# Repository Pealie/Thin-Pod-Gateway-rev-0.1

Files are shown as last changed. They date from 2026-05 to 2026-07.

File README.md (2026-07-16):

# Thin-Pod Gateway rev 0.1

<p align="left">
  <a href="https://certification.oshwa.org/uk000092.html">
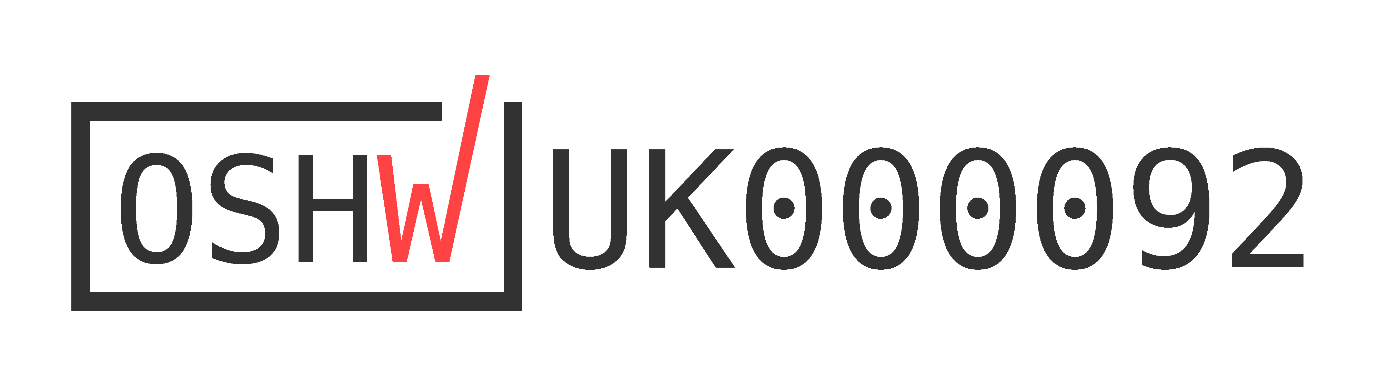
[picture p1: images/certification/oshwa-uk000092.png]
Open Source Hardware Association certification mark: UK000092
    
  </a>
</p>
<p align="left">
  <strong>OSHWA Certified Open Source Hardware · UK000092</strong><br>
  Certified 16 July 2026 · <a href="https://certification.oshwa.org/uk000092.html">View certification record</a>
</p>

**Open-hardware carrier PCB for Thin-Pod UWB telemetry, host supervision and onward-networking experiments**

## Status at 16 July 2026

Thin-Pod Gateway rev 0.1 is certified by the Open Source Hardware Association under UID [`UK000092`](https://certification.oshwa.org/uk000092.html). The certified public baseline is the `v0.1` release, with post-certification status and directory references maintained on `main`.

The manufactured `rev 0.1f` carrier board has completed stable powered bring-up with the STM32 NUCLEO-N657X0-Q and Gateway-side DWM3001-CDK. The repository records:

- verified 5 V and 3.3 V distribution and common-ground continuity;
- corrected marginal DWM header solder joints affecting ground and RESET;
- valid RESET and READY rail levels;
- repeatable bidirectional NUCLEO-to-DWM `TPHIP GET_CAPABILITIES` exchange;
- physical DW3110 identity and initialisation on Gateway and Node DWM3001-CDKs;
- a matched 20-frame Gateway-to-Node UWB exchange;
- published KiCad project, schematic and PCB source for revision `0.1`;
- published Gerber, drill and fabrication ZIP outputs;
- clean schematic ERC and PCB DRC reports;
- recorded Gerber and drill inspection;
- recorded symbol and footprint provenance;
- a reconciled design-basis BOM with builder-selected compatible assembly hardware.

## Relationship to the certified Thin-Pod node

The companion [`Pealie/Thin-Pod-rev0.1`](https://github.com/Pealie/Thin-Pod-rev0.1) sensor-node carrier PCB is separately certified as OSHWA Open Source Hardware, UID [`UK000091`](https://certification.oshwa.org/uk000091.html), certified 28 May 2026.

The two certifications describe distinct hardware artefacts:

| Hardware artefact | OSHWA UID | Certification date |
|---|---|---|
| Thin-Pod rev 0.1 sensor-node carrier PCB | [`UK000091`](https://certification.oshwa.org/uk000091.html) | 28 May 2026 |
| Thin-Pod Gateway rev 0.1 carrier PCB | [`UK000092`](https://certification.oshwa.org/uk000092.html) | 16 July 2026 |

The node UID applies only to the sensor-node carrier PCB. The Gateway UID applies only to the Gateway carrier PCB and its declared certification package.

## Hardware scope

Thin-Pod Gateway rev 0.1 is a two-layer carrier PCB connecting:

| Reference | Module | Role |
|---|---|---|
| `U1` | STMicroelectronics `NUCLEO-N657X0-Q` | Main host and prospective analysis supervisor |
| `U2` | Qorvo `DWM3001-CDK` | Gateway-side UWB subsystem |
| `U3` | Seeed Studio `XIAO ESP32-C6` | Optional onward-networking subsystem |

The creator-controlled open-hardware contribution is the carrier PCB: power distribution, local decoupling, pull-ups, module interfaces, SPI/control routing, test access, mounting geometry, editable source and derived fabrication outputs.

The commercial modules remain third-party products whose internal designs are outside the Gateway open-hardware claim.

## Verified evidence

| Milestone | Result | Evidence |
|---|---|---|
| Stable carrier-board bring-up | PASS | [`docs/bringup/Gateway_rev0_1_Hardware_Bringup_Note.md`](docs/bringup/Gateway_rev0_1_Hardware_Bringup_Note.md) |
| NUCLEO-to-DWM physical host interface | PASS | [`docs/firmware/TPHIP_GET_CAPABILITIES_Physical_Validation.md`](docs/firmware/TPHIP_GET_CAPABILITIES_Physical_Validation.md) |
| DW3110 identity and initialisation | PASS | [`docs/validation/DW3110_Physical_Identity_Initialisation_Validation.md`](docs/validation/DW3110_Physical_Identity_Initialisation_Validation.md) |
| Matched 20-frame one-way RF exchange | PASS | [`docs/validation/DW3110_One_Way_RF_Exchange_Validation.md`](docs/validation/DW3110_One_Way_RF_Exchange_Validation.md) |
| Native KiCad source | PUBLISHED | [`hardware/source/README.md`](hardware/source/README.md) |
| Fabrication package and hashes | PUBLISHED | [`hardware/fabrication/RELEASE-MANIFEST.md`](hardware/fabrication/RELEASE-MANIFEST.md) |
| Schematic ERC | PASS | [`docs/validation/cad/rev0.1/Thin-Pod_Gateway_rev0.1_ERC.rpt`](docs/validation/cad/rev0.1/Thin-Pod_Gateway_rev0.1_ERC.rpt) |
| PCB DRC | PASS | [`docs/validation/cad/rev0.1/Thin-Pod_Gateway_rev0.1_DRC.rpt`](docs/validation/cad/rev0.1/Thin-Pod_Gateway_rev0.1_DRC.rpt) |
| Gerber and drill inspection | PASS | [`docs/validation/cad/rev0.1/Gerber_Drill_Inspection_Record.md`](docs/validation/cad/rev0.1/Gerber_Drill_Inspection_Record.md) |
| Symbol and footprint provenance | RECORDED | [`docs/footprint-provenance.md`](docs/footprint-provenance.md) |
| Assembly BOM | RECONCILED | [`hardware/bom/Thin-Pod_Gateway_rev0.1_BOM.md`](hardware/bom/Thin-Pod_Gateway_rev0.1_BOM.md) |

## Design and fabrication identity

The manufactured board may carry `rev 0.1f`. This is retained as the physical fabrication-build identity within the certified Thin-Pod Gateway rev 0.1 release record.

Published native source:

```text
hardware/source/kicad/rev0.1/
```

Published manufacturing outputs:

```text
hardware/fabrication/rev0.1/
```

The release Gerber job records project revision `0.1`. The regenerated outputs preserve the intended electrical connectivity, board outline, mounting geometry, module-interface positions, test-point arrangement and layer content of the manufactured rev 0.1f carrier.

## Assembly interface treatment

Builder-selected pin headers and/or socket strips compatible with the NUCLEO-N657X0-Q ST Morpho interfaces, DWM3001-CDK J10 interface, and optional XIAO ESP32-C6 carrier footprint are suitable for assembly. Header brand, plating, socket style and standoff selection are assembly choices outside the carrier-PCB certification scope.

## Licences

| Material | Licence |
|---|---|
| Creator-designed hardware source and derived fabrication outputs | `CERN-OHL-W-2.0` |
| Project-authored firmware, scripts and software examples | `MIT` |
| Creator-authored documentation and owned images | `CC-BY-4.0` |
| Third-party modules, software and CAD | Original applicable terms |

These are the licence selections recorded for OSHWA certification UID `UK000092`.

See [`LICENSE.md`](LICENSE.md), [`LICENSE-HARDWARE.md`](LICENSE-HARDWARE.md), [`LICENSE-SOFTWARE.md`](LICENSE-SOFTWARE.md), [`LICENSE-DOCUMENTATION.md`](LICENSE-DOCUMENTATION.md), [`THIRD_PARTY_NOTICES.md`](THIRD_PARTY_NOTICES.md) and [`docs/footprint-provenance.md`](docs/footprint-provenance.md).

## OSHWA certification record

| Item | Record |
|---|---|
| Project | Thin-Pod Gateway |
| Hardware release | rev 0.1 |
| OSHWA UID | [`UK000092`](https://certification.oshwa.org/uk000092.html) |
| Certification date | 16 July 2026 |
| Canonical release tag | `v0.1` |
| Public application record | [`oshwa/application-record.md`](oshwa/application-record.md) |
| Certification scope | [`docs/certification-scope.md`](docs/certification-scope.md) |
| Certification completion checklist | [`docs/oshwa/Gateway_OSHWA_Preparation_Checklist.md`](docs/oshwa/Gateway_OSHWA_Preparation_Checklist.md) |

The OSHWA certification confirms the declared open-source hardware, software and documentation licensing position. It does not constitute EMC, radio, electrical-safety, CE, UKCA, industrial-performance or product-safety approval.

## Current limitations

The release does not claim Node-to-Gateway vibration-window transport, ranging, field-qualified RF performance, calibrated transmit power, antenna/coexistence performance, authenticated radio records, secure boot enforcement, production OTA, Gateway DSP/TinyML performance, EMC, radio, electrical-safety, CE or UKCA compliance.

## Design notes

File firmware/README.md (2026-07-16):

# Thin-Pod Firmware Workspace

**Project context:** Thin-Pod rev 0.1 sensor node and Thin-Pod Gateway rev 0.1<br>
**Firmware workspace status:** Prepared for initial acquisition and host-interface experiments; no completed firmware implementation claimed<br>
**Document date:** 27 May 2026<br>
**Certification status update (16 July 2026):** Thin-Pod rev 0.1 is OSHWA-certified as `UK000091`; Thin-Pod Gateway rev 0.1 is independently OSHWA-certified as `UK000092`

## Purpose

This directory is the firmware-development workspace for proving the first Thin-Pod measurement-data path:

```text
external ADXL1005 analogue vibration signal
        ↓
node-side DWM3001-CDK / nRF52833 firmware
bounded raw-window acquisition and later UWB transmission
        ↓
Gateway-side DWM3001-CDK / nRF52833 firmware
communications termination, validation and host presentation
        ↓
STM32 NUCLEO-N657X0-Q firmware
record ingestion, preservation, DSP and later TinyML evaluation
```

The immediate purpose of the firmware work is not to claim a complete condition-monitoring product. It is to remove the two largest implementation uncertainties:

1. whether the existing Thin-Pod node can create a useful digital raw window from the external ADXL1005 signal; and
2. whether the Gateway-side Qorvo subsystem can expose a complete validated record to the NUCLEO through the firmware-defined host interface intended by Gateway rev 0.1.

## Relationship to hardware releases and OSHWA scope

The firmware workspace must not blur the hardware certification boundaries.

|Hardware artefact|Current position|Firmware relationship|
|-|-|-|
|**Thin-Pod rev 0.1** sensor-node carrier PCB|OSHWA-certified as `UK000091`|This workspace may test firmware using that hardware; the node certification boundary remains unchanged|
|**Thin-Pod Gateway rev 0.1** carrier PCB|OSHWA-certified as `UK000092`|Project-authored firmware and software in this repository are declared under MIT within the Gateway certification record; external SDKs and vendor firmware retain their own terms|
|**Gateway rev 0.3** SMT/chip-down direction|Deferred|Not implemented in this workspace at present|

The Gateway hardware, software and documentation categories remain separately licensed. Project-authored firmware and software are covered by `LICENSE-SOFTWARE.md` under MIT, matching the software licence declared for UID `UK000092`. External SDKs, Zephyr components and vendor firmware remain under their original terms.

## Architectural responsibility split

|Firmware area|Hardware target|Immediate responsibility|Deliberately deferred responsibility|
|-|-|-|-|
|[`node-dwm/`](node-dwm/)|Node-side Qorvo DWM3001-CDK / nRF52833 connected to Thin-Pod|SAADC characterisation of external ADXL1005 path and bounded raw-record creation|Full event-trigger logic, multi-node policy and production-grade radio behaviour|
|[`gateway-dwm/`](gateway-dwm/)|Gateway-side Qorvo DWM3001-CDK / nRF52833|Present status and a golden synthetic record to the NUCLEO through the proposed host protocol|Full UWB reception until wired host hand-off succeeds|
|[`nucleo-host/`](nucleo-host/)|STM32 NUCLEO-N657X0-Q|Read, validate and preserve complete raw records; later perform minimal DSP|TinyML, cloud/backhaul reporting and complex user interface|
|[`test-vectors/`](test-vectors/)|Shared development assets|Provide deterministic record bytes and CRC reference behaviour|Dataset/training material|

The project’s governing data-path principle is:

```text
qualified raw measurement windows from the Pod;
validated UWB/host transfer through the DWM3001 subsystem;
features and later models on the Gateway.
```

## Directory structure

```text
firmware/
├── README.md
│
├── node-dwm/
│   ├── README.md
│   └── acquisition-characterisation/
│       └── README.md
│
├── gateway-dwm/
│   ├── README.md
│   └── tphip-golden-record/
│       └── README.md
│
├── nucleo-host/
│   ├── README.md
│   └── tphip-reader/
│       └── README.md
│
└── test-vectors/
    ├── README.md
    ├── golden-window-v1.bin              # to be generated from the reference script
    ├── golden-window-v1-metadata.md      # to be added with generated vector
    └── crc-reference.py                  # to be added as executable vector generator/checker
```

The README files define the intended implementation and evidence structure. The binary vector and reference script are next implementation assets; they are not implied to exist merely because their target paths are documented here.

## Controlling architecture documents

These firmware folders implement the architecture described in the repository documentation:

|Document|Controls|
|-|-|
|[`../docs/node-acquisition-and-sampling-contract.md`](../docs/node-acquisition-and-sampling-contract.md)|ADC qualification, sample-rate/bandwidth position and the later dedicated-ADC decision gate|
|[`../docs/dwm-to-nucleo-host-interface-protocol.md`](../docs/dwm-to-nucleo-host-interface-protocol.md)|`TPHIP-1` request/response, record layout, golden vector and ownership behaviour|
|[`../docs/data-path-flow-control-and-buffering.md`](../docs/data-path-flow-control-and-buffering.md)|Credit-based admission, DWM and NUCLEO queue policy and overrun prevention|
|[`../docs/window-throughput-and-airtime-budget.md`](../docs/window-throughput-and-airtime-budget.md)|Calculated record/transfer budget and later measurement tables|
|[`../docs/data-path-fault-injection-and-recovery-tests.md`](../docs/data-path-fault-injection-and-recovery-tests.md)|Failure tests needed to demonstrate visible error handling|
|[`../docs/measurement-record-and-provenance-model.md`](../docs/measurement-record-and-provenance-model.md)|Traceability from raw record through DSP and later TinyML|
|[`../docs/system-interface-control-document.md`](../docs/system-interface-control-document.md)|Node/Gateway responsibility boundary|

## First implementation sequence

The firmware should be developed in an evidence-first order.

|Phase|Target|Work|Completion evidence|
|-:|-|-|-|
|F0|Shared test assets|Generate the golden 4160-byte `SYNTHETIC\_WINDOW` record and CRC checker|Binary vector, metadata and deterministic script|
|F1|Gateway DWM|Implement minimal `TPHIP-1` capabilities/status presentation|Repeatable host-readable status record|
|F2|NUCLEO host|Implement SPI/IRQ reader for capabilities/status|Stable protocol discovery and status logging|
|F3|Gateway DWM + NUCLEO|Transfer the golden record over the wired host route|Exact reconstructed binary and CRC match|
|F4|Gateway DWM + NUCLEO|Withhold acknowledgement and exercise credit policy|Record-retention and no-overwrite evidence|
|F5|Node DWM|Configure SAADC and capture external ADXL1005 characterisation windows|Raw rest and mechanical-response records, marked uncalibrated|
|F6|Qorvo node/Gateway subsystems|Transfer a known record over UWB and deliver it into NUCLEO memory|RF-to-host record with integrity evidence|
|F7|Full node-to-Gateway chain|Deliver an actual ADXL1005-derived raw window|Accepted measurement record plus provenance|
|F8|NUCLEO|Compute RMS and peak, followed later by further DSP|Results linked to retained raw input|
|F9|Later|Consider TinyML only after repeatable datasets exist|Versioned model work linked to provenance|

Node acquisition and wired host-interface work can proceed in parallel where hardware availability permits. Neither requires the Gateway PCB to have arrived before useful preparatory progress begins.

## Initial record and buffer policy

The commissioning record defined by `TPHIP-1` is:

|Quantity|Initial value|
|-|-:|
|Message type|`SYNTHETIC\_WINDOW`, later `VIBRATION\_WINDOW`|
|Sample representation|Signed 16-bit little-endian|
|Samples per record|2048|
|Raw payload bytes|4096|
|Fixed header bytes|64|
|Complete record bytes|4160|
|Golden vector CRC-32|`0x0B1D48B2`|
|Gateway DWM complete-record slots|2 initially|
|NUCLEO raw-record slots|32 initially|
|Commissioning admission|One complete window at a time|

The 25.6 ksample/s value in the golden synthetic record is protocol metadata for deterministic testing; it is not a claim that a 25.6 ksample/s acquisition mode preserves the full ADXL1005 analogue bandwidth. Actual node acquisition requires the separate qualification process described in `node-acquisition-and-sampling-contract.md`.

## Evidence and record discipline

Each firmware experiment should produce identifiable evidence rather than transient console output.

Suggested working evidence pattern:

```text
verification/
├── firmware/
│   ├── node-acquisition/
│   ├── tphip-host-interface/
│   ├── uwb-transport/
│   └── dsp/
└── datasets/
    └── <session-id>/
        ├── session-manifest.json
        ├── raw/
        ├── ingestion/
        ├── dsp/
        └── evidence/
```

Every completed experiment should record the hardware revision/build, fitted modules, firmware build identities, protocol version, test configuration, raw record or exact test vector, integrity result and explicit pass/fail conclusion.

## Firmware toolchain position

The precise firmware toolchains and SDK/project templates should be recorded when the first projects are created. The likely development boundaries are:

|Target|Expected environment to confirm and record|
|-|-|
|DWM3001-CDK / DWM3001C nRF52833|Qorvo-supported DWM3001CDK/DWM3001C firmware environment and Nordic-compatible development/debug route|
|STM32 NUCLEO-N657X0-Q|STM32Cube ecosystem and NUCLEO-supported debugging/programming route|
|Shared test vector generation|Python reference tooling used only for deterministic test/evidence generation|

No dependency version should be treated as fixed until the corresponding firmware project is created, built, flashed and recorded.

## Non-claims

This directory does not yet claim:

* working node-side digital capture of the external ADXL1005 signal;
* working DWM-to-NUCLEO SPI protocol implementation;
* successful UWB transmission of vibration records;
* proven DSP performance;
* TinyML inference or predictive-maintenance capability;
* production-qualified firmware behaviour; or
* expansion of either certified hardware boundary beyond the public records for UIDs `UK000091` and `UK000092`.

## Immediate next action

The best first firmware actions are:

```text
1. Generate and commit the TPHIP-1 golden record test assets.
2. Establish the node-side DWM3001-CDK programming/build route.
3. Capture the first external-ADXL1005-derived bounded ADC record.
4. Establish the Gateway-side DWM ↔ NUCLEO minimum status exchange off-board where practical.
5. Use the arriving Gateway PCB to replace temporary wiring only after the firmware boundary is already understood.
```

A credible outcome before the Gateway PCB arrives would be one digitised ADXL1005 characterisation window, a committed golden test vector and at least the beginnings of a deterministic DWM-to-NUCLEO host-interface proof.

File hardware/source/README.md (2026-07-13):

# Editable hardware source

This directory contains the preferred modifiable source for Thin-Pod Gateway rev 0.1.

## Published KiCad project

The release source is stored at:

```text
hardware/source/kicad/rev0.1/
├── Thin-Pod Gateway.kicad_pro
├── Thin-Pod Gateway.kicad_sch
└── Thin-Pod Gateway.kicad_pcb
```

The schematic and PCB title blocks identify the design revision as `0.1`. The KiCad project and PCB fabrication-output paths use the repository-relative location:

```text
../../../fabrication/rev0.1/
```

This removes the private Windows/OneDrive path that was present in the working project before publication. No schematic connectivity, component placement, routing or board geometry was intentionally changed by that portability correction.

## Source status

The native KiCad source and corresponding Gerber/drill release package were committed on 13 July 2026. The earlier missing-source publication gate is therefore cleared.

The remaining release-verification work is:

1. open the project in a clean KiCad 10 environment;
2. confirm that no unavailable private symbol or footprint library is required;
3. run schematic ERC and PCB DRC;
4. inspect the generated Gerbers and drill data in a Gerber viewer;
5. record symbol and footprint provenance;
6. reconcile the fitted BOM and module-header/socket choices;
7. freeze the validated source and fabrication package under a public release tag.

The editable KiCad project is the normative design source. Gerbers, drill data and the fabrication ZIP are derived convenience outputs.

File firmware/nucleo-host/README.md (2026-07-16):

# NUCLEO Host Firmware: Gateway Analytic Supervisor

**Firmware area:** `firmware/nucleo-host/`<br>
**Hardware target:** STM32 NUCLEO-N657X0-Q mounted on Thin-Pod Gateway rev 0.1<br>
**Status:** Ingestion architecture specified; implementation and physical Gateway verification pending<br>
**Document date:** 27 May 2026<br>
**Primary role:** Authoritative admission control, raw-window ownership and later analysis

## Purpose

This directory is for firmware running on the **STM32 NUCLEO-N657X0-Q** in the Thin-Pod Gateway architecture.

The NUCLEO is intended to act as the analytic supervisor, not as a direct controller of the internal DW3110 radio. Its immediate job is to prove that a complete record exposed by Gateway-side DWM firmware can be pulled into NUCLEO-owned memory, checked for integrity, preserved and acknowledged correctly.

```text
Gateway-side DWM firmware
    complete record queued and ready
        ↓  TPHIP-1 SPI/IRQ host interface
NUCLEO host firmware
    admission control and complete raw-window buffer ownership
        ↓
minimal DSP sanity checks
        ↓
later feature extraction and TinyML evaluation
```

## Responsibility boundary

| NUCLEO owns | NUCLEO does not initially own |
|---|---|
| Host-interface command/read behaviour | DW3110 radio timing/control internals |
| Available raw-record buffer capacity | Node-side ADC qualification |
| Credit granting and backpressure decision | Uncontrolled incoming UWB streaming |
| Host-side CRC/metadata acceptance | Gateway DWM’s internal UWB reassembly implementation |
| Retention and processing scheduling | Optional XIAO reporting as a prerequisite for measurement receipt |
| Later DSP and TinyML execution | Any early predictive-maintenance performance claim |

The NUCLEO is the **authoritative admission controller** because it knows whether preserved raw-window capacity remains available for incoming measurements and downstream processing.

## Relationship to hardware and certification

Thin-Pod Gateway rev 0.1 is OSHWA-certified as `UK000092`, separately from the Thin-Pod rev 0.1 node certified as `UK000091`. Thin-Pod-authored NUCLEO firmware is licensed under MIT through `LICENSE-SOFTWARE.md` and is part of the declared Gateway software record. The commercial NUCLEO hardware and vendor software remain outside the Thin-Pod licence grants.

The commercial NUCLEO board is included as a dependency of the open Gateway carrier PCB; it is not claimed as creator-authored open hardware.

## Controlling documents

| Document | NUCLEO firmware requirement |
|---|---|
| `../../docs/dwm-to-nucleo-host-interface-protocol.md` | Implement `TPHIP-1` host/master transactions and golden record |
| `../../docs/data-path-flow-control-and-buffering.md` | Implement raw-record pool, credits and high-water policy |
| `../../docs/data-path-fault-injection-and-recovery-tests.md` | Implement observable handling of corruption/backpressure/reset faults |
| `../../docs/window-throughput-and-airtime-budget.md` | Measure host-transfer/queue/DSP timing |
| `../../docs/measurement-record-and-provenance-model.md` | Attach record/build/status identity to evidence |
| `../../docs/node-acquisition-and-sampling-contract.md` | Interpret actual sensor records cautiously and correctly |

## Directory structure

```text
nucleo-host/
├── README.md
└── tphip-reader/
    └── README.md
```

Potential implementation expansion:

```text
nucleo-host/
├── README.md
├── tphip-reader/
│   ├── README.md
│   └── evidence/
├── app/
│   ├── host-interface/
│   ├── raw-window-pool/
│   ├── dsp/
│   └── logging/
├── tests/
└── build-notes/
```

## Initial physical interface role

Gateway rev 0.1 connects the NUCLEO-side intended host route as follows:

| NUCLEO function | Gateway net | Purpose |
|---|---|---|
| SPI5 clock output | `SPI5_SCK` | Clock DWM host-interface transactions |
| SPI5 MOSI output | `SPI5_MOSI` | Send requests and dummy bytes during reads |
| SPI5 MISO input | `SPI5_MISO` | Receive status/header/payload bytes |
| GPIO chip select | `DWM_CS` | Select Gateway DWM host endpoint |
| GPIO interrupt input | `DWM_IRQ` | Observe record/status-ready notification |
| GPIO reset output | `DWM_RESET` | Controlled subsystem reset/recovery |

The intended first protocol uses NUCLEO as SPI host/master. Settings such as SPI mode, initial frequency and IRQ polarity remain commissioning values until measured on the firmware endpoints and assembled/temporary-wired hardware.

## First NUCLEO objective

The first NUCLEO objective is:

> **Read and validate the fixed 4160-byte `TPHIP-1` golden synthetic record from Gateway-side DWM firmware, then acknowledge ownership only after the bytes and CRC are accepted.**

This establishes the key modular boundary before actual UWB or ADXL1005 data is introduced.

## Host-interface task model

The NUCLEO firmware should separate ingress from all slower processing.

```text
DWM_IRQ GPIO event
        ↓
minimal interrupt handler sets service flag
        ↓
high-priority TPHIP receive task reads status/record
        ↓
record copied into allocated raw-window slot
        ↓
CRC/metadata/sequence checked
        ↓
ACK_WINDOW or REJECT_WINDOW sent
        ↓
accepted record placed in VALID_RAW queue
        ↓
DSP task consumes later
```

The interrupt handler must not perform bulk SPI reads, FFT calculation, TinyML inference, long logging operations or optional network reporting.

## Initial raw-window pool

The initial NUCLEO buffer policy is:

| Quantity | Initial value |
|---|---:|
| Complete record bytes | 4160 |
| Raw-window slots | 32 |
| Raw-record memory allocation | 133,120 bytes |
| Protected reserve | 4 free slots |
| First admitted-window policy | One outstanding credit at a time |

### Raw-window slot states

```text
FREE
    available for admitted record

FILLING
    SPI transfer in progress

VALID_RAW
    integrity/metadata accepted; available to downstream consumer

PROCESSING
    DSP task currently consuming record

PROCESSED_RETAIN
    retained because it supports evidence/result

RELEASED
    returned deliberately to free pool

INVALID_QUARANTINED
    rejected record retained for diagnosis as policy permits
```

### High-water admission policy

| Slots in use | State | Credit action |
|---:|---|---|
| 0–15 | Normal | Permit credit according to scheduler |
| 16–23 | Elevated occupancy | Continue cautiously and log latency |
| 24–27 | High-water warning | Withhold or severely restrict new credits |
| 28–31 | Protected reserve | No new measurement credit |
| 32 | Full | Reject unsolicited arrival as fault; never overwrite a valid raw record |

## TPHIP-1 host implementation stages

| Stage | Host-side feature | Pass criterion |
|---:|---|---|
| NH-0 | Establish build/debug route and firmware identity | NUCLEO build can run and identify itself |
| NH-1 | Configure GPIO and SPI host route | Safe idle state and observable intended signals |
| NH-2 | Read `GET_CAPABILITIES` / `GET_STATUS` | Stable valid responses from Gateway DWM |
| NH-3 | Service level `DWM_IRQ` outside lengthy ISR work | Pending status/record cannot be missed |
| NH-4 | Read golden descriptor/payload into one slot | Exact 4160-byte record reconstructed |
| NH-5 | Validate CRC and issue `ACK_WINDOW` | CRC equals `0x0B1D48B2`, DWM frees only after ACK |
| NH-6 | Deliberately withhold ACK | DWM retains unresolved record |
| NH-7 | Implement credit/high-water state | Admission stops before overwrite |
| NH-8 | Receive known UWB test record | RF-to-memory record accepted |
| NH-9 | Receive actual characterisation window | Sensor-derived raw record preserved |
| NH-10 | Calculate initial RMS/peak | Result links to retained raw record |

## Initial DSP boundary

DSP should begin only after a record has entered `VALID_RAW`.

| Processing stage | Purpose | Requirement |
|---|---|---|
| Mean/min/max/raw-range check | Detect offset/range/clipping anomalies | First actual characterisation record |
| RMS and peak / peak-to-peak | Basic time-domain sanity | Valid retained raw record |
| Crest factor and kurtosis | Initial impulsive-content measure | Repeatable acquisition/transport |
| FFT/band energy | Frequency-domain evidence | Sample rate/filter configuration qualified |
| Envelope work | Later fault-oriented analysis | Appropriate bandwidth and measurement data |
| TinyML | Much later model evaluation | Versioned dataset and provenance chain |

Early actual sensor records must remain labelled as characterisation/uncalibrated unless acquisition qualification supports stronger wording.

## Optional XIAO boundary

The XIAO ESP32-C6 is optional downstream reporting hardware. It is not required for the first NUCLEO host-interface or measurement-ingress proof.

For rev 0.1 testing:

```text
first ingress proof:     XIAO absent or inactive
later reporting test:    XIAO operations yield to DWM record servicing
```

Any XIAO task must not block reception or preservation of a validated measurement record.

## Evidence record requirements

| Evidence item | Record |
|---|---|
| Gateway hardware/build identity | Gateway PCB build or temporary-wired proof arrangement |
| NUCLEO hardware identity | NUCLEO board used |
| Firmware build identity | Source/build/tag |
| SPI/IRQ/reset configuration | Exact settings |
| TPHIP protocol version | `TPHIP-1` initially |
| Vector/record identity | Golden/synthetic/UWB/measurement and sequence |
| Queue state/counters | Before and after transfer/test |
| Integrity output | CRC and binary comparison where applicable |
| DSP output | Only where linked to valid raw record |
| Pass/fail | Explicit conclusion and noted limitations |

## Immediate next action

Before the Gateway PCB arrives, a strong NUCLEO task is to create the smallest host project that can:

1. configure the proposed SPI/GPIO route or a temporary-wired equivalent;
2. read a fixed capabilities/status response from Gateway-side DWM firmware; and
3. prepare the 4160-byte raw-buffer allocation and CRC validation needed for the golden-record transfer.

No DSP sophistication is required until the host-interface record hand-off is reliable.

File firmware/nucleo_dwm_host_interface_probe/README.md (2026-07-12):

# NUCLEO DWM Host Interface Probe

Runs on the STM32 NUCLEO-N657X0-Q and proves the first real host-interface exchange with the Gateway DWM3001-CDK.

The application:

- drives SPI5 at 1 MHz, mode 0, MSB first;
- uses PA3 as manual active-low CS;
- reads PB9 as DWM READY;
- resets the DWM through PD0 and releases the line as a high-impedance input;
- sends an exactly 16-byte `GET_CAPABILITIES` request;
- clocks an exactly 32-byte response;
- checks magic, version, flags, lengths, CRC, status, opcode and sequence;
- runs ten valid exchanges;
- checks unknown version, reserved flags, oversized payload, bad CRC and unknown opcode handling;
- runs a local valid-CRC sequence-mismatch parser self-test;
- uses fixed static buffers with guard words and no dynamic allocation.

## Supported complete-response diagnostic

The probe prints the complete 32-byte physical response immediately after it has been clocked:

```text
response_after_clock=54 50 47 57 ...
```

The hexadecimal dump permits direct comparison with the frozen TPHIP vectors and preserves the received bytes when a validation failure occurs.

This application is explicitly a host-interface validation probe, so the complete response dump is retained as supported output. It was present in the firmware used for the successful physical validation and keeps the committed source aligned with the tested build.

## Hardware acceptance result

One cold boot runs one complete suite. The acceptance target was three PoE power cycles, each producing ten valid exchanges and zero CRC, sequence, guard or READY failures.

That target was met on 12 July 2026. Each complete captured suite concluded:

```text
suite=GET_CAPABILITIES passes=16 failures=0 guard=OK result=PASS
```

The next Gateway milestone is a real DWM-to-DWM UWB RF exchange.

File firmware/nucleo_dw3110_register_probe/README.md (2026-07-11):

# NUCLEO DW3110 Register Probe

Purpose: perform the first Gateway-local DW3110 register-read probe over the verified SPI5 path.

Scope:

- no UWB RF
- no ranging
- no node-to-Gateway communication
- no production driver

Verified Gateway SPI5 path:

- TP7 / CS
- TP10 / SCK
- TP11 / COPI / MOSI
- TP12 / CIPO / MISO

The probe attempts a raw read of register 0 / DEV_ID and prints TX bytes, RX bytes and candidate 32-bit interpretations.

Expected DW3110-class value:

0xDECA0302

A zero or flat RX result is diagnostic evidence. It may indicate that additional DWM3001-CDK module routing, reset, wake or ownership steps are required before direct DW3110 access works from the NUCLEO.

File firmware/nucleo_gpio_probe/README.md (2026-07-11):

# Thin-Pod Gateway NUCLEO GPIO Probe

Minimal Zephyr GPIO-only probe for the Thin-Pod Gateway rev 0.1 NUCLEO-N657X0-Q supervisor.

## Scope

This app proves only:

- `PD0 -> DWM_RESET`
- `PA3 -> DWM_CS`
- `PB9 <- DWM_IRQ`

It deliberately avoids SPI, DW3110 register access and UWB RF behaviour.

## Expected serial output

```text
Thin-Pod Gateway rev0.1 NUCLEO GPIO probe
Board: nucleo_n657x0_q
Purpose: RESET / CS / IRQ pin-path confirmation only
No SPI. No DW3110 register access. No UWB RF.

DWM_RESET / PD0 ready: controller=... pin=0
DWM_CS / PA3 ready: controller=... pin=3
DWM_IRQ / PB9 ready: controller=... pin=9
GPIO configuration complete
probe=0 phase=LOW reset=0 cs=0 irq=...
probe=0 phase=HIGH reset=1 cs=1 irq=...
```

## Acceptance boundary

The firmware heartbeat alone is not Gateway PCB proof. The acceptance evidence is RESET and CS toggling at the DWM3001-CDK header, and IRQ being read consistently by firmware.

Measure:

| Signal | NUCLEO pin | DWM3001-CDK header | Expected |
|---|---:|---:|---|
| RESET | PD0 | J10.12 | toggles low/high |
| CS | PA3 | J10.24 | toggles low/high |
| IRQ | PB9 | J10.15 | readable input level |

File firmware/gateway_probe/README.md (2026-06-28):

\# Thin-Pod Gateway SPI5/GPIO Probe App

This minimal firmware app supports Gateway completion checklist item 3: minimal SPI/GPIO probe app.

The purpose is to verify that the Thin-Pod Gateway rev 0.1 PCB allows firmware-level control of the DWM3001-CDK interface pins.

This app is intentionally limited to:

\- boot banner output;

\- DWM reset GPIO toggle;

\- DWM chip-select GPIO toggle;

\- DWM IRQ GPIO read;

\- minimal SPI5 transmit activity.

This app is not a DW3110 driver and does not claim full UWB operation.

\## Expected probe evidence

A successful probe should produce evidence that:

\- firmware starts successfully;

\- DWM\_RESET can be driven low and high;

\- DWM\_CS can be driven low and high;

\- DWM\_IRQ can be sampled as an input;

\- SPI5 can transmit a short test frame while CS is asserted.

\## Completion checklist link

This app directly supports:

\- Item 3: minimal SPI/GPIO probe app

It also supports:

\- Item 2: final verified pin map

\- Item 7: validation log

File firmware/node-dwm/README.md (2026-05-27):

# Node DWM Firmware: ADXL1005 Acquisition and Node-Side Window Creation

**Firmware area:** `firmware/node-dwm/`  
**Hardware target:** Node-side Qorvo DWM3001-CDK / DWM3001C nRF52833 interfaced by Thin-Pod rev 0.1  
**Status:** Firmware work planned; digital acquisition not yet demonstrated  
**Document date:** 27 May 2026  
**Measurement role:** Create bounded raw vibration-window records from the external ADXL1005 analogue path

## Purpose

This directory is for firmware running on the **node-side Qorvo DWM3001 subsystem** used with Thin-Pod. Its first responsibility is to determine whether the existing node hardware can digitise the external ADXL1005 analogue output into a stable and useful raw sample window.

The node-side firmware is not initially responsible for sophisticated DSP or TinyML. Its proper early role is:

```text
external ADXL1005 analogue output
        ↓
nRF52833 SAADC acquisition under controlled conditions
        ↓
bounded raw sample window with explicit metadata and integrity field
        ↓
later UWB transmission under Gateway admission control
```

The acquisition work is central because a perfectly transported buffer is not valuable if the source samples are aliased, clipped, noisy or undocumented.

## Hardware and measurement boundary

The primary measurement source is the **external ADXL1005-based signal path on Thin-Pod**, not the lower-bandwidth motion sensor present within the DWM3001C module.

| Source | Firmware treatment |
|---|---|
| External ADXL1005 analogue channel connected through the Thin-Pod ADC node to the DWM/nRF52833 interface | Primary raw vibration-measurement channel to be qualified |
| DWM3001C integrated motion sensor | Auxiliary only; may later support wake-up/orientation/health functions but is not a substitute for the external vibration channel |

Existing analogue bring-up evidence for Thin-Pod rev 0.1 includes an approximately 3.35 V switched sensor supply, approximately 1.76 V resting filtered analogue node and a visible oscilloscope response to tapping. This firmware directory begins the next stage: capturing those signals digitally and assessing their quality.

## Relationship to certification scope

Thin-Pod rev 0.1 has been submitted as an open-hardware sensor-node carrier PCB. Firmware developed in this folder is continuing system-development material and does not retroactively expand that submitted hardware certification scope.

Before any node firmware is publicly released as a formally maintained software deliverable, it must be licensed separately under an appropriate software licence and identified by build/version metadata.

## Controlling specification

The controlling acquisition document is:

```text
docs/node-acquisition-and-sampling-contract.md
```

That document states the engineering gate:

> The nRF52833 SAADC may be used for initial bounded-window characterisation and may qualify for a restricted measurement band, but full use of the ADXL1005’s approximately 20–23 kHz low-noise capability must not be claimed without convincing filtering, timing, noise and alias evidence.

Relevant related documents are:

| Document | Use by node firmware |
|---|---|
| `../../docs/node-acquisition-and-sampling-contract.md` | ADC qualification and retain-or-replace acquisition decision |
| `../../docs/dwm-to-nucleo-host-interface-protocol.md` | Complete-record format eventually consumed by the Gateway |
| `../../docs/data-path-flow-control-and-buffering.md` | Later window-admission and backpressure behaviour |
| `../../docs/measurement-record-and-provenance-model.md` | Metadata and traceability requirements |

## Directory structure

```text
node-dwm/
├── README.md
└── acquisition-characterisation/
    └── README.md
```

As implementation develops, a sensible expanded layout is:

```text
node-dwm/
├── README.md
├── acquisition-characterisation/
│   ├── README.md
│   ├── configurations/
│   ├── captures/
│   └── evidence/
├── app/
│   ├── acquisition/
│   ├── record-format/
│   └── transport/
├── tests/
└── build-notes/
```

The project structure may be adapted to the selected Qorvo/Nordic-compatible build environment, but source responsibility and evidence must remain clear.

## First firmware objective

The first firmware objective is not UWB transmission. It is:

> **Capture a bounded digital record from the external ADXL1005 channel using the node-side nRF52833 SAADC, and preserve it as `CHARACTERISATION / UNCALIBRATED` evidence.**

Minimum first records:

| Record | Condition | Why required |
|---|---|---|
| Resting/DC sanity record | Stationary sensor, known rail voltage, radio inactive | Maps analogue rest output to ADC codes and detects clipping/configuration errors |
| Quiet/background record | Stable resting sensor, radio inactive | Begins combined sensor/ADC/supply noise characterisation |
| Mechanical-response record | Controlled tap or simple excitation | Confirms the digital path records the previously observed analogue response |
| Radio-comparison record | Capture under or near radio activity, once feasible | Assesses whether capture and UWB transmission must be time-separated |

## nRF52833 SAADC qualification concerns

| Qualification issue | Firmware evidence required |
|---|---|
| Correct ADC input routing | Source pin/net and configured SAADC input recorded |
| Reference/gain/input range | Firmware configuration plus conversion calculation |
| Resting code and voltage relation | Paired ADC code and multimeter/oscilloscope observation |
| Clipping margin | Excitation/input tests and flags where clipping detected |
| Sampling stability | Timer/EasyDMA/event configuration and missing-sample checks |
| Noise floor | Captured raw record plus derived RMS/spectrum |
| Aliasing/filter compatibility | Defined analogue filtering and frequency-response testing |
| Radio contamination | Paired captures with radio inactive and active/adjacent activity |

The node’s existing approximately 29.3 kHz single-pole analogue filter is suitable bring-up evidence but not yet a final anti-alias strategy for high-bandwidth measurement.

## Sampling strategy

### Synthetic versus measured records

Synthetic records may use sample-rate fields solely to test protocol behaviour. Real ADXL1005-derived records must state the actual acquisition configuration and qualification status.

| Record type | Permitted purpose | Measurement claim |
|---|---|---|
| `SYNTHETIC_WINDOW` | Byte/CRC/protocol verification | No physical measurement claim |
| `UWB_TEST_WINDOW` | Radio/transport proof | No sensor-quality claim unless sourced from qualified acquisition |
| `VIBRATION_WINDOW` with `CHARACTERISATION` state | First actual ADXL1005 captures | Uncalibrated engineering evidence only |
| `VIBRATION_WINDOW` with qualified-band configuration | Later stated-band experiments | Only after supporting evidence exists |

### Candidate acquisition modes

| Sample-rate class | Initial role |
|---:|---|
| Low/restricted-band configuration | First measured captures where filtering and interpretation remain unambiguous |
| 51.2 ksample/s-class mode | Candidate for moderate/high-band characterisation, not automatically qualified |
| Up to 200 ksample/s single-channel characterisation | Candidate for examining alias/spur/noise behaviour within nRF52833 SAADC capability |

The final selection depends on measured ADC behaviour and appropriate analogue filtering.

## Initial raw-window record target

Where the acquisition record is aligned with the Gateway protocol commissioning format:

| Field | Initial target |
|---|---:|
| Sample format | Signed 16-bit little-endian representation of ADC values |
| Samples per record | 2048 |
| Raw payload size | 4096 bytes |
| Header size | 64 bytes |
| Total record size | 4160 bytes |
| Message type for first sensor captures | `VIBRATION_WINDOW` |
| Calibration state | `CHARACTERISATION` / uncalibrated |
| Required flags | State clipping, test source, incomplete capture or unknown calibration where applicable |

A raw ADC record may initially preserve ADC codes rather than calibrated `g` units. That is the correct evidence position until scaling and calibration have been established.

## Later node-to-Gateway transport role

After digital acquisition is demonstrated, node firmware may implement bounded-window UWB transfer governed by Gateway admission.

Intended sequence:

```text
Gateway grants one window opportunity
        ↓
Node captures or selects one complete bounded record
        ↓
Node frames and transmits the record over UWB
        ↓
Gateway-side DWM validates and presents it to NUCLEO
```

For first proof, node firmware should not transmit uncontrolled continuous raw streams and should not implement event-triggered queuing before the simpler admitted-window path has been demonstrated.

## Evidence record requirements

Every actual sensor capture retained for evaluation should identify:

| Required item | Example or status |
|---|---|
| Node hardware revision | `TP-NODE-R0.1` |
| Physical node instance | Assign when first digital test is made |
| DWM/CDK instance | Record module identity where practical |
| Node firmware build | Commit/build/tag |
| ADC input/reference/gain configuration | Exact firmware setting |
| Sample rate and sample count | Exact values |
| Analogue filter version/values | Thin-Pod rev 0.1 path or later revision |
| Sensor/channel identity | External ADXL1005 channel |
| Radio state during capture | Inactive, active or adjacent transmit event |
| Qualification state | `CHARACTERISATION`, initially |
| Raw record CRC/hash | Integrity and archive identity |
| Notes | Mounting, excitation and anomalies |

## Acceptance gate for first success

The first node-side firmware milestone passes when:

1. the external ADXL1005 ADC path is mapped unambiguously into firmware;
2. one 2048-sample digital raw record is captured from the external sensor path;
3. rest and mechanical-response records are retained with acquisition settings;
4. no unexplained clipping or buffer/timing failure occurs; and
5. the evidence is labelled as characterisation data rather than calibrated diagnostic measurement.

This does not prove full-bandwidth measurement quality. It proves that Thin-Pod can create real candidate raw data for subsequent transport and qualification.

## Deferred work

Do not prioritise the following until first characterisation records exist:

- TinyML on the node;
- large DSP feature sets on the node;
- event-triggered local queueing;
- multi-node scheduling;
- continuous streaming;
- firm claims about 20–23 kHz measurement performance; or
- a decision to eliminate the possibility of a later dedicated ADC.

## Immediate development checklist

| Task | Status |
|---|---|
| Establish and record DWM3001-CDK/nRF52833 build and flash route | Pending |
| Confirm external ADC pin and SAADC channel | Pending |
| Record first reference/gain/sample-rate configuration | Pending |
| Capture rest/DC record | Pending |
| Capture mechanical-response record | Pending |
| Capture baseline-noise record | Pending |
| Compare capture during radio activity when available | Pending |
| Save raw records and acquisition metadata | Pending |
| Decide candidate restricted-band qualification plan | Pending |

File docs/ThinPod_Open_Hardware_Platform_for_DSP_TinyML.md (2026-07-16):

# Thin-Pod Gateway and Node Platform: Hardware Boundaries, Reference Firmware and the DSP / TinyML Interface

## Executive summary

The recent Thin-Pod Gateway and node work clarifies a central proposition: the project is not merely an open hardware vibration sensor, nor is it yet a complete predictive-maintenance analytics product. Its strongest and most defensible identity is as an **open hardware vibration-window platform**. It provides the sensing, carrier-board, Gateway, module-interconnect, firmware bring-up and data-exposure path required to let practitioners begin work at the DSP and TinyML boundary rather than at the PCB, RF, power-integrity or board-support layer.

That distinction matters. Many technically capable practitioners, especially those coming from IT, software, data science or machine-learning backgrounds, do not want first to become embedded-hardware developers. They do not want to design a sensor carrier, debug power rails, reflow headers, recover J-Link probes, decipher UWB development-module wiring, or establish from first principles whether an accelerometer signal path is credible. They want a documented stream of vibration windows, with enough integrity metadata and reproducibility evidence that they can begin modelling almost immediately.

Thin-Pod’s opportunity is therefore not to prescribe the final model. It is to provide the reliable, open path to model-ready vibration data.

The concise platform thesis is:

```text
Thin-Pod provides the open hardware and reference firmware needed to acquire,
transport and expose vibration-window data. Downstream DSP, TinyML models and
diagnostic interpretations are intentionally left as user-developed layers above
the documented interface.
```

This is not a narrowing of the project. It is a strengthening of it. It defines what the platform is for, where the OSHWA hardware boundary lies, why the firmware is included, and what remains properly outside the certification claim.

## From hardware object to data-access platform

The practical insight that emerged from discussion with an IT professional was simple but important: the user does not necessarily want ‘a hardware project’. They want the hardware to get out of the way.

For such a practitioner, the value of Thin-Pod lies in allowing the following workflow:

```text
Build or obtain the open node and Gateway hardware.
Flash the reference firmware.
Run the Gateway logger.
Receive timestamped vibration windows in a documented format.
Start DSP, feature extraction and TinyML experimentation.
```

That means the platform’s essential output is not a polished dashboard, not a finished industrial classifier, and not a proprietary predictive-maintenance service. Its essential output is a trustworthy, documented vibration-window stream.

A minimal useful output might be expressed as:

```text
timestamp\_ms,node\_id,sequence,sample\_rate\_hz,sample\_count,accel\_mg\[]
```

or as a structured Gateway packet log:

```text
TPGW\_PKT seq=<n> src=0x0001 dst=0x0000 uptime\_ms=<t>
samples=<n> rate=<hz> checksum=<value> rms\_mg=<value>
```

That is the hand-off point. Below it is hardware, firmware, transport and measurement integrity. Above it is signal processing, modelling, inference and interpretation.

The project’s value is therefore not only that it is open hardware. It is that the open hardware is organised to produce a clean computational boundary.

## The modular stack

The most useful way to understand the Thin-Pod Gateway and node platform is as a layered system:

```text
Open hardware node and Gateway platform
    ↓
reference firmware for bring-up and operation
    ↓
UWB or staged transport layer
    ↓
shared packet contract
    ↓
Gateway packet logging and parser/export tools
    ↓
documented vibration-window interface
    ↓
user-developed DSP and TinyML
    ↓
diagnostic interpretation, dashboard or service layer
```

The essential discipline is to avoid collapsing these layers into a single vague claim. Each layer should have a role, evidence standard and boundary.

The hardware layer provides the physical sensing, carrier-board, power, signal, module and test-point infrastructure. The firmware layer proves and operates the board sufficiently to produce or transport vibration windows. The packet layer defines what is being handed off. The logging and parser layer makes the hand-off usable by a practitioner. The DSP and TinyML layer sits above that hand-off, where different users can develop different methods. The diagnostic layer, if any, is still higher again and should not be confused with either OSHWA certification or basic platform capability.

## OSHWA boundary for Gateway rev 0.1

Thin-Pod Gateway rev 0.1 is OSHWA-certified under UID `UK000092`. The certified hardware object is the **creator-designed Gateway carrier PCB and its open hardware documentation**. The certification package includes the KiCad design source, schematics, PCB layout, fabrication outputs, BOM, footprint provenance, release manifest, interface documentation, test-point information and bring-up evidence.

The third-party development modules remain outside the hardware certification claim. The Gateway carrier board may host or interconnect a Qorvo DWM3001-CDK, an STM32 NUCLEO-N657X0-Q and a Seeed Studio XIAO ESP32-C6, but it does not claim those commercial modules as open hardware.

The firmware and software should be described as **open reference bring-up, verification and interface software**. It supports reproducibility and makes the intended architecture inspectable. It should not be described as the certified hardware object itself.

A suitable boundary statement is:

```text
The certified hardware scope is the Thin-Pod Gateway rev 0.1 carrier PCB,
including its editable design source, fabrication outputs, BOM, interface
documentation, footprint provenance and bring-up evidence.

Project-authored firmware and software in this repository are provided as open
reference, bring-up and verification material. This includes Zephyr RTT
alive-test firmware, staged UWB responder / initiator scaffolding, packet
logging, vibration-window ingestion and optional DSP / TinyML reference
examples.

The DSP / TinyML layer is included only to demonstrate possible downstream
processing of preserved vibration windows. It is not part of the certified
hardware object, does not constitute a production diagnostic claim and does not
certify industrial fault-detection performance.
```

This position is clear without becoming evasive. It says what is open, what is evidenced, and what is not being claimed.

## Firmware and software as reference infrastructure

The current Gateway repository now contains two important firmware layers.

The first is the Zephyr RTT alive-test baseline:

```
firmware/gateway/zephyr_rtt_alive/
firmware/node/zephyr_rtt_alive/
```

These applications prove the basic development loop: build, flash, execute and observe over SEGGER RTT.

The second is the staged UWB role harness:

```text
firmware/common/thinpod_protocol/
firmware/gateway/uwb_initiator/
firmware/node/uwb_responder/
tools/packet_logging/
```

This establishes firmware identities, a shared packet contract, synthetic vibration-window generation, Gateway packet logging and parser-ready ingestion. It does not yet claim real DW3110 RF exchange.

For rev 0.1, this is an ideal stage of maturity. It shows serious system architecture without overclaiming. The firmware is not decorative, but neither is it presented as a finished industrial analytics stack.

The proper phrase is:

```text
reference bring-up and verification firmware
```

or, more fully:

```text
project-authored reference firmware and software for bring-up, verification,
interface testing and reproducibility of the intended Gateway architecture
```

## DSP / TinyML reference layer

A completed DSP / TinyML reference layer can also fit inside this boundary, provided it is described carefully.

It should be framed as a **reference example layer above the vibration-window interface**, not as a certified diagnostic system.

Appropriate content would include:

```text
RMS, peak and peak-to-peak examples
crest factor
kurtosis
FFT band-energy examples
envelope-feature examples
synthetic or sample vibration-window processing
TinyML inference demonstration using clearly labelled test data
parser and feature-extraction scripts
repeatable example outputs
```

Riskier language should be avoided unless field validation has actually been carried out:

```text
detects bearing failure
validated predictive-maintenance AI
certified diagnostic model
production TinyML condition-monitoring engine
industrial fault-detection performance
```

The strongest phrasing is:

```text
DSP and TinyML reference examples are included to exercise the Gateway data path
after packet capture and vibration-window ingestion. They are provided for
reproducibility, experimentation and verification of software interfaces. They
are not required to fabricate the Gateway PCB, are not part of the certified
hardware design and do not constitute validated diagnostic or industrial
condition-monitoring claims.
```

This keeps the project useful to ML practitioners while avoiding an inflated certification claim.

## Minimum open platform for DSP and TinyML practitioners

The minimum useful platform is not the entire algorithmic stack. It is the reliable production of documented vibration windows.

For the node, the minimum useful open hardware and firmware offering is:

```text
documented sensor power and signal chain
documented accelerometer output route
documented sampling assumptions
documented UWB/module interface
test points and bring-up checks
reference firmware for producing or emulating a vibration window
```

For the Gateway, the minimum useful open hardware and firmware offering is:

```text
documented UWB/module interface
documented host/supervisor route
documented power and ground behaviour
reference firmware for receiving or emulating vibration windows
Gateway packet logging
parser/export tool
test vectors and sample logs
```

Together, these allow a practitioner to begin at the data boundary:

```text
node/Gateway platform
    ↓
vibration-window stream
    ↓
CSV / JSON / packet log
    ↓
notebook / Python / DSP / ML toolchain
```

The practitioner should not have to solve the sensing platform before developing the model.

A practitioner-facing value statement could be:

```text
Thin-Pod Gateway and node hardware provide an open route from physical vibration
sensing to documented vibration-window data. The platform is intended to let
researchers, engineers and ML practitioners focus on DSP, TinyML and diagnostic
experimentation without first having to design the sensor carrier, Gateway
carrier, module interconnect, packet format or bring-up path.
```

That is a strong and accurate description of the platform’s utility.

## Rev 0.1 versus rev 0.3

For Gateway rev 0.1, the firmware is most safely described as reference bring-up and verification software. The hardware object is a carrier PCB around commercial modules. Real RF transport, host transfer, ADXL1005 vibration-window movement, DSP and TinyML remain staged or future verification layers unless completed and documented.

For a future rev 0.3, especially if the project moves toward castellated DWM3001C integration, SMT implementation, or a more product-like board, the firmware boundary changes. Firmware required for basic operation becomes more central to the release.

The shift is:

```text
rev 0.1:
open hardware carrier PCB + reference firmware scaffolding

rev 0.3:
integrated hardware platform + required open operating and verification firmware
```

For rev 0.3, the minimum firmware package may need to include board support, pin configuration, radio initialisation, UWB responder/initiator roles, packet framing, host-interface transfer, diagnostic logging and factory/bring-up tests.

The certification still need not claim the whole analytics stack. But the firmware needed to operate and reproduce the board’s basic behaviour becomes part of the platform evidence.

A future rev 0.3 boundary statement might read:

```text
Thin-Pod Gateway rev 0.3 includes project-authored open firmware and software
required for hardware bring-up, UWB role operation, packet validation,
host-interface verification and diagnostic logging. These files are included as
part of the reproducibility evidence for the open hardware release. The certified
hardware scope does not extend to third-party modules, vendor SDK internals,
cloud services, production analytics, or diagnostic claims beyond the documented
verification tests.
```

## What the platform should not claim

The project should continue to avoid claiming more than the evidence supports.

It should not claim that OSHWA certification validates predictive-maintenance accuracy. It should not imply that Qorvo, ST, Nordic, Espressif or Seeed hardware and SDKs are themselves covered by the project’s open hardware claim. It should not imply that TinyML examples are production diagnostics.

The platform can legitimately claim:

```text
open hardware carrier-board design
documented sensing and Gateway architecture
reference firmware and software for bring-up and verification
packet contract
Gateway logging path
vibration-window ingestion boundary
basis for downstream DSP / TinyML development
```

It should avoid claiming:

```text
validated industrial fault diagnosis
certified analytics performance
complete production UWB system, unless and until completed
certified third-party development modules
end-to-end predictive-maintenance product
```

This discipline is not mere caution. It is what makes the project more credible.

## The strategic identity of Thin-Pod

The strongest strategic identity for Thin-Pod is:

```text
an open hardware vibration-window platform for DSP and TinyML development
```

Or, more fully:

```text
Thin-Pod is an open hardware platform intended to move physical vibration
measurements into a documented, reproducible data interface, so that researchers
and practitioners can develop their own DSP, TinyML and diagnostic methods above
the hardware boundary.
```

This framing places the project in a useful middle position. It is more than a PCB. It is less than an overclaimed AI diagnostic appliance. It is an enabling layer.

The phrase ‘model-ready data’ is useful if handled carefully. It should not mean ‘validated model’. It should mean that the hardware and firmware expose data in a form suitable for modelling.

A safe phrase is:

```text
documented vibration-window interface for downstream DSP and TinyML development
```

Another is:

```text
open hardware route to model-ready vibration-window data
```

## Conclusion

The core insight is that Thin-Pod’s value lies in the boundary it creates. It lets one party do the hard work of open sensing hardware, carrier-board design, Gateway integration, firmware bring-up, packet framing and data exposure, so another party can begin at the DSP and TinyML layer.

That is not a weakness in the project. It is the project’s best product definition.

The Gateway and node platform should therefore be presented as a trustworthy open hardware path to vibration-window data. The reference firmware and software make that path reproducible. The DSP and TinyML layer remains open-ended, user-developed and deliberately above the certification boundary.

The most compact formulation is:

```text
The product is not the model.
The product is the reliable open path to model-ready vibration data.
```

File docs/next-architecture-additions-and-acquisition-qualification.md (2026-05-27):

# Thin-Pod Gateway rev 0.1: Next Architecture Additions and Acquisition Qualification Gate

**Document identifier:** `TP-GW-ARCH-0002`  
**Document revision:** Draft A  
**Product context:** Thin-Pod rev 0.1 sensor node and Thin-Pod Gateway rev 0.1  
**Document status:** Planning and architecture-development record  
**Document date:** 27 May 2026  
**Certification boundary:** This document supports future Gateway work and does not expand the submitted OSHWA scope of Thin-Pod rev 0.1.

## 1\. Purpose

The Gateway data-path and flow-control architecture now addresses how accepted vibration-window records should be transferred, buffered and protected against silent loss. The next major engineering question occurs earlier in the chain:

> \*\*Can the Thin-Pod node create a diagnostically credible digital vibration window from the external ADXL1005 analogue signal before that record is transported to the Gateway?\*\*

A successful UWB transport path is not sufficient on its own. Raw records delivered perfectly to Gateway memory remain of limited value if the initial sampling process is clipped, aliased, excessively noisy, poorly timed or inadequately described.

The next phase of the project should therefore qualify acquisition before placing emphasis on larger communications throughput, DSP feature claims or TinyML experiments.

## 2\. Principal conclusion

The system architecture remains sound, but its wording should be strengthened:

> \*\*Raw measurement windows from a qualified Pod acquisition chain; UWB transport handled by the DWM3001 subsystem; analysis performed on the Gateway.\*\*

This replaces any premature assumption that the nRF52833 ADC route is already sufficient for the full intended vibration-measurement use case. The node-side DWM3001 subsystem remains a valid candidate for acquisition and transport; its acquisition quality must now be tested rather than presumed.

## 3\. Why acquisition qualification is now the critical missing layer

The intended measurement path is:

```text
External ADXL1005 analogue vibration output
        ↓
Thin-Pod analogue conditioning / ADC node
        ↓
node-side DWM3001-CDK / DWM3001C nRF52833 acquisition firmware
        ↓
framed raw vibration window
        ↓
UWB transport
        ↓
Gateway-side DWM3001 subsystem
        ↓
NUCLEO-owned raw-window memory
        ↓
DSP and later TinyML
```

Existing Thin-Pod prototype evidence has already established analogue proof of life after the pre-release ground-return correction: the switched sensor supply was measured at approximately 3.35 V, the filtered analogue output was approximately 1.76 V at rest, and mechanical tapping produced a visible oscilloscope response.

What remains unestablished is whether the analogue signal can be **digitised with measurement quality appropriate to vibration analysis**.

## 4\. Relevant component facts

Analog Devices specifies the ADXL1005 as a single-axis analogue-output accelerometer with a ±100 g full-scale range, typical linear frequency response from DC to 23 kHz at the −3 dB point, and typical noise density of 75 µg/√Hz. Analog Devices also states that the EVAL-ADXL1005Z evaluation board provides a simple RC low-pass output filter with an approximately 20 kHz −3 dB bandwidth.

Qorvo specifies that the DWM3001C includes a Nordic nRF52833 BLE SoC and a motion sensor, and supports UWB data rates of 850 kbps and 6.8 Mbps. Nordic specifies the nRF52833 as including 128 KB RAM and a 12-bit ADC capability.

These specifications support a serious acquisition experiment. They do not by themselves establish ADC noise performance, analogue input-range margin, sampling timing quality or anti-alias suitability in the Thin-Pod assembly.

## 5\. External measurement channel versus internal module sensor

The system must distinguish between the intended measurement channel and the motion sensor integrated in the Qorvo module.

|Sensing element|Proposed role in Thin-Pod architecture|Measurement status|
|-|-|-|
|External ADXL1005-based Thin-Pod analogue channel|Primary vibration-measurement path for raw diagnostic windows|Must be digitally qualified|
|DWM3001C integrated motion sensor|Possible later wake-up, motion-presence, orientation or enclosure-health function|Not a substitute for the external high-bandwidth vibration channel|

The external ADXL1005 is the sensor associated with the project’s condition-monitoring and high-bandwidth vibration-analysis ambition. Any internal low-power motion sensor in the communications module should remain auxiliary unless separately characterised for a defined purpose.

## 6\. New document required: node acquisition and sampling contract

Add the following file to the wider project or Gateway documentation set:

```text
docs/node-acquisition-and-sampling-contract.md
```

Its governing question should be:

> Can the node-side DWM3001/nRF52833 acquisition route digitise the external ADXL1005 analogue signal as a repeatable, unclipped and diagnostically useful digital vibration window?

The document should specify and then record measurements in four areas.

|Qualification area|Required definition or measurement|
|-|-|
|Measurement source|Confirm external ADXL1005 path as the raw vibration channel; identify exact input net and node-side ADC pin/interface|
|ADC electrical compatibility|Measure rest bias, maximum expected excursion, supply/reference relation, configured ADC gain/range, clipping margin and any required protection or scaling|
|Sampling contract|Define initial sample rates, sample count, timer/PPI/DMA or equivalent sampling method, buffer ownership, missing-sample detection and metadata|
|Signal-quality qualification|Measure shorted/quiet noise floor where feasible, resting-sensor noise, known-frequency response, clipping behaviour, mechanical-excitation response and later comparison with a reference capture|

## 7\. ADC electrical-compatibility questions

Before treating the node as a digital vibration instrument, the following must be established.

|Question|Evidence required|
|-|-|
|Which nRF52833 ADC input receives the Thin-Pod conditioned signal?|Verified schematic/pin-map entry and firmware pin assignment|
|What is the sensor output bias at rest?|Measured value recorded under known supply conditions|
|What ADC input range and gain are configured?|Firmware configuration and calculated full-scale limits|
|Does the expected ADXL1005 excursion remain inside the ADC range?|Calculation followed by measured mechanical stimulus tests|
|Does the input require attenuation, buffering or clamp protection?|Review against maximum expected signal and measured clipping behaviour|
|Is the ADC referenced in a way compatible with the sensor’s ratiometric output?|Supply/reference stability and scaling analysis|
|Is there any unacceptable loading of the analogue filter/output node?|Static and dynamic measurement comparison with and without ADC attachment where practical|

## 8\. Sampling-rate and anti-alias qualification

The sampling-rate decision should not be conflated with the transport commissioning rate.

For communications and buffer-transfer testing, synthetic records may use any convenient nominal metadata. For actual ADXL1005 measurement, the sample-rate and analogue bandwidth must be mutually credible.

|Measurement condition|Consequence|
|-|-|
|EVAL-ADXL1005Z output filter has approximately 20 kHz −3 dB bandwidth|A 25.6 ksample/s acquisition mode cannot preserve the full analogue bandwidth without aliasing risk|
|ADXL1005 itself has typical −3 dB response to 23 kHz|A high-bandwidth measurement mode requires a sample rate above twice the intended usable band, with practical anti-alias margin|
|51.2 ksample/s candidate mode|Suitable as a minimum-class experimental candidate for a roughly 20 kHz filtered channel, but still requires alias/noise/timing evaluation|
|Lower sample-rate mode|Acceptable only if the analogue filter bandwidth is reduced correspondingly or the measurement claim is intentionally narrower|

A prudent staged position is:

```text
Transport commissioning:
    synthetic windows first; sample-rate metadata is a protocol test field.

Acquisition commissioning:
    begin with deliberately bandwidth-limited tests that avoid ambiguous aliasing.

High-bandwidth measurement qualification:
    investigate a 51.2 ksample/s-class or higher acquisition mode,
    with measured noise, timing and anti-alias behaviour.
```

The final node architecture may therefore need either a revised analogue filter target or a more capable/dedicated acquisition route, depending on measured results.

## 9\. Necessary architectural fork

The acquisition qualification gate should lead to an explicit engineering decision.

```text
If the nRF52833 ADC acquisition route is sufficiently clean and stable:
    retain the DWM3001 subsystem as the node-side acquisition
    and UWB communications endpoint.

If the nRF52833 ADC acquisition route is not sufficiently clean or
does not preserve the required vibration bandwidth:
    retain the DWM3001 subsystem as the UWB communications endpoint,
    but move precision vibration acquisition to a dedicated ADC /
    analogue-front-end path in a later Thin-Pod hardware revision.
```

Failure of the nRF52833 ADC route would **not** invalidate the modular UWB/Gateway architecture. It would demonstrate that the high-bandwidth sensor path merits a dedicated acquisition subsystem. That would be a technically serious outcome rather than a project failure.

## 10\. Second addition: DWM-to-NUCLEO host-interface protocol

The Gateway already has a documented data-path flow-control concept. The next firmware-enabling document should be:

```text
docs/dwm-to-nucleo-host-interface-protocol.md
```

Its function is to convert the Gateway-side DWM-to-NUCLEO route from an architectural intention into a byte-level implementation contract.

|Protocol area|Required content|
|-|-|
|Electrical role|NUCLEO as SPI host/master; Gateway DWM firmware as peripheral/slave; `DWM\_IRQ` as level-signalled notification|
|Commissioning rate|Conservative initial SPI rate, increased only after repeated integrity-tested transfer|
|Command set|`GET\_CAPABILITIES`, `GET\_STATUS`, `SET\_CREDITS`, `READ\_DESCRIPTOR`, `READ\_PAYLOAD`, `ACK\_WINDOW`, `REJECT\_WINDOW`, `GET\_COUNTERS`, `RESET\_INTERFACE`|
|Binary representation|Opcode values, byte order, field offsets, lengths, alignment and CRC coverage|
|Golden record|Fixed synthetic 4160-byte test record with known payload and expected integrity result|
|Reset/error behaviour|Defined recovery after DWM reset, NUCLEO reset, withheld acknowledgement, corrupted record or host timeout|
|Versioning|Protocol version independent of hardware revision where appropriate|

Without this file the carrier-board route is plausible but underspecified. With it, firmware implementation becomes an interoperability exercise with explicit pass/fail criteria.

## 11\. Third addition: throughput and airtime budget

Add:

```text
docs/window-throughput-and-airtime-budget.md
```

The purpose of this document is not to predict performance from headline PHY rates, but to measure the actual relationship between acquisition window size, UWB transfer, host transfer and analytic workload.

|Quantity|Initial design value|Measured value|
|-|-:|-:|
|Samples per raw window|2048|Pending|
|Raw payload bytes at 16-bit single-axis format|4096|Pending confirmation|
|Initial complete record bytes including fixed header|4160|Pending confirmation|
|Communications synthetic-test metadata rate|Defined for protocol tests only|Pending|
|Initial actual-acquisition sample rate|To be qualified|Pending|
|High-bandwidth acquisition candidate|51.2 ksample/s-class or higher, subject to qualification|Pending|
|Gateway DWM-to-NUCLEO host-transfer latency|Not yet claimed|Pending|
|UWB window-transfer latency|Not yet claimed|Pending|
|Sustainable admitted window rate for one node|Not yet claimed|Pending|
|Sustainable admitted window rate for multiple nodes|Not yet claimed|Pending|
|Record loss, retry and busy rates|Not yet claimed|Pending|

Qorvo’s documented 850 kbps and 6.8 Mbps UWB data rates establish that bounded-window transport is a credible experiment. Actual usable throughput depends on fragmentation, firmware scheduling, framing, integrity/security overhead, acknowledgements, retransmissions, UWB configuration and node scheduling; it must be measured.

This quantitative record would support the project’s longer research question:

> How much fault-relevant vibration information is retained per joule consumed and per byte transmitted as window length, sampling rate, transport configuration and analysis strategy vary?

## 12\. Fourth addition: fault-injection and recovery verification

Add:

```text
docs/data-path-fault-injection-and-recovery-tests.md
```

The flow-control and buffering policy must eventually be proven by controlled failure, not merely described.

|Injected condition|Expected behaviour|
|-|-|
|NUCLEO withholds `ACK\_WINDOW`|Gateway DWM retains completed record and does not overwrite it|
|NUCLEO raw queue reaches high-water level|New measurement credits withheld; event counter incremented|
|Synthetic record contains deliberately incorrect CRC|Record rejected and never submitted to DSP|
|One UWB fragment omitted|Window marked incomplete and not exposed as valid raw data|
|Fragment or sequence duplicated|Duplicate handled deterministically and recorded|
|DWM reset occurs during host transfer|Interface returns through explicit recovery/error state|
|NUCLEO becomes unavailable|Gateway DWM stops granting new measurement windows|
|XIAO reporting task is delayed or held busy|Measurement ingress continues or is prioritised; backhaul does not block raw receipt|
|Node attempts transmission without credit|Protocol violation or busy rejection recorded|

This is the proof layer for the project’s measurement-integrity position: missing or invalid data must become visible evidence, not silent absence.

## 13\. Fifth addition: measurement record and provenance model

Add:

```text
docs/measurement-record-and-provenance-model.md
```

Each retained vibration window should eventually be traceable through the hardware, firmware, transport and analysis chain.

|Provenance element|Purpose|
|-|-|
|Node hardware revision|Identifies physical measurement platform|
|Node firmware build|Identifies acquisition and transmission behaviour|
|Sensor identity|Identifies the actual measurement source|
|ADC configuration|Defines gain, range, reference and sample conversion assumptions|
|Sample rate and sample count|Preserves temporal/frequency meaning|
|Analogue filter configuration|Defines bandwidth and anti-alias context|
|Calibration state/version|Distinguishes characterised from uncharacterised measurement|
|Window sequence and timing|Preserves ordering and acquisition context|
|UWB transport integrity status|Records successful validation, retries, drops or failures|
|Gateway hardware revision|Identifies receiving carrier implementation|
|Gateway DWM firmware build|Identifies receive/reassembly/host-interface behaviour|
|NUCLEO firmware and DSP build|Identifies processing path|
|DSP feature-set version|Makes derived values reproducible|
|TinyML model version, where later used|Makes inference provenance explicit|

The measurement record should retain enough information to answer:

```text
What was sensed?
How was it sampled?
How was it transported?
What transformations were applied?
Which version of the system made the interpretation?
```

## 14\. Recommended implementation order

|Priority|Document or activity|Reason|
|-:|-|-|
|1|`node-acquisition-and-sampling-contract.md`|Tests the largest unverified assumption: creation of a useful digital vibration window|
|2|`dwm-to-nucleo-host-interface-protocol.md`|Converts the Gateway copper route into an implementable firmware contract|
|3|`data-path-fault-injection-and-recovery-tests.md`|Demonstrates that overrun and integrity failure cannot become silent data corruption|
|4|`window-throughput-and-airtime-budget.md`|Establishes quantitative scaling and later research credibility|
|5|`measurement-record-and-provenance-model.md`|Completes the traceability chain needed for DSP/TinyML evidence|

## 15\. Immediate recommendation

The next document to compose should be:

```text
docs/node-acquisition-and-sampling-contract.md
```

It should set an acquisition gate before any later claim of transported measurement windows:

> Before claiming that Thin-Pod transports vibration windows, establish that the external ADXL1005 signal can be digitised at the node with adequate bandwidth, input-range margin, timing stability, anti-alias treatment and noise performance. If the DWM3001/nRF52833 ADC path proves insufficient, preserve the modular UWB/Gateway architecture and introduce a dedicated acquisition ADC in a later node revision.

This is the most important addition because it treats Thin-Pod as a measurement instrument rather than only a communications demonstrator.

## 16\. References

* Analog Devices, **ADXL1005: Low Noise, Wide Bandwidth, MEMS Accelerometer** product information and evaluation-board description: [https://www.analog.com/en/products/adxl1005.html](https://www.analog.com/en/products/adxl1005.html)
* Qorvo, **DWM3001C UWB Module with BLE SoC and Motion Sensor** product information: [https://www.qorvo.com/products/p/DWM3001C](https://www.qorvo.com/products/p/DWM3001C)
* Qorvo, **DWM3001CDK Development Kit** product information: [https://www.qorvo.com/products/p/DWM3001CDK](https://www.qorvo.com/products/p/DWM3001CDK)
* Nordic Semiconductor, **nRF52833 Advanced Bluetooth Multiprotocol SoC** product information: [https://www.nordicsemi.com/Products/nRF52833](https://www.nordicsemi.com/Products/nRF52833)
* Thin-Pod Gateway rev 0.1, `docs/data-path-flow-control-and-buffering.md`.
* Thin-Pod Gateway rev 0.1, `docs/gateway-bring-up-and-verification-protocol.md`.
* Thin-Pod Gateway rev 0.1, `docs/system-interface-control-document.md`.

## 17\. Closing position

Thin-Pod now has a plausible and disciplined modular route from analogue vibration sensing to Gateway-side DSP and later TinyML. The remaining risk is not primarily whether a buffer can be sent: it is whether the source buffer faithfully represents a useful vibration measurement.

The next phase should therefore qualify the acquisition path, specify the host protocol, test failure behaviour, measure throughput and preserve provenance. That sequence would turn a sound modular architecture into an instrument whose later analytic claims can be defended.

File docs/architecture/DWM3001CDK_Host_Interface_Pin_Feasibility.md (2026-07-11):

# DWM3001-CDK Host-Interface Pin Feasibility

## Document control

**Document identifier:** TP-GW-ARCH-0004<br>
**Document revision:** Draft A<br>
**Product context:** Thin-Pod Gateway rev 0.1<br>
**Document status:** Pin/interface feasibility investigation<br>
**Related documents:**<br>
- `docs/architecture/Gateway_UWB_Module_Access_Model.md`<br>
- `docs/dwm-to-nucleo-host-interface-protocol.md`<br>
- `logs/96_Engineering_Log.md`

---

## 1. Purpose

This document determines whether the Gateway rev 0.1 hardware can support a direct host interface between:

```text
NUCLEO-N657X0-Q
    and
DWM3001-CDK onboard nRF52833 firmware
```

The target host-interface proof is:

```text
GET_CAPABILITIES
GET_STATUS
GET_COUNTERS
```

The central feasibility question is:

```text
Which exposed DWM3001-CDK pins can the onboard nRF52833 use for a host interface to the NUCLEO?
```

---

## 2. Starting architectural position

Gateway rev 0.1 adopts the DWM3001-CDK-as-UWB-coprocessor model.

```text
DWM3001-CDK:
    intelligent UWB coprocessor/module
    owns DW3110 radio control

NUCLEO-N657X0-Q:
    Gateway supervisor / host / analysis controller

Gateway PCB:
    modular open-hardware carrier/interface layer
```

The direct NUCLEO-to-DW3110 DEV_ID probe is retained as diagnostic evidence. The host-interface proof should therefore target DWM3001-CDK firmware, not the DW3110 silicon directly.

---

## 3. Known Gateway-side signals

The Gateway rev 0.1 PCB currently exposes the following DWM-related signal paths:

```text
TP7  / J10.24 : DWM_CS
TP10 / J10.23 : SCK
TP11 / J10.19 : COPI / MOSI
TP12 / J10.21 : CIPO / MISO
TP6  / J10.15 : DWM_IRQ
TP5  / J10.12 : DWM_RESET
TP1          : GND reference
```

These paths have already supported GPIO and SPI electrical bring-up from the NUCLEO side.

The unresolved question is whether those DWM3001-CDK header pins reach nRF52833 GPIOs that can be configured as a host-interface peripheral, or whether they primarily expose the DW3110-facing path / CDK-specific diagnostic routing.

---

## 4. Known Zephyr DWM3001-CDK board-definition evidence

The local Zephyr board definition for `decawave_dwm3001cdk` shows an onboard SPI instance:

```text
&spi3 {
    compatible = "nordic,nrf-spim";
    cs-gpios = <&gpio1 6 GPIO_ACTIVE_LOW>;
}
```

The associated pinctrl entries show:

```text
SPIM_SCK  : P0.3
SPIM_MOSI : P0.8
SPIM_MISO : P0.29
CS        : P1.6
IRQ       : P0.16
```

This appears to describe the onboard nRF52833-to-DW3110 SPI master path.

Therefore, Gateway rev 0.1 should not assume that the existing Gateway SPI route can be reused as an nRF52833 SPI peripheral host interface until the external connector routing is checked.

---

## 5. Feasibility matrix

| Candidate route | Required exposed signals | Evidence required | Status |
|---|---:|---|---|
| SPI peripheral / SPIS | SCK, COPI/MOSI, CIPO/MISO, CS, IRQ | DWM3001-CDK header pins map to nRF52833 GPIOs that support SPIS and are not reserved for DW3110 | Pending |
| UART | TX, RX, optional IRQ/GPIO | DWM3001-CDK header pins expose a usable nRF UARTE pair connected to NUCLEO-accessible pins | Pending |
| GPIO mailbox | 2-4 GPIO lines | Enough nRF GPIOs are exposed and routed to NUCLEO for command/status strobes | Pending |
| Existing DW3110 SPI path | Existing TP7/TP10/TP11/TP12 | Proves direct silicon path only; diagnostic branch, not preferred host-interface route | Diagnostic only |
| Future wiring / rev 0.2 | Explicit host-interface pins | Current rev 0.1 lacks clean exposed interface | Pending |

---

## 6. Investigation procedure

### 6.1 Confirm repo signal names

Search the Gateway repo for the DWM connector, test points and signal names.

```powershell
cd C:\ThinPod\Thin-Pod-Gateway-rev-0.1

git grep -n "J10\.23\|J10\.21\|J10\.19\|J10\.24\|J10\.15\|J10\.12\|TP7\|TP10\|TP11\|TP12\|DWM_CS\|DWM_IRQ\|DWM_RESET\|MOSI\|MISO\|SCK"
```

Record the files and net names in this document.

### 6.2 Inspect Zephyr DWM3001-CDK board files

```powershell
cd C:\Users\n_tho\zephyrproject\zephyr

Get-Content boards\qorvo\decawave_dwm3001cdk\decawave_dwm3001cdk.dts

Get-Content boards\qorvo\decawave_dwm3001cdk\decawave_dwm3001cdk-pinctrl.dtsi
```

Record all SPI, UART, GPIO, button, LED, IRQ and reset pins.

### 6.3 Search for external connector documentation

```powershell
cd C:\Users\n_tho\zephyrproject\zephyr

Get-ChildItem boards\qorvo\decawave_dwm3001cdk -Recurse |
  Select-Object FullName
```

Then search the Thin-Pod Gateway repo:

```powershell
cd C:\ThinPod\Thin-Pod-Gateway-rev-0.1

git ls-files | Select-String -Pattern "DWM|DWM3001|CDK|J10|pin|connector|schematic|interface"
```

Record any connector tables already present.

### 6.4 Map Gateway pins to DWM3001-CDK function

Create a table with one row per Gateway-connected DWM pin:

| Gateway TP | CDK connector pin | Gateway signal | Known CDK function | nRF52833 GPIO? | DW3110 signal? | Usable for host interface? |
|---|---:|---|---|---|---|---|
| TP7 | J10.24 | DWM_CS | Pending | Pending | Pending | Pending |
| TP10 | J10.23 | SCK | Pending | Pending | Pending | Pending |
| TP11 | J10.19 | COPI / MOSI | Pending | Pending | Pending | Pending |
| TP12 | J10.21 | CIPO / MISO | Pending | Pending | Pending | Pending |
| TP6 | J10.15 | DWM_IRQ | Pending | Pending | Pending | Pending |
| TP5 | J10.12 | DWM_RESET | Pending | Pending | Pending | Pending |

### 6.5 Bench confirmation, if documentation is ambiguous

Use non-destructive checks first:

```text
Power removed:
    DMM continuity from Gateway test points to DWM3001-CDK header pins.

Power applied:
    scope only after ground sanity checks.
```

If candidate nRF GPIOs are identified, write a DWM3001-CDK GPIO toggle probe that toggles one candidate pin at a time and observe the corresponding Gateway TP.

Do not run a broad GPIO sweep against unknown pins. Avoid toggling pins that are documented as reset, power, SWD, DW3110 SPI or IRQ without a specific reason.

---

## 7. Decision criteria

### SPI peripheral / SPIS is viable if:

```text
At least four NUCLEO-connected DWM-side pins map to free nRF52833 GPIOs:
    SCK input
    COPI / MOSI input
    CIPO / MISO output
    CS input

A fifth pin is available for IRQ/ready notification.
```

### UART is viable if:

```text
At least two NUCLEO-connected DWM-side pins map to free nRF52833 GPIOs:
    DWM TX -> NUCLEO RX
    DWM RX <- NUCLEO TX

An optional IRQ or ready GPIO improves robustness.
```

### GPIO mailbox is viable if:

```text
A small number of NUCLEO-connected GPIO lines can carry command strobes,
ready state and small status/counter values for proof only.
```

### Rev 0.1 host-interface proof should be deferred if:

```text
The existing Gateway-connected DWM pins do not expose a clean nRF52833 firmware interface.
```

In that case, document Gateway rev 0.1 as a modular carrier with proven power/GPIO/SPI routing and record the host-interface as a rev 0.2 hardware requirement.

---

## 8. Preliminary conclusion

The local Zephyr board definition confirms that `spi3` is configured as an nRF SPIM path, apparently for the onboard DW3110 connection. This supports caution: the existing Gateway SPI path should not be assumed to be a DWM firmware host interface.

The next evidence item is a connector-level pin map from Gateway TP/J10 signals to DWM3001-CDK exposed functions and nRF52833 GPIO availability.

---

## 9. Interim findings from Gateway repo and DWM3001-CDK J10 audit

Gateway repo searches confirm that the manufactured Gateway rev 0.1 design routes the NUCLEO to the DWM3001-CDK J10 Raspberry Pi-compatible interface pins as follows:

| Gateway TP | NUCLEO signal | NUCLEO pin | DWM3001-CDK pin / function | Current interpretation |
|---|---|---|---|---|
| TP10 | SPI5_SCK | CN15.11 / PE15 | J10.23 / SPI1_CLK | External host clock candidate |
| TP12 | SPI5_MISO | CN15.13 / PG1 | J10.21 / SPI1_MISO | DWM-to-host return candidate |
| TP11 | SPI5_MOSI | CN15.15 / PG2 | J10.19 / SPI1_MOSI | Host-to-DWM command/data candidate |
| TP7 | DWM_CS | CN15.17 / PA3 | J10.24 / CS_RPI | External host chip-select candidate |
| TP6 | DWM_IRQ | CN15.16 / PB9 | J10.15 / GPIO_RPI | External host notification candidate |
| TP5 | DWM_RESET | CN15.33 / PD0 | J10.12 / RESET | Controlled module reset / recovery |

This supports the view that the Gateway PCB was designed around the DWM3001-CDK external-host interface route.

This does not yet prove that current DWM3001-CDK firmware configures those pins as an SPI peripheral endpoint. It establishes the hardware and documentation target for the next firmware proof.

The local Zephyr DWM3001-CDK board definition separately identifies `spi3` as an onboard nRF SPIM route, consistent with the nRF52833-to-DW3110 internal control path. That path should remain distinct from the J10 Raspberry Pi host-interface route.

## 10. Updated feasibility position

SPI peripheral / SPIS remains the preferred proof route if the J10 `SPI1_*` and `CS_RPI` pins are exposed to configurable nRF52833 peripheral logic.

The first implementation should therefore attempt a DWM-side SPI-peripheral stub on the J10 host-interface pins and a NUCLEO-side SPI host probe on the already-proven Gateway SPI5 pins.

If SPIS on those pins is not supported or conflicts with the DWM3001-CDK firmware environment, the fallback route is a UART or GPIO-mailbox proof over exposed J10 GPIO/interface pins.
---

## 11. Qorvo DWM3001CDK J10-to-DWM3001C pin mapping

The Gateway KiCad schematic confirms the NUCLEO-to-DWM3001-CDK J10 wiring for the intended host-interface route.

The Qorvo DWM3001CDK Quick Start Guide confirms the corresponding J10-to-DWM3001C module pin mapping.

| Gateway TP | Gateway signal | DWM3001-CDK J10 function | DWM3001C module pin | nRF52833 GPIO | Host-interface use |
|---|---|---|---|---|---|
| TP10 | SPI5_SCK | J10.23 / SPI1_CLK | Pin 42 | P0.31 | SPI peripheral clock input candidate |
| TP11 | SPI5_MOSI | J10.19 / SPI1_MOSI | Pin 41 | P0.27 | SPI peripheral COPI/MOSI input candidate |
| TP12 | SPI5_MISO | J10.21 / SPI1_MISO | Pin 40 | P0.07 | SPI peripheral CIPO/MISO output candidate |
| TP7 | DWM_CS | J10.24 / CS_RPI | Pin 43 | P0.30 | SPI chip-select input candidate |
| TP6 | DWM_IRQ | J10.15 / GPIO_RPI | Pin 33 | P0.28 | DWM-to-NUCLEO ready/status notification candidate |
| TP5 | DWM_RESET | J10.12 / RESET | Pin 47 | P0.18 | Reset / recovery path, not normal data path |

Additional J10 interface pins available for fallback investigation:

| DWM3001-CDK J10 function | DWM3001C module pin | nRF52833 GPIO | Possible use |
|---|---|---|---|
| J10.8 / TXD | Pin 32 | P0.15 | UART fallback candidate |
| J10.10 / RXD_RPI / RXD | Pin 34 | P0.19 | UART fallback candidate |
| J10.3 / SDA_RPI | Pin 37 | P0.26 | I2C/GPIO fallback candidate |
| J10.5 / SCL_RPI | Pin 39 | P0.23 | I2C/GPIO fallback candidate |

## 12. Feasibility conclusion after schematic and Qorvo pin-map check

The Gateway rev 0.1 hardware route is now confirmed at both sides of the interface:

```text
NUCLEO SPI5 / GPIO pins
    -> Gateway PCB nets and test points
        -> DWM3001-CDK J10 Raspberry Pi-compatible header
            -> DWM3001C / nRF52833 GPIO pins
```

This supports proceeding to a DWM-side SPI-peripheral proof using:

```text
SPIS SCK  = P0.31
SPIS MOSI = P0.27
SPIS MISO = P0.07
SPIS CS   = P0.30
IRQ/READY = P0.28
RESET     = P0.18, controlled externally through J10.12
```

The next firmware step is to create a DWM3001-CDK host-interface stub overlay that configures the J10 SPI1_* pins as an nRF SPIS endpoint, while preserving the separate onboard nRF-to-DW3110 SPI path.

The implementation remains a proof of the DWM-to-NUCLEO firmware host interface. It is not a direct NUCLEO-to-DW3110 register-control path.

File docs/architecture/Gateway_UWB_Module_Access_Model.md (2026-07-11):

# Gateway UWB Module Access Model

## Document control

**Document identifier:** TP-GW-ARCH-0003
**Document revision:** Draft A
**Product context:** Thin-Pod Gateway rev 0.1
**Document status:** Architecture decision and technical closeout record
**Certification boundary:** Supports Gateway rev 0.1 open-hardware packaging. This document does not expand the Thin-Pod rev 0.1 node certification boundary.

## 1. Purpose

This document records the Gateway rev 0.1 access-model decision for the Qorvo DWM3001-CDK.

The decision resolves whether the Gateway architecture should treat the DWM3001-CDK as:

```text
A. a passive DW3110 SPI target directly owned by the NUCLEO
B. an intelligent UWB coprocessor/module with its own onboard controller
```

The adopted approach for Gateway rev 0.1 is option B.

## 2. Decision

Thin-Pod Gateway rev 0.1 treats the DWM3001-CDK as an intelligent UWB coprocessor/module.

The DWM3001-CDK / DWM3001C subsystem owns DW3110 radio control. The STM32 NUCLEO-N657X0-Q acts as Gateway supervisor, host, logger and analysis controller. The Gateway carrier/interface board provides power, reset, GPIO, SPI/host-interface routing and test points between the modular subsystems.

Direct NUCLEO-to-DW3110 register probing is retained as diagnostic bring-up evidence. It is not the primary Gateway rev 0.1 architecture gate.

## 3. Architectural model

```text
Thin-Pod node
    |
    | UWB transport
    v
Gateway DWM3001-CDK UWB subsystem
    |
    | host-interface contract
    v
NUCLEO-N657X0-Q supervisor / memory / analysis layer
    |
    | network or auxiliary interface
    v
XIAO ESP32-C6 / later backhaul
```

In this model:

```text
DWM3001-CDK:
    UWB coprocessor/module
    DW3110 radio ownership
    UWB role firmware
    receive/reassembly/status/counter responsibilities as implemented

NUCLEO-N657X0-Q:
    Gateway supervisor
    host-interface controller
    admitted-window memory owner
    DSP / later TinyML host
    engineering evidence and logging endpoint

Gateway carrier PCB:
    modular open-hardware interconnect
    power and signal routing
    GPIO/SPI/test-point exposure
    replaceable-module integration layer
```

## 4. Rationale

The DWM3001-CDK is a module/controller development kit rather than a passive DW3110 breakout. The DWM3001C module includes an onboard nRF52833 controller and DW3110 UWB transceiver. Previous Gateway work already treated the DWM3001 side as a role-bearing UWB subsystem.

NUCLEO-side direct DW3110 probing has been useful diagnostic work:

```text
Build/sign/flash: pass
Firmware runtime: pass
SPI transaction ret=0: pass
DW3110 DEV_ID readback: not yet returned
RX result: all zero
```

The result suggests that direct external DW3110 ownership through the CDK is not currently established. It does not invalidate the Gateway carrier board or the modular Gateway architecture.

## 5. Consequences

Gateway rev 0.1 technical closeout should prioritise:

```text
1. Confirming the live state of the Gateway DWM3001-CDK.
2. Documenting the DWM3001-CDK as an intelligent UWB coprocessor/module.
3. Defining the DWM-to-NUCLEO host-interface contract.
4. Preserving direct DW3110 register probing as diagnostic evidence.
```

Gateway rev 0.1 open-hardware readiness should be judged against the carrier/interface board and its documented modular role, not against direct NUCLEO ownership of the DW3110 silicon.

## 6. Required follow-on work

The next firmware-enabling document should be:

```text
docs/dwm-to-nucleo-host-interface-protocol.md
```

Its first implementation proof should be deliberately small:

```text
GET_CAPABILITIES
GET_STATUS
GET_COUNTERS
```

The minimal proof should establish that the NUCLEO can communicate with Gateway-side DWM firmware through a defined host-interface path.

## 7. Technical closeout position

For Gateway rev 0.1, the technical closeout target is:

```text
The Gateway carrier/interface board cleanly integrates the NUCLEO supervisor,
the DWM3001-CDK UWB coprocessor/module and the XIAO ESP32-C6 auxiliary module,
with verified power, GPIO, SPI/test-point evidence and a documented UWB
module access model.
```

Direct NUCLEO-to-DW3110 register access remains a useful diagnostic branch and may be revisited if a future revision requires direct silicon ownership.

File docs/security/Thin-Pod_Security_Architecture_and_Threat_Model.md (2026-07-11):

# Thin-Pod Security Architecture and Threat Model

**Document identifier:** `TP-SYS-SEC-0001`
**Revision:** Draft A
**Date:** 11 July 2026
**Status:** Security architecture and threat-model baseline
**Applies to:** Thin-Pod rev 0.1 node, Thin-Pod Gateway rev 0.1, associated firmware, host tooling and later backend integration
**Evidence baseline:** Node commit `289c93e14eff67d7815be4803c488e5ac80a4f6c`; Gateway commit `a2c8b846d1a67bcbf2f612d94cc7d17feea107dc`

## 1. Purpose

This document defines the security architecture, trust boundaries, assets, threats, control objectives and verification gates for the Thin-Pod experimental condition-monitoring system.

The baseline replaces an earlier security model that assumed an Ethernet-connected STM32 Gateway and an ESP32-based Thin-Pod node. The current system uses:

- a Thin-Pod rev 0.1 analogue vibration-sensing carrier;
- a node-side Qorvo DWM3001-CDK containing an nRF52833 and DW3110;
- a Gateway-side Qorvo DWM3001-CDK;
- an STM32 NUCLEO-N657X0-Q as Gateway host and prospective analysis supervisor;
- an optional Seeed Studio XIAO ESP32-C6 as the onward-networking subsystem;
- a later backend or client service outside the present hardware release.

This is a design and assurance document. It records required controls and current gaps. It does not claim that secure boot, authenticated UWB transport, secure host-interface messaging or operational OTA has been implemented.

## 2. Security principles

1. The measurement chain must preserve authenticity, integrity, provenance and availability state from acquisition to decision.
2. The optional ESP32-C6 is the network-edge trust zone. The NUCLEO should remain free from direct LAN exposure in the initial architecture.
3. Every MCU and communications subsystem is treated as an independent firmware security domain.
4. A CRC detects accidental corruption. A cryptographic MAC or authenticated-encryption tag establishes integrity under an active attacker.
5. Missing, rejected, stale and replayed records remain explicit evidence. Absence of data must never be converted into a healthy-machine conclusion.
6. Development access and deployment hardening are separate profiles with recorded transitions.
7. Open hardware and open firmware contain no deployment secrets. Device-specific keys and credentials remain private.
8. Security claims advance only after the corresponding adverse tests have passed.
9. Recovery is part of the security design. A device that verifies firmware but cannot recover safely remains operationally fragile.
10. Component versions, advisories, signing state and support commitments must be traceable to each release.

## 3. System security context

```text
Mechanical vibration
        |
        v
Thin-Pod rev 0.1 analogue carrier
        |
        | analogue measurement path
        v
Node DWM3001-CDK
  nRF52833 firmware + DW3110 UWB radio
        |
        | UWB trust boundary
        v
Gateway DWM3001-CDK
  nRF52833 firmware + DW3110 UWB radio
        |
        | SPI host-interface trust boundary
        v
STM32 NUCLEO-N657X0-Q
  record ownership, buffering, logging, later DSP/TinyML
        |
        | narrow onward-interface trust boundary
        v
XIAO ESP32-C6
  optional IP networking and remote update agent
        |
        | LAN / Internet / backend trust boundary
        v
Backend service, maintenance client or evidence archive
```

The present Gateway repository establishes firmware execution, debug logging, physical interface evidence and protocol scaffolding. Real DW3110 RF exchange, authenticated measurement transport, DWM-to-NUCLEO record transfer, operational OTA and backend integration remain future verification stages.

## 4. Assets and security objectives

| Asset | Required property | Consequence of compromise |
|---|---|---|
| Raw vibration window | Authenticity, integrity, provenance, ordering | False or misleading condition evidence |
| Acquisition metadata | Integrity, completeness, binding to raw window | Invalid feature interpretation |
| Node identity | Authenticity, uniqueness, revocability | Device impersonation or data substitution |
| Firmware image | Authenticity, version control, recoverability | Persistent code execution or unsafe operation |
| Signing keys | Confidentiality, controlled use, revocability | Fleet-wide firmware compromise |
| Transport keys | Confidentiality where required, uniqueness, rotation | Record forgery, replay or disclosure |
| Gateway host commands | Integrity, authorisation, bounded parsing | Peripheral-to-host compromise |
| Analytic result | Traceability to exact input and processing version | Unsupported maintenance conclusion |
| Security logs | Integrity, time context, retention | Loss of forensic evidence |
| Availability state | Accurate reporting | Communication failure mistaken for healthy operation |
| Debug interface | Controlled access | Firmware extraction, modification or key exposure |
| Backend credentials | Confidentiality, rotation | Unauthorised service access |

The priority order for the experimental system is:

1. firmware authenticity;
2. measurement authenticity and integrity;
3. replay resistance and ordering;
4. evidence provenance;
5. safe failure and recoverability;
6. availability-state reporting;
7. confidentiality where machine information or credentials require it.

## 5. Trust zones and responsibility allocation

| Zone | Components | Security responsibility |
|---|---|---|
| Physical sensing zone | ADXL1005 interface and node carrier | Expose a measurable signal and preserve hardware identity; no cryptographic function is claimed by the carrier |
| Node firmware zone | Node DWM3001-CDK | Acquire or receive the measurement, assign identity/session/sequence, authenticate records and control the UWB radio |
| UWB communications zone | Node and Gateway DW3110 radios | Apply configured radio security, transport framing, anti-replay input and loss reporting |
| Gateway radio zone | Gateway DWM3001-CDK | Validate radio frames, reconstruct bounded records and expose a constrained host interface |
| Measurement and analysis zone | NUCLEO-N657X0-Q | Accept only validated bounded records, preserve raw evidence and generate traceable derived outputs |
| Network-edge zone | XIAO ESP32-C6 | Own IP networking, remote credentials, TLS, OTA and network-originated input filtering |
| Backend zone | Future service or archive | Authenticate devices, authorise access, retain records and manage credentials and lifecycle policy |

No trust zone may assume that an adjacent zone is uncompromised. Each boundary requires explicit validation and a defined failure response.

## 6. Threat actors and operating assumptions

### 6.1 Threat actors

- a nearby radio attacker able to transmit, receive, replay or jam UWB, BLE or Wi-Fi;
- a LAN attacker able to probe or compromise the XIAO ESP32-C6;
- an attacker with temporary physical access to a node or Gateway;
- a malicious or compromised firmware dependency;
- a contributor or build host that introduces unauthorised code or artefacts;
- an operator who installs the wrong firmware or key material;
- a compromised backend credential or service account;
- an accidental fault that resembles an attack, including bit corruption, brown-out, reset loops or partial update.

### 6.2 Assumptions

- the current development kits expose debug and recovery interfaces;
- laboratory firmware may retain J-Link, ST-LINK, UART and RTT access;
- production keys do not yet exist;
- the current packet CRCs provide accidental-error detection only;
- the current Telemetry Packet v1 is a laboratory proof format;
- the XIAO ESP32-C6 remains optional and outside the measurement-critical path;
- physical radio jamming cannot be prevented by cryptography;
- a future deployed profile will require a deliberate transition from development access to restricted debug and signed update.

## 7. Attack surfaces

| Surface | Examples |
|---|---|
| Node physical access | SWD/J-Link access, reset manipulation, flash extraction, sensor substitution |
| Gateway physical access | NUCLEO debug, DWM debug, SPI probing, XIAO programming access |
| UWB | spoofing, replay, malicious framing, jamming, forced resource use |
| BLE | unintended advertising, pairing, debug or DFU exposure |
| Wi-Fi/IP | service enumeration, credential attack, malformed network input, TLS misconfiguration |
| Host interface | oversized lengths, unknown opcodes, invalid state transitions, response confusion |
| Firmware update | unsigned image, downgrade, interrupted update, compromised signing key |
| Build and release | dependency substitution, unreviewed binary, missing SBOM, non-reproducible artefact |
| Backend | stolen credentials, excessive permissions, weak retention or audit controls |
| Maintenance workflow | false confidence, ignored stale-data state, unsupported diagnostic claim |

Unused services and radios should remain disabled by default.
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

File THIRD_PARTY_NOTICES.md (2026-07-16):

# Third-party notices and dependency boundaries

Thin-Pod Gateway rev 0.1 is a creator-designed carrier PCB and software/documentation project that interfaces with commercial development modules and external software. Inclusion in a BOM, build manifest or interface description does not relicense third-party material.

## Commercial hardware

| Item | Role | Treatment |
|---|---|---|
| STMicroelectronics `NUCLEO-N657X0-Q` | Main Gateway host | Commercial development board. Internal design, firmware and documentation remain under STMicroelectronics terms. |
| Qorvo `DWM3001-CDK` | Gateway-side UWB subsystem | Commercial development board. Internal PCB, DW3110 device, supplied firmware and documentation remain under Qorvo terms. |
| Seeed Studio `XIAO ESP32-C6` | Optional onward-networking subsystem | Commercial module. Internal design, firmware and documentation remain under Seeed Studio and upstream terms. |
| Standard electronic components and assembly hardware | Carrier-board implementation | Commercial bought-in parts identified for reproducibility; no relicensing is asserted. |

## External software and toolchains

| Dependency | Use in this repository | Licence treatment |
|---|---|---|
| Qorvo `DW3_QM33_SDK_1.1.0` | External DW3000/DW3110 driver compiled by the Stage-2 applications | Not distributed in this repository. The installed SDK identifies its driver material as `LicenseRef-QORVO-2`; the authoritative terms remain with the SDK. |
| Zephyr Project | RTOS, drivers, devicetree and build system | Upstream Zephyr licences and file-level notices apply. |
| Nordic nRF Connect SDK | DWM3001-CDK firmware build environment | Upstream Nordic, Zephyr and component-specific terms apply. |
| STM32/Zephyr support packages | NUCLEO firmware build environment | Upstream STMicroelectronics, Zephyr and component-specific terms apply. |
| KiCad | Hardware design and fabrication-output generation | KiCad application and library licences apply to the tooling and any library-derived material. |

The files under `firmware/common/qorvo_dw3000/` are Thin-Pod-authored integration and platform-adapter material unless a file states otherwise. They locate and compile an external Qorvo SDK; they do not contain or relicense that SDK.
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

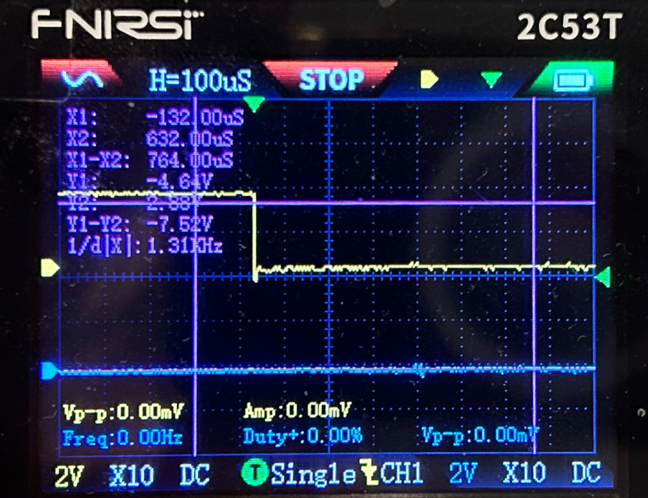
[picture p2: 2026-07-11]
images/SPI5_TP7_CS_TP12_MISO_64byte_scope.jpg

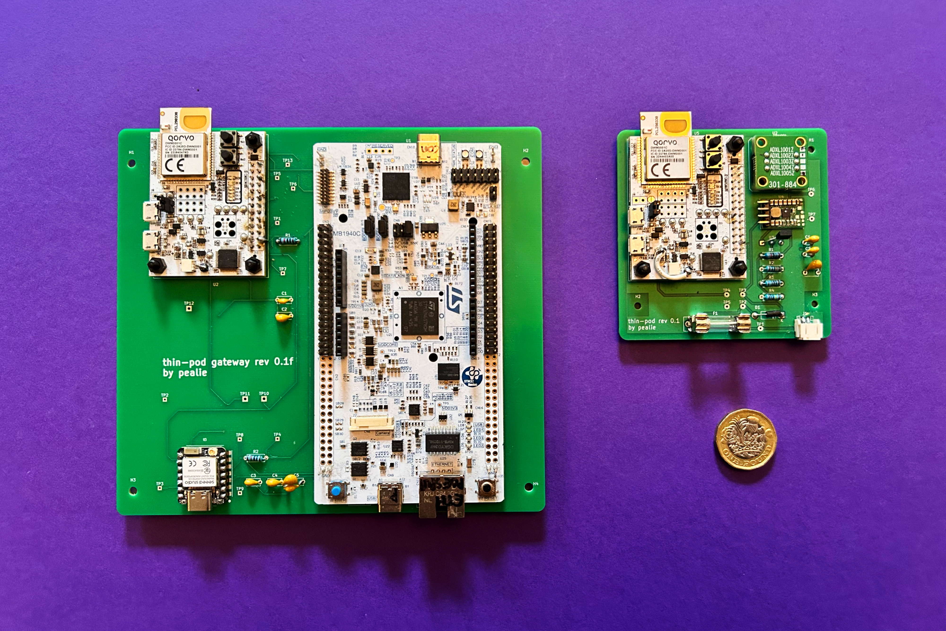
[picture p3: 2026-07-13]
images/Thin-Pod Gateway and Thin-Pod node.JPG

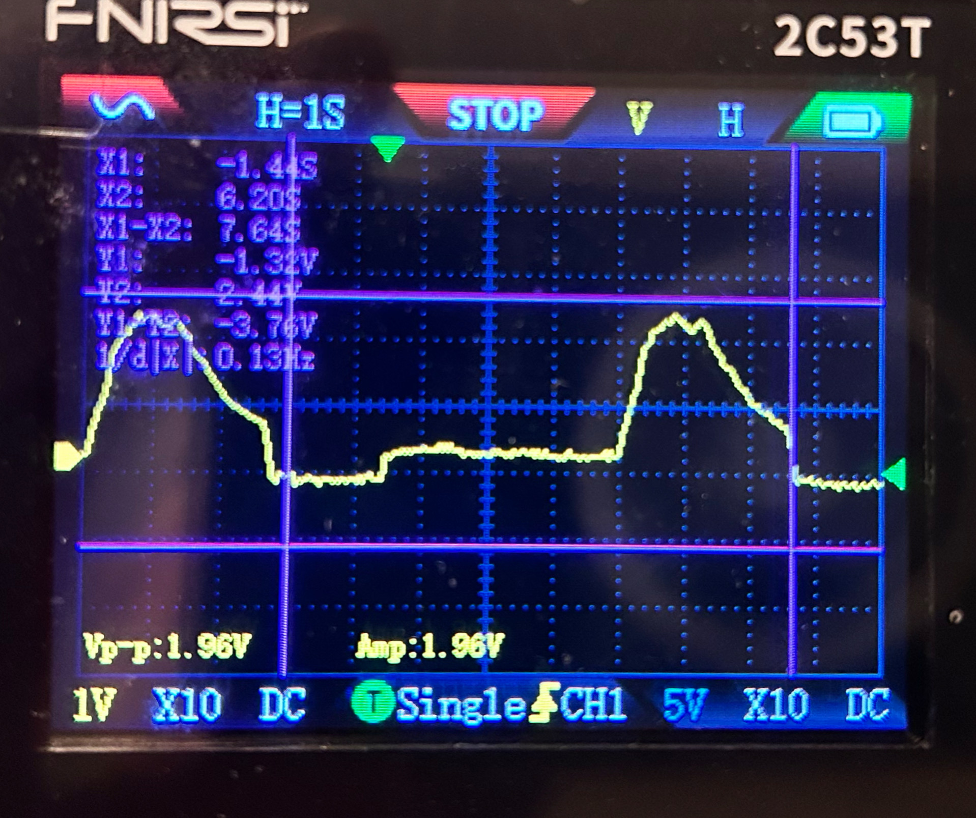
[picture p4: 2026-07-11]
images/TP6_DWM_READY_2s_scope_2026-07-09.JPEG

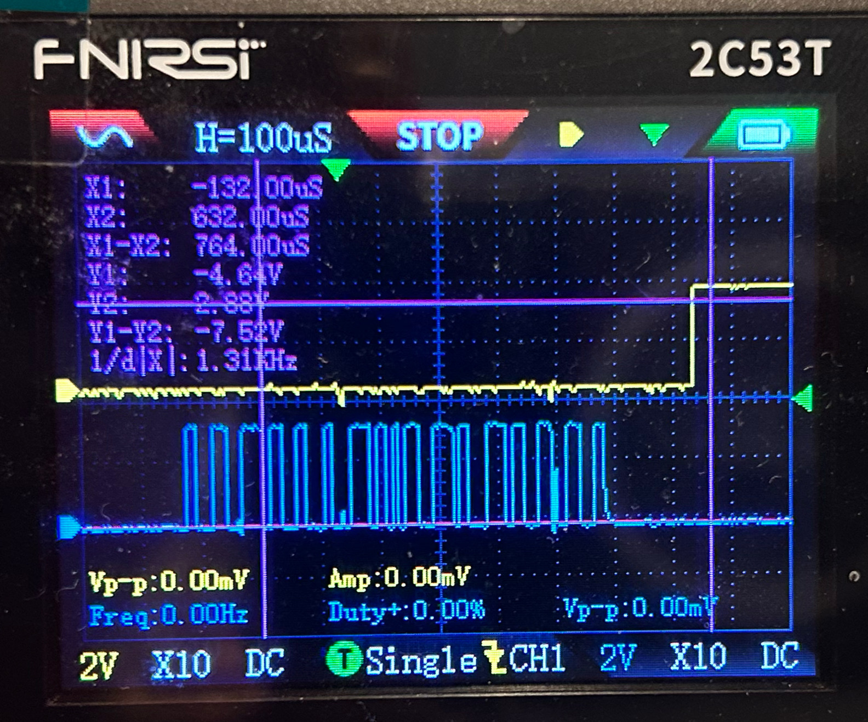
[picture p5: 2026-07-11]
images/SPI5_TP7_CS_TP11_MOSI_64byte_scope.jpg

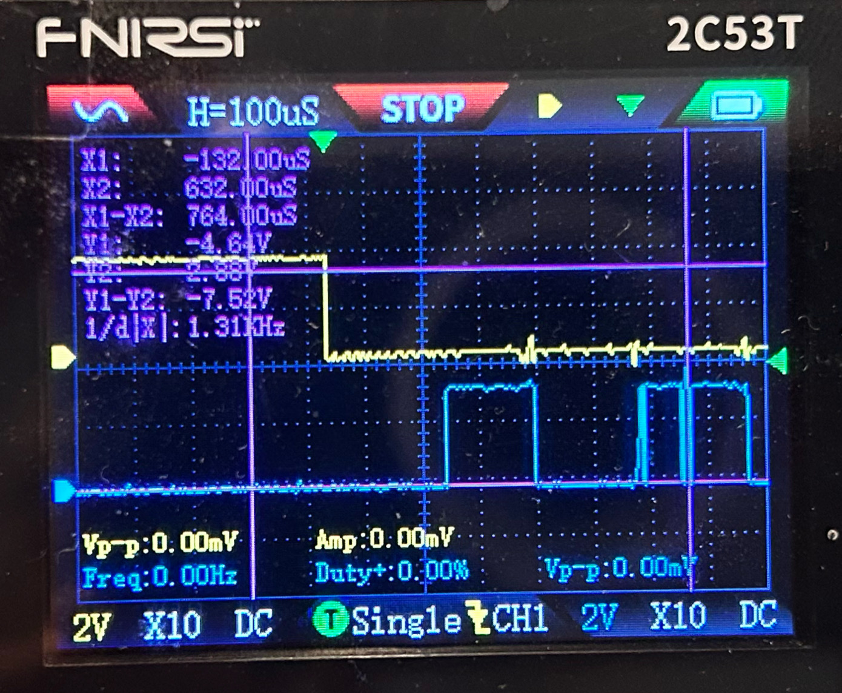
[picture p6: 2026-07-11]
images/SPI5_TP7_CS_TP10_SCK_64byte_scope.jpg

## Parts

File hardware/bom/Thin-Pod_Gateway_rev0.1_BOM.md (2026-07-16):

# Thin-Pod Gateway rev 0.1 Bill of Materials

**Project:** Thin-Pod Gateway<br>
**Hardware release:** rev 0.1<br>
**Manufactured carrier identity:** rev 0.1f<br>
**Status:** OSHWA certified, UID [`UK000092`](https://certification.oshwa.org/uk000092.html); manufactured, assembled and physically validated<br>
**BOM basis:** Published KiCad source and demonstrated carrier assembly

## Scope

This BOM covers the creator-designed Thin-Pod Gateway carrier PCB and the commercial modules and ordinary assembly hardware required to reproduce its functional assembly. Commercial modules remain outside the Gateway open-hardware claim.

## Carrier and modules

| Ref. | Qty | Population | Function | Part / value | Manufacturer / MPN | Interface |
|---|---:|---|---|---|---|---|
| `PCB1` | 1 | Required | Thin-Pod Gateway carrier PCB | Thin-Pod Gateway rev 0.1, manufactured build rev 0.1f | Custom two-layer PCB | Fabricate from `hardware/fabrication/rev0.1/` |
| `U1` | 1 | Required for functional Gateway | Main host and supervisor | STM32 Nucleo-144 board | STMicroelectronics / `NUCLEO-N657X0-Q` | ST Morpho connections through CN3 and CN15 |
| `U2` | 1 | Required for UWB Gateway | Gateway-side UWB subsystem | DWM3001-CDK | Qorvo / `DWM3001CDK` | J10 carrier interface |
| `U3` | 1 | Optional | Onward Wi-Fi/networking subsystem | XIAO ESP32-C6 | Seeed Studio / `XIAO ESP32C6` | XIAO carrier interface |

## Passive components and PCB features

| Ref. | Qty | Function | Part / value | Reproducibility note |
|---|---:|---|---|---|
| `R1` | 1 | DWM chip-select pull-up | 10 kΩ axial through-hole resistor | Any suitably rated compatible part |
| `R2` | 1 | XIAO chip-select pull-up | 10 kΩ axial through-hole resistor | Any suitably rated compatible part |
| `C1` | 1 | Local high-frequency decoupling | 100 nF through-hole ceramic capacitor | Suitable voltage rating |
| `C2` | 1 | Local bulk decoupling | 10 µF through-hole capacitor | Suitable voltage rating and polarity where applicable |
| `C3` | 1 | Local high-frequency decoupling | 100 nF through-hole ceramic capacitor | Suitable voltage rating |
| `C4` | 1 | Local bulk decoupling | 10 µF through-hole capacitor | Suitable voltage rating and polarity where applicable |
| `C5` | 1 | Additional local bulk storage | 22 µF through-hole capacitor | Suitable voltage rating and polarity where applicable |
| `TP1–TP13` | 13 | Electrical test access | Plated through-hole test-point features | Optional probe pins or loops may be fitted |
| `H1–H4` | 4 | Carrier mounting | M3 mounting-hole PCB features | Builder-selected fasteners and standoffs |

## Module mounting and interconnect hardware

Builder-selected pin headers and/or socket strips compatible with the NUCLEO-N657X0-Q ST Morpho interfaces, DWM3001-CDK J10 interface, and optional XIAO ESP32-C6 carrier footprint are used to assemble the carrier. Header brand, plating, socket style and standoff selection are assembly choices outside the carrier-PCB certification scope.

The released PCB geometry and published KiCad footprints define the required pitch, position and mating arrangement. Equivalent mechanically and electrically compatible interconnect hardware may be selected by the builder.

## Electrical interface summary

### NUCLEO to DWM3001-CDK

| Gateway net | NUCLEO endpoint | DWM3001-CDK endpoint |
|---|---|---|
| `SPI5_SCK` | `CN15.11 / PE15` | `J10.23 / SPI1_CLK` |
| `SPI5_MISO` / CIPO | `CN15.13 / PG1` | `J10.21 / SPI1_MISO` |
| `SPI5_MOSI` / COPI | `CN15.15 / PG2` | `J10.19 / SPI1_MOSI` |
| `DWM_CS` | `CN15.17 / PA3` | `J10.24 / CS_RPI` |
| `DWM_IRQ` | `CN15.16 / PB9` | `J10.15 / GPIO_RPI` |
| `DWM_RESET` | `CN15.33 / PD0` | `J10.12 / RESET` |
| `5V_GATEWAY` | `CN3.6 / 5V` | `J10.2 / VRPI` |
| `GND` | Common carrier ground | DWM ground interfaces |

### Optional XIAO ESP32-C6

| Gateway net | NUCLEO endpoint | XIAO endpoint |
|---|---|---|
| `SPI5_SCK` | `CN15.11 / PE15` | `D8 / GPIO19 / SCK` |
| `SPI5_MISO` / CIPO | `CN15.13 / PG1` | `D9 / GPIO20 / MISO` |
| `SPI5_MOSI` / COPI | `CN15.15 / PG2` | `D10 / GPIO18 / MOSI` |
| `C6_CS` | `CN15.19 / PD7` | `D3 / GPIO21` |
| `C6_INT` | `CN15.5 / PC1` | `D2 / GPIO2` |
| `5V_GATEWAY` | `CN3.6 / 5V` | `VBUS / 5V` |
| `GND` | Common carrier ground | `GND` |

## Verification and release reconciliation

The manufactured rev 0.1f carrier has been assembled and demonstrated through stable powered bring-up, NUCLEO-to-DWM host-interface communication, DW3110 identity and initialisation, and a matched Gateway-to-Node UWB exchange. The reconciled rev 0.1 design basis was certified by OSHWA on 16 July 2026 under UID `UK000092`.

The regenerated revision-0.1 Gerber and drill outputs preserve the intended electrical connectivity, board outline, mounting geometry, module-interface positions, test-point arrangement and layer content of the manufactured carrier. Schematic ERC and PCB DRC reports record clean results under `docs/validation/cad/rev0.1/`.

## Open-hardware and third-party boundary

The creator-controlled contribution is the Gateway carrier-board schematic, PCB layout, board-specific interfaces, test access, mechanical arrangement and derived fabrication outputs. U1, U2 and U3 are commercial third-party products and retain their manufacturers' terms.

CAD dependency provenance is recorded in [`docs/footprint-provenance.md`](../../docs/footprint-provenance.md). Creator-authored hardware source is released under `CERN-OHL-W-2.0`; this BOM and related documentation are released under `CC-BY-4.0`.

## Certification record

This reconciled BOM forms part of the Thin-Pod Gateway rev 0.1 public certification package, OSHWA UID [`UK000092`](https://certification.oshwa.org/uk000092.html), issued 16 July 2026.

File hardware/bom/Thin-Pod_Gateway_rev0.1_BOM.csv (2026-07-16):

RefDes | Qty | Population | Category | Function | Manufacturer | Part_or_Value | Manufacturer_Part_Number | Footprint_or_Interface | Supply_or_Net_Context | Open_Hardware_Treatment | Source_or_Product_URL | Verification_Status | Release_Note
PCB1 | 1 | Required | Custom PCB | Thin-Pod Gateway carrier PCB | PCB fabricator | Thin-Pod Gateway rev 0.1; manufactured fabrication build marked rev 0.1f | Custom fabrication item | Two-layer PCB; approximately 160 mm × 145 mm; four M3 mounting holes | Carries 5V_GATEWAY, 3V3_GATEWAY, GND and SPI/control interconnect | Creator-designed Gateway carrier-board source; released under CERN-OHL-W-2.0 |  | Fabricated, assembled, powered and physically validated | Normative source is the certified public rev 0.1 KiCad and fabrication package; OSHWA UID UK000092.
U1 | 1 | Required for functional Gateway assembly | Commercial development board | Main Gateway host and prospective analytic supervisor | STMicroelectronics | STM32 Nucleo-144 development board with STM32N657X0 MCU | NUCLEO-N657X0-Q | Gateway carrier interface through ST morpho-header connections CN3 and CN15 | Provides 5V_GATEWAY from CN3.6; 3V3_GATEWAY from CN3.16; common GND; SPI5/control lines on CN15 | Commercial third-party development board; included for reproducibility, not relicensed | https://www.st.com/en/evaluation-tools/nucleo-n657x0-q.html | Interface mapping, seating, power and NUCLEO-to-DWM host communication physically validated | NUCLEO power route and Gateway interface evidence are recorded in the bring-up and physical-validation documents.
U2 | 1 | Required for UWB Gateway assembly | Commercial UWB development board | Gateway-side UWB communications subsystem | Qorvo | DWM3001-CDK development board | DWM3001CDK | CDK carrier/interface footprint using J10 Raspberry Pi-compatible header connections | 5V_GATEWAY to J10.2 / VRPI; SPI1_CLK/MISO/MOSI, CS_RPI, GPIO_RPI/IRQ, RESET and common GND | Commercial third-party development board; included for reproducibility, not relicensed | https://www.qorvo.com/products/p/DWM3001CDK | Power, ground, RESET, host interface, DW3110 identity and matched UWB exchange physically validated | Rev 0.1 uses the CDK module board; the later DWM3001C chip-down/module-only direction remains outside this certification.
U3 | 1 | Optional for onward-networking assembly | Commercial wireless development module | Optional Wi-Fi / onward-networking subsystem | Seeed Studio | Seeed Studio XIAO ESP32-C6 | XIAO ESP32C6 | XIAO-ESP32-C6-DIP carrier interface | 5V_GATEWAY to pin 14 / VBUS; GND to pin 13; shared SPI5 on D8-D10; C6_CS on D3; C6_INT on D2; pin 12 / 3V3 intentionally not carrier-powered | Commercial third-party module; optional dependency, not relicensed | https://wiki.seeedstudio.com/xiao_esp32c6_getting_started/ | Optional module interface defined; optional-module bring-up remains outside the certified validation baseline | Optional population. Omission does not alter the certified creator-designed carrier-board boundary.
R1 | 1 | Required | Resistor | DWM chip-select pull-up | Generic | 10 kΩ, axial through-hole resistor | Builder-selected compatible 10 kΩ axial resistor | Through-hole axial resistor footprint — confirm exact KiCad identifier from final source | DWM_CS pulled up to 3V3_GATEWAY | Standard commercial component listed for reproducibility |  | Present in certified design and fitted assembly; relevant idle/interface behaviour included in bring-up evidence | Generic compatible assembly part; exact manufacturer selection remains builder-controlled.
R2 | 1 | Required | Resistor | XIAO chip-select pull-up | Generic | 10 kΩ, axial through-hole resistor | Builder-selected compatible 10 kΩ axial resistor | Through-hole axial resistor footprint — confirm exact KiCad identifier from final source | C6_CS pulled up to 3V3_GATEWAY | Standard commercial component listed for reproducibility |  | Present in certified design and fitted assembly; relevant idle/interface behaviour included in bring-up evidence | Generic compatible assembly part; exact manufacturer selection remains builder-controlled.
C1 | 1 | Required | Capacitor | Local high-frequency supply decoupling | Generic | 100 nF, through-hole ceramic capacitor | Builder-selected compatible 100 nF through-hole capacitor | Through-hole capacitor footprint — confirm exact KiCad identifier from final source | Local 5V_GATEWAY decoupling near module load | Standard commercial component listed for reproducibility |  | Present in certified design and fitted assembly; associated rail stability validated during powered bring-up | Exact brand and MPN are non-normative assembly choices.
C2 | 1 | Required | Capacitor | Local bulk supply decoupling | Generic | 10 µF, through-hole capacitor | Builder-selected compatible 10 µF through-hole capacitor | Through-hole capacitor footprint — confirm exact KiCad identifier from final source | Local 5V_GATEWAY bulk decoupling near module load | Standard commercial component listed for reproducibility |  | Present in certified design and fitted assembly; associated rail stability validated during powered bring-up | Observe polarity where a polarised part is selected; exact brand and MPN are non-normative.
C3 | 1 | Required | Capacitor | Local high-frequency supply decoupling | Generic | 100 nF, through-hole ceramic capacitor | Builder-selected compatible 100 nF through-hole capacitor | Through-hole capacitor footprint — confirm exact KiCad identifier from final source | Local 5V_GATEWAY decoupling near module load | Standard commercial component listed for reproducibility |  | Present in certified design and fitted assembly; associated rail stability validated during powered bring-up | Exact brand and MPN are non-normative assembly choices.
C4 | 1 | Required | Capacitor | Local bulk supply decoupling | Generic | 10 µF, through-hole capacitor | Builder-selected compatible 10 µF through-hole capacitor | Through-hole capacitor footprint — confirm exact KiCad identifier from final source | Local 5V_GATEWAY bulk decoupling near module load | Standard commercial component listed for reproducibility |  | Present in certified design and fitted assembly; associated rail stability validated during powered bring-up | Observe polarity where a polarised part is selected; exact brand and MPN are non-normative.
C5 | 1 | Required | Capacitor | Additional local bulk energy storage | Generic | 22 µF, through-hole capacitor | Builder-selected compatible 22 µF through-hole capacitor | Through-hole capacitor footprint — confirm exact KiCad identifier from final source | Additional XIAO-side / radio-load bulk decoupling on Gateway supply path | Standard commercial component listed for reproducibility |  | Present in certified design and fitted assembly; associated rail stability validated during powered bring-up | Observe polarity where a polarised part is selected; exact brand and MPN are non-normative.
TP1 | 1 | PCB feature / optional fitted probe pin | Test point | DWM-side ground reference | N/A / optional generic hardware | GND_DWM |  | Through-hole test-point footprint | DWM ground-reference observation | Creator-designed PCB feature; optional commercial pin if fitted |  | Present in certified design; corresponding rail or signal path included in continuity/bring-up evidence where used | PCB test-access feature; a fitted commercial probe pin is optional.
TP2 | 1 | PCB feature / optional fitted probe pin | Test point | Gateway 5 V rail measurement | N/A / optional generic hardware | 5V_GATEWAY |  | Through-hole test-point footprint | 5V_GATEWAY | Creator-designed PCB feature; optional commercial pin if fitted |  | Present in certified design; corresponding rail or signal path included in continuity/bring-up evidence where used | PCB test-access feature; a fitted commercial probe pin is optional.
TP3 | 1 | PCB feature / optional fitted probe pin | Test point | XIAO-side ground reference | N/A / optional generic hardware | GND_C6 |  | Through-hole test-point footprint | XIAO ground-reference observation | Creator-designed PCB feature; optional commercial pin if fitted |  | Present in certified design; corresponding rail or signal path included in continuity/bring-up evidence where used | XIAO-side ground test access remains valid even when the optional XIAO is unfitted.
TP4 | 1 | PCB feature / optional fitted probe pin | Test point | Gateway auxiliary / pull-up rail measurement | N/A / optional generic hardware | 3V3_GATEWAY |  | Through-hole test-point footprint | 3V3_GATEWAY | Creator-designed PCB feature; optional commercial pin if fitted |  | Present in certified design; corresponding rail or signal path included in continuity/bring-up evidence where used | Auxiliary/pull-up rail; it is not the XIAO power input.
TP5 | 1 | PCB feature / optional fitted probe pin | Test point | DWM reset observation/control | N/A / optional generic hardware | DWM_RESET |  | Through-hole test-point footprint | NUCLEO CN15.33 / PD0 to DWM J10.12 / RESET | Creator-designed PCB feature; optional commercial pin if fitted |  | Present in certified design; corresponding rail or signal path included in continuity/bring-up evidence where used | RESET evidence is recorded in the hardware bring-up note.
TP6 | 1 | PCB feature / optional fitted probe pin | Test point | DWM interrupt/data-ready observation | N/A / optional generic hardware | DWM_IRQ |  | Through-hole test-point footprint | NUCLEO CN15.16 / PB9 to DWM J10.15 / GPIO_RPI | Creator-designed PCB feature; optional commercial pin if fitted |  | Present in certified design; corresponding rail or signal path included in continuity/bring-up evidence where used | READY/IRQ evidence is recorded in the hardware bring-up note.
TP7 | 1 | PCB feature / optional fitted probe pin | Test point | DWM chip-select observation | N/A / optional generic hardware | DWM_CS |  | Through-hole test-point footprint | NUCLEO CN15.17 / PA3 to DWM J10.24 / CS_RPI; pulled up by R1 | Creator-designed PCB feature; optional commercial pin if fitted |  | Present in certified design; corresponding rail or signal path included in continuity/bring-up evidence where used | DWM host-interface evidence is recorded in the physical validation note.
TP8 | 1 | PCB feature / optional fitted probe pin | Test point | XIAO chip-select observation | N/A / optional generic hardware | C6_CS |  | Through-hole test-point footprint | NUCLEO CN15.19 / PD7 to XIAO D3 / GPIO21; pulled up by R2 | Creator-designed PCB feature; optional commercial pin if fitted |  | Present in certified design; corresponding rail or signal path included in continuity/bring-up evidence where used | PCB test-access feature retained for optional onward-networking work.
TP9 | 1 | PCB feature / optional fitted probe pin | Test point | XIAO interrupt/data-ready observation | N/A / optional generic hardware | C6_INT |  | Through-hole test-point footprint | NUCLEO CN15.5 / PC1 to XIAO D2 / GPIO2 | Creator-designed PCB feature; optional commercial pin if fitted |  | Present in certified design; corresponding rail or signal path included in continuity/bring-up evidence where used | PCB test-access feature retained for optional onward-networking work.
TP10 | 1 | PCB feature / optional fitted probe pin | Test point | Shared SPI clock observation | N/A / optional generic hardware | SPI5_SCK |  | Through-hole test-point footprint | NUCLEO CN15.11 / PE15 to DWM J10.23 and XIAO D8 / GPIO19 | Creator-designed PCB feature; optional commercial pin if fitted |  | Present in certified design; corresponding rail or signal path included in continuity/bring-up evidence where used | Shared route includes the optional XIAO branch; DWM-side operation is validated.
TP11 | 1 | PCB feature / optional fitted probe pin | Test point | Shared SPI MOSI observation | N/A / optional generic hardware | SPI5_MOSI |  | Through-hole test-point footprint | NUCLEO CN15.15 / PG2 to DWM J10.19 and XIAO D10 / GPIO18 | Creator-designed PCB feature; optional commercial pin if fitted |  | Present in certified design; corresponding rail or signal path included in continuity/bring-up evidence where used | Shared route includes the optional XIAO branch; DWM-side operation is validated.
TP12 | 1 | PCB feature / optional fitted probe pin | Test point | Shared SPI MISO observation | N/A / optional generic hardware | SPI5_MISO |  | Through-hole test-point footprint | NUCLEO CN15.13 / PG1 to DWM J10.21 and XIAO D9 / GPIO20 | Creator-designed PCB feature; optional commercial pin if fitted |  | Present in certified design; corresponding rail or signal path included in continuity/bring-up evidence where used | Shared route includes the optional XIAO branch; DWM-side operation is validated.
TP13 | 1 | PCB feature / optional fitted probe pin | Test point | NUCLEO 5 V source-rail confirmation | N/A / optional generic hardware | 5V_NUCLEO |  | Through-hole test-point footprint | Source confirmation for 5V_GATEWAY derived from NUCLEO supply path | Creator-designed PCB feature; optional commercial pin if fitted |  | Present in certified design; corresponding rail or signal path included in continuity/bring-up evidence where used | Source-rail evidence is recorded in the hardware bring-up note.
H1–H4 | 4 | PCB feature; mounting hardware optional | Mechanical feature | Carrier-board mounting holes | N/A for drilled feature | M3 mounting holes |  | Mounting-hole footprints — confirm exact KiCad identifiers from final source | Mechanical only | Creator-designed PCB mechanical features; standoffs/fasteners are commercial items if selected |  | PCB mounting features present in manufactured carrier; installation hardware remains builder-selected | Exact standoff and fastener selection is installation dependent and outside the carrier-PCB certification scope.
ASSEMBLY-IF | As required | Required according to chosen module mounting method | Interconnect hardware | Headers / sockets required to mate commercial modules to the Gateway carrier PCB | To be selected | Pin headers and/or receptacle/socket strips matching U1, U2 and fitted U3 interfaces | Builder-selected compatible headers and/or socket strips | Determined by carrier-board module footprints and stacking/clearance arrangement | Mechanical and electrical mating of commercial modules | Commercial assembly hardware; not relicensed |  | Compatible assembly interface selected and demonstrated on the validated carrier assembly | Builder-selected equivalent mechanically and electrically compatible headers or sockets are permitted.

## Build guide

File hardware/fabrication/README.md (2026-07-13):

# Thin-Pod Gateway rev 0.1 fabrication outputs

This directory contains the derived fabrication release for the Thin-Pod Gateway rev 0.1 carrier PCB.

## Published package

```text
hardware/fabrication/rev0.1/Thin-Pod_Gateway_rev0.1_fabrication.zip
SHA-256: 3e51d68cb120c55aa06f386f4c433a48845a45d1cb986b2b08ac874ea5ec2d4d
Size: 114,303 bytes
```

The archive contains 14 manufacturing files: top and bottom copper, solder mask, paste and silkscreen Gerbers; the board profile; PTH and NPTH drill files; PTH and NPTH drill maps; and a Gerber job file.

## Fabrication metadata

The release Gerber job records:

| Property | Value |
|---|---|
| Generator | KiCad Pcbnew 10.0.1 |
| Generation date | 13 July 2026, 12:29:39 +01:00 |
| Project revision | `0.1` |
| Board size | 160.05 mm × 145.05 mm |
| Copper layers | 2 |
| Board thickness | 1.6 mm |
| Dielectric | FR4, 1.51 mm recorded |
| Copper thickness | 0.035 mm per outer layer |
| Minimum track width/spacing | 0.2 mm |
| PTH drill hits | 244 |
| NPTH drill hits | 9 |

The release package was regenerated after the schematic and PCB title-block revision was set to `0.1` and the KiCad output path was made repository-relative. The release freeze should still record ERC, DRC and Gerber-viewer inspection, together with confirmation that these metadata and portability changes introduced no intentional electrical or geometric change from the manufactured rev 0.1f carrier.

## Source relationship

The corresponding native KiCad source is published under:

```text
hardware/source/kicad/rev0.1/
```

The editable KiCad project is the normative design source. These Gerber and drill files are derived manufacturing outputs supplied for convenience and reproducibility.

See [`RELEASE-MANIFEST.md`](RELEASE-MANIFEST.md) for hashes and [`../source/README.md`](../source/README.md) for source status and remaining validation work.

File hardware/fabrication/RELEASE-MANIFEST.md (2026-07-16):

# Thin-Pod Gateway rev 0.1 Release and Fabrication Manifest

**Release status:** OSHWA-certified public rev 0.1 baseline<br>
**OSHWA UID:** [`UK000092`](https://certification.oshwa.org/uk000092.html)<br>
**Certification date:** 16 July 2026<br>
**Canonical release tag:** `v0.1`<br>
**Hardware family:** Thin-Pod Gateway rev 0.1<br>
**Fabrication-build identity:** rev 0.1 / manufactured-board marking rev 0.1f where present<br>
**Release archive:** `hardware/fabrication/rev0.1/Thin-Pod_Gateway_rev0.1_fabrication.zip`<br>
**Archive SHA-256:** `3e51d68cb120c55aa06f386f4c433a48845a45d1cb986b2b08ac874ea5ec2d4d`<br>
**Archive size:** 114,303 bytes<br>
**Generator recorded by package:** KiCad Pcbnew 10.0.1<br>
**Generation timestamp:** 2026-07-13T12:29:39+01:00<br>
**Project revision recorded by Gerber job:** `0.1`

## File inventory

| File | Bytes | SHA-256 | Function |
|---|---:|---|---|
| `Thin-Pod Gateway-F_Cu.gbr` | 31,714 | `d53ecf1dcd7c5785a7a7fc6143ffa8b5bdc0befad1e07c39fe1dc3aee664d8ae` | Top copper |
| `Thin-Pod Gateway-B_Cu.gbr` | 318,882 | `a2cdf633cf8ac7402bfa648f41ed1f6e2865463d733e7ed4d25d74827f5d0cc4` | Bottom copper |
| `Thin-Pod Gateway-F_Mask.gbr` | 8,792 | `4006df558baa3d8b32d5b2e37b87dd932b5ddfca58e697babdd12722668dd043` | Top solder mask |
| `Thin-Pod Gateway-B_Mask.gbr` | 7,497 | `7e397fec2e413123703999820a5e582f58c4baf0796576630afe5329f3108224` | Bottom solder mask |
| `Thin-Pod Gateway-F_Paste.gbr` | 475 | `877ed2a93545d4eabdc8f0e34bf01fb03dcf937f09013d3f81f8fc6e5426fb52` | Top solder paste |
| `Thin-Pod Gateway-B_Paste.gbr` | 475 | `d02550a28dab085ef9a43730f1a463dc945aebc4ab5feac473a34ed8cbe1b76b` | Bottom solder paste |
| `Thin-Pod Gateway-F_Silkscreen.gbr` | 54,296 | `43ccb841c19d5442a63f25fede90486f6809dc8b6f8b45a0b0914ab151bc64a2` | Top legend |
| `Thin-Pod Gateway-B_Silkscreen.gbr` | 476 | `9df9ca770cfdaf16d5be41a48b017ca21640a0c1776d81031d473013db6641cb` | Bottom legend |
| `Thin-Pod Gateway-Edge_Cuts.gbr` | 880 | `70209bca86ac737d28adab44c9e2b96f6b5566bc91eb5fdad739d55ac1248ea6` | Board profile |
| `Thin-Pod Gateway-PTH.drl` | 4,985 | `8dfbf0d564c35edac91340e6aa42c1717f36a19cf655086a7c6fcc7eef35f243` | Plated drill data |
| `Thin-Pod Gateway-NPTH.drl` | 561 | `fe3a21e4f43f74fa8db504e04c258274c24c9a537797563c814edfbabe1a87b6` | Non-plated drill data |
| `Thin-Pod Gateway-PTH-drl_map.gbr` | 134,923 | `492f01252aa097a44e9ac1c7e79720999adaf1112be062e6ec2c6b3435db5c1b` | PTH drill map |
| `Thin-Pod Gateway-NPTH-drl_map.gbr` | 41,673 | `fda6dc4ef0539f90b781fd966e27fa389fdfca0385531bcc9b7161dfa6558271` | NPTH drill map |
| `Thin-Pod Gateway-job.gbrjob` | 2,896 | `795904a9500c31edf20cb09ecccc22a65c2a70b8135fdc3cffeed287f6c986bf` | Gerber job metadata |

## Native source inventory

| File | Bytes | SHA-256 |
|---|---:|---|
| `hardware/source/kicad/rev0.1/Thin-Pod Gateway.kicad_pro` | 15,837 | `d93b70403ad736d2e7d07ddffba312bf5544fadb74fdcd4fb3fcb8de90163d13` |
| `hardware/source/kicad/rev0.1/Thin-Pod Gateway.kicad_sch` | 186,604 | `6cfe02408b4071275b44bfcb8ee031cb30589e9aa85f7ce8fe3c587f5354a685` |
| `hardware/source/kicad/rev0.1/Thin-Pod Gateway.kicad_pcb` | 511,755 | `50ca43bfd5fa709f13785a92ca706bf4c4f41bb3bd32f28f012f2a7ffb4db47d` |

## Drill summary

### Plated holes

| Diameter | Hits |
|---:|---:|
| 0.300 mm | 24 |
| 0.700 mm | 10 |
| 0.800 mm | 14 |
| 0.889 mm | 14 |
| 1.000 mm | 151 |
| 1.016 mm | 28 |
| 3.000 mm | 3 |
| **Total** | **244** |

### Non-plated holes

| Diameter | Hits |
|---:|---:|
| 3.000 mm | 5 |
| 3.200 mm | 4 |
| **Total** | **9** |

## Release and certification result

The native KiCad source, individual Gerber and drill files, Gerber job and binary fabrication archive are committed together. The job metadata records revision `0.1`, resolving the earlier `rev?` release defect.

The release package has completed the recorded certification gates:

1. clean KiCad 10 source opening and source-resolution review;
2. schematic ERC and PCB DRC with zero reported blocking results;
3. Gerber and drill inspection;
4. symbol and footprint provenance documentation;
5. BOM reconciliation with the release assembly basis;
6. confirmation that the regenerated package preserves the intended electrical and geometric design of the manufactured rev 0.1f board; and
7. immutable public release freeze under tag `v0.1`.

This source and fabrication identity forms part of the Thin-Pod Gateway rev 0.1 certification record, OSHWA UID [`UK000092`](https://certification.oshwa.org/uk000092.html), issued 16 July 2026.

## Post-certification maintenance

Any change to the released schematic, PCB layout, copper, board outline, mounting geometry or module-interface design requires a later hardware revision. Documentation-only corrections should preserve the file hashes and certified rev 0.1 hardware identity recorded here.

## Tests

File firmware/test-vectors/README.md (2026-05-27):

# Thin-Pod Shared Firmware Test Vectors

**Directory:** `firmware/test-vectors/`  
**Purpose:** Store deterministic binary records, metadata and verification scripts shared by node, Gateway DWM and NUCLEO firmware tests  
**Status:** Test-vector contract defined; vector files to be generated and committed during firmware implementation  
**Document date:** 27 May 2026  
**Protocol basis:** `TPHIP-1`

## Purpose

This directory is the single shared source of truth for deterministic data-path verification.

The first vector proves an essential fact before sensor acquisition or UWB transport is involved:

> A complete known raw-window record created or exposed by Gateway-side DWM firmware can be read into NUCLEO memory and verified byte-for-byte under the `TPHIP-1` record contract.

Every implementation should use the same binary input and expected integrity result. No firmware endpoint should be considered interoperable merely because it transfers a similar-looking buffer.

## Planned contents

```text
test-vectors/
├── README.md
├── golden-window-v1.bin
├── golden-window-v1-metadata.md
└── crc-reference.py
```

| File | Role |
|---|---|
| `golden-window-v1.bin` | Canonical 4160-byte binary `SYNTHETIC_WINDOW` record |
| `golden-window-v1-metadata.md` | Human-readable identity, field layout, CRC and hash record for the vector |
| `crc-reference.py` | Deterministic generator and validator for the binary record and CRC |

The README file defines the vector now. The binary vector, metadata document and script should be generated and committed as the next firmware-preparation task.

## Golden vector definition

### Complete record

| Quantity | Value |
|---|---:|
| Record version | `1` |
| Message type | `SYNTHETIC_WINDOW` (`1`) |
| Header size | `64` bytes |
| Sample representation | Signed 16-bit little-endian |
| Sample count | `2048` |
| Payload size | `4096` bytes |
| Complete record size | `4160` bytes |
| Expected CRC-32 | `0x0B1D48B2` |

### Header fields

| Field | Golden value |
|---|---:|
| `magic` | ASCII `TPWN` |
| `record_version` | `1` |
| `message_type` | `1` |
| `header_bytes` | `64` |
| `sample_format` | `1` |
| `node_id` | `1` |
| `window_sequence` | `1` |
| `sample_rate_hz` | `25600` |
| `sample_count` | `2048` |
| `payload_bytes` | `4096` |
| `sensor_id` | `0` |
| `calibration_version` | `0` |
| `acquisition_flags` | `1` (`SYNTHETIC`) |
| `node_tick` | `0` |
| `node_firmware_build_id` | `1` |
| `record_total_bytes` | `4160` |
| `record_crc32` | `0x0B1D48B2` |

The `sample_rate_hz` value is protocol-test metadata. It must not be read as evidence that 25.6 ksample/s is a qualified ADXL1005 measurement mode.

## Payload generation rule

The payload is a deterministic repeated signed-ramp sequence:

```python
samples = [(i % 1024) - 512 for i in range(2048)]
payload = b"".join(struct.pack("<h", sample) for sample in samples)
```

This produces 2048 signed 16-bit samples and exactly 4096 payload bytes.

First sixteen payload bytes:

```text
00 FE 01 FE 02 FE 03 FE 04 FE 05 FE 06 FE 07 FE
```

Last sixteen payload bytes:

```text
F8 01 F9 01 FA 01 FB 01 FC 01 FD 01 FE 01 FF 01
```

## CRC definition

The vector uses CRC-32/ISO-HDLC as implemented by standard ZIP/Ethernet-compatible CRC-32 routines such as Python `zlib.crc32`.

CRC coverage is:

```text
header bytes 0–59
followed immediately by
payload bytes 64–4159
```

The four CRC-storage bytes at header offsets 60–63 are excluded from the CRC calculation.

Expected result:

```text
record_crc32 = 0x0B1D48B2
```

## Reference-script requirements

`crc-reference.py` should:

1. construct the exact 60-byte header-before-CRC;
2. generate the 4096-byte deterministic payload;
3. calculate the record CRC;
4. assert that the CRC is `0x0B1D48B2`;
5. assemble and write the 4160-byte binary record;
6. assert the final binary size;
7. optionally calculate a SHA-256 artifact hash;
8. support verifying an existing `golden-window-v1.bin`; and
9. print clear pass/fail output for engineering use.

The reference script is an evidence-generation tool. It should remain short, deterministic and dependency-light.

## Use by firmware areas

| Firmware area | Required use of vector |
|---|---|
| `../gateway-dwm/tphip-golden-record/` | Generate or expose the canonical record from Gateway-side DWM firmware |
| `../nucleo-host/tphip-reader/` | Read, reconstruct, validate and compare received bytes against canonical vector |
| `../node-dwm/` | Not required for first vector; may later generate separate sensor/acquisition test records |

## Initial acceptance tests

| Test | Pass condition |
|---|---|
| Reference vector generation | Binary output is 4160 bytes; CRC is `0x0B1D48B2` |
| Gateway DWM local generation | Firmware reports same CRC for locally generated canonical record |
| NUCLEO reconstruction | Received record byte-for-byte equals `golden-window-v1.bin` |
| Repeatability | 100 accepted transfers contain no unexplained CRC/length/sequence error |
| Withheld ACK | DWM retains unresolved record and does not overwrite it |
| Corruption injection | Modified byte causes validation failure and prevents valid DSP publication |

## Metadata file content requirement

When `golden-window-v1.bin` is generated, `golden-window-v1-metadata.md` should record:

| Metadata | Required value |
|---|---|
| Generator script revision | Commit/build identity |
| Vector file name | `golden-window-v1.bin` |
| Binary length | `4160` bytes |
| Record CRC-32 | `0x0B1D48B2` |
| SHA-256 | Calculate from committed binary |
| Header field table | As defined in this README |
| Payload generation rule | As defined in this README |
| Intended tests | DWM generation, NUCLEO receipt and fault injection |
| Limitations | Synthetic vector; no physical sensor or UWB claim |

## Non-claims

The golden vector proves protocol-level data preservation only. It is not:

- an ADXL1005 measurement;
- evidence of ADC fidelity;
- evidence of UWB record reception;
- a calibrated acceleration dataset;
- a DSP result; or
- a TinyML training or inference dataset.

## Immediate next action

Create `crc-reference.py`, generate `golden-window-v1.bin`, calculate its SHA-256 hash and record the results in `golden-window-v1-metadata.md`. Those three files then become the deterministic common input for Gateway-DWM and NUCLEO-host implementation work.

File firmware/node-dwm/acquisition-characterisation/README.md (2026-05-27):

# Node Acquisition Characterisation Workspace

**Directory:** `firmware/node-dwm/acquisition-characterisation/`  
**Purpose:** Preserve configuration, captures and evidence for digitising the external ADXL1005 analogue signal through the node-side nRF52833 SAADC  
**Status:** Prepared for first acquisition experiments; no digital measurement record yet claimed  
**Document date:** 27 May 2026

## Purpose

This directory is the working evidence area for the first serious acquisition question in Thin-Pod:

> **Can the external ADXL1005 analogue path be captured digitally through the node-side DWM3001/nRF52833 route as a stable and useful raw vibration record?**

The work here precedes claims about UWB transport, Gateway DSP or TinyML. It establishes whether the measurement record being transported is credible.

## Scope

This workspace covers:

- ADC pin and firmware-configuration confirmation;
- raw ADC captures of the external ADXL1005 channel;
- resting/noise/mechanical-response characterisation;
- radio-interference comparison;
- sampling-rate and anti-alias investigation;
- record metadata and archive hashes; and
- the decision whether nRF52833 acquisition is qualified for a stated band or should later be replaced/supplemented by a dedicated ADC.

It does not treat the DWM3001C module’s integrated motion sensor as the main Thin-Pod measurement channel.

## Controlling document

The controlling specification is:

```text
../../../docs/node-acquisition-and-sampling-contract.md
```

The first captures must be labelled:

```text
CHARACTERISATION / UNCALIBRATED
```

unless and until a later qualification/calibration record supports a stronger description.

## Suggested evidence structure

```text
acquisition-characterisation/
├── README.md
│
├── configurations/
│   ├── ACQ-CONFIG-0001.md
│   └── ACQ-CONFIG-0001.json
│
├── captures/
│   └── <session-id>/
│       ├── session-manifest.json
│       ├── rest-window-0001.tpwn
│       ├── background-window-0001.tpwn
│       ├── tap-window-0001.tpwn
│       ├── radio-idle-window-0001.tpwn
│       ├── radio-active-window-0001.tpwn
│       └── hashes.sha256
│
├── analysis/
│   └── <session-id>/
│       ├── first-look.md
│       ├── basic-statistics.csv
│       └── spectrum-observations.md
│
└── evidence/
    └── <session-id>/
        ├── bench-notes.md
        ├── oscilloscope/
        └── screenshots/
```

The `.tpwn` extension is reserved for Thin-Pod complete raw-window records conforming to a recorded record version. Before that binary format is implemented, early temporary capture files must be clearly identified as preliminary and mapped into the final record model later.

## Acquisition configuration record

Create one acquisition-configuration record before relying on any captured data.

### Minimum configuration fields

| Field | Value to record |
|---|---|
| Configuration ID | e.g. `ACQ-CONFIG-0001` |
| Date | Test date |
| Node hardware revision | `Thin-Pod rev 0.1` |
| Node instance ID | Assign when testing begins |
| Sensor channel | External ADXL1005 path |
| Sensor supply voltage | Measured during test |
| Analogue resting voltage | Measured during test |
| Analogue filter | `8 kΩ / 680 pF`, nominal approximately 29.3 kHz corner for rev 0.1, unless changed |
| DWM/CDK identity | Record unit used |
| nRF52833 ADC input/channel | Confirm against firmware and schematic |
| SAADC reference/gain/range | Exact firmware setting |
| Acquisition time / oversampling | Exact firmware setting |
| Sampling method | Timer/event/DMA behaviour |
| Sample rate | Exact configured value |
| Sample count | Initially 2048 where using record target |
| Record/sample format | ADC code representation |
| Radio state | Inactive, active, or controlled comparison |
| Qualification state | Initially `CHARACTERISATION / UNCALIBRATED` |
| Firmware build ID | Commit/build identity |
| Known limitations | Filtering, mounting, clipping or uncertainty notes |

## Test sequence

### A. Electrical sanity

| Test ID | Action | Pass condition |
|---|---|---|
| ACQ-A001 | Confirm ADC pin/net mapping | Firmware pin corresponds to external Thin-Pod ADC node |
| ACQ-A002 | Measure sensor rail and resting analogue voltage | Values recorded; input is within configured ADC range |
| ACQ-A003 | Capture resting ADC codes | Digital mean broadly corresponds to measured analogue voltage |
| ACQ-A004 | Check for obvious clipping or stuck values | No unexplained saturation/static behaviour |

### B. First raw windows

| Test ID | Action | Pass condition |
|---|---|---|
| ACQ-B001 | Capture 2048-sample resting record | Record retained with metadata and integrity check |
| ACQ-B002 | Capture stable-background/no-motion record | Initial noise record available |
| ACQ-B003 | Capture controlled tap/mechanical excitation | Digital record shows plausible mechanical response |
| ACQ-B004 | Repeat capture | Response and background behaviour are reproducible enough to continue |

### C. Radio-interference comparison

| Test ID | Action | Pass condition |
|---|---|---|
| ACQ-C001 | Capture with UWB/radio inactive | Baseline record established |
| ACQ-C002 | Capture during or adjacent to radio activity | Difference recorded visibly, whether benign or problematic |
| ACQ-C003 | Decide capture/transmit scheduling position | Time separation adopted if radio activity contaminates acquisition |

### D. Bandwidth and ADC architecture decision

| Test ID | Action | Outcome sought |
|---|---|---|
| ACQ-D001 | Known low-frequency excitation | Validate initial restricted-band response |
| ACQ-D002 | Sweep through a candidate 0–5 kHz mode where equipment permits | Determine whether low-band qualification is credible |
| ACQ-D003 | Examine 10 kHz and higher only with controlled filtering/test arrangement | Assess moderate/high-band feasibility |
| ACQ-D004 | Compare with reference scope/ADC record where practical | Quantify loss/noise/distortion |
| ACQ-D005 | Make retain-or-revise ADC decision | State qualified band or recommend later dedicated ADC |

## First-session manifest template

```json
{
  "session_id": "TP-ACQ-2026-0001",
  "purpose": "First external ADXL1005 digital acquisition characterisation",
  "node_hardware_revision": "TP-NODE-R0.1",
  "node_instance_id": "TO_BE_ASSIGNED",
  "sensor_identity": "External ADXL1005 channel",
  "qualification_state": "CHARACTERISATION_UNCALIBRATED",
  "adc_device": "nRF52833 SAADC",
  "adc_input_channel": "TO_BE_CONFIRMED",
  "adc_configuration": {
    "reference": "TO_BE_CONFIRMED",
    "gain": "TO_BE_CONFIRMED",
    "acquisition_time": "TO_BE_CONFIRMED",
    "oversampling": "TO_BE_CONFIRMED"
  },
  "analogue_filter": {
    "series_resistor_ohms": 8000,
    "capacitor_farads": 6.8e-10,
    "nominal_corner_hz": 29257
  },
  "sample_rate_hz": "TO_BE_CONFIRMED",
  "sample_count": 2048,
  "radio_state_during_capture": "INACTIVE_FOR_BASELINE",
  "node_firmware_build": "TO_BE_RECORDED",
  "notes": ""
}
```

## Initial analysis expectations

Initial characterisation analysis should remain deliberately modest.

| Analysis | Purpose |
|---|---|
| Mean ADC code / corresponding voltage estimate | Confirm bias/rest position |
| Minimum and maximum ADC code | Detect clipping or unexpected range |
| RMS around mean | Baseline noise/energy indicator |
| Time-domain plot | Confirm mechanical response visibly |
| Simple FFT/spectrum | Reveal gross interference, spur or alias behaviour |
| Comparison between radio-idle and radio-active captures | Establish scheduling/contamination decision |

Do not present early feature values as calibrated machine-health results.

## Evidence acceptance statement

The first meaningful success for this directory is:

> A bounded digital record derived from the external ADXL1005 channel has been captured by node-side firmware, stored with explicit ADC/sample/filter metadata, shown to respond to mechanical excitation and labelled accurately as characterisation evidence.

A later qualification decision must state the measurement bandwidth and conditions supported by the evidence. Where the nRF52833 SAADC path proves inadequate for the intended bandwidth/noise goal, this directory should preserve that finding as the justification for a later dedicated-ADC node revision.

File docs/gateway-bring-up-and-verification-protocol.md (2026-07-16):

# Thin-Pod Gateway rev 0.1: Bring-Up and Verification Protocol

**Product:** Thin-Pod Gateway<br>
**Release path:** rev 0.1<br>
**Ordered fabrication-build identifier:** `rev 0.1f`, where present on the manufactured PCB/silkscreen<br>
**Board state at preparation:** PCB ordered; arrival and assembly were pending<br>
**Current status:** Protocol completed through the recorded rev 0.1 bring-up evidence; OSHWA UID `UK000092` issued 16 July 2026<br>

> **Historical protocol status (16 July 2026):** This document preserves the original commissioning plan and blank/pending worksheets. Completed bring-up evidence is recorded in [`docs/bringup/Gateway_rev0_1_Hardware_Bringup_Note.md`](bringup/Gateway_rev0_1_Hardware_Bringup_Note.md), and the released carrier is OSHWA-certified as [`UK000092`](https://certification.oshwa.org/uk000092.html).

**Document status:** Test protocol prepared before board arrival<br>
**Document date:** 27 May 2026<br>

## 1. Purpose

This document defines the staged bring-up protocol for the first manufactured **Thin-Pod Gateway rev 0.1** carrier PCB. Its role is to ensure that the board is verified as hardware before firmware or system-level work obscures basic electrical faults.

The Gateway is a separate hardware artefact from the already submitted **Thin-Pod rev 0.1** sensor-node carrier PCB. Nothing in this protocol extends or modifies the submitted sensor-node OSHWA certification boundary.

The immediate verification objectives are:

1. confirm that the fabricated carrier PCB corresponds physically to the intended NUCLEO, DWM3001-CDK and XIAO footprints;
2. confirm power, ground, pull-up and host-interface routing before fitting modules;
3. power modules in controlled stages;
4. establish an electrically trusted path on which host-interface firmware tests can later be performed; and
5. collect the evidence needed for a possible later OSHWA certification submission for **Thin-Pod Gateway rev 0.1**.

## 2. Hardware under test

The ordered Gateway carrier-board design is intended to hold:

| Reference | Hardware | Functional role |
|---|---|---|
| `U1` | STM32 `NUCLEO-N657X0-Q` | Main host and prospective DSP/TinyML supervisor |
| `U2` | Qorvo `DWM3001-CDK` | Gateway-side UWB development board |
| `U3` | Seeed Studio `XIAO ESP32-C6` | Optional onward-networking subsystem |
| `R1`, `R2` | 10 kΩ pull-ups | Chip-select idle-state control |
| `C1`, `C3` | 100 nF capacitors | Local high-frequency decoupling |
| `C2`, `C4` | 10 µF capacitors | Local bulk decoupling |
| `C5` | 22 µF capacitor | Additional local supply reserve |
| `TP1`–`TP13` | Test points | Power, reset, interrupt and SPI observability |
| `H1`–`H4` | M3 mounting holes | Mechanical support |

The ordered PCB has previously been recorded as an approximately 160 mm × 145 mm, two-layer carrier-board prototype with a bottom-copper `GND` zone and a fabrication/silkscreen identity including `rev 0.1f`. Before OSHWA release, this physical build identity must be reconciled to the public Gateway rev 0.1 release record.

## 3. Design intent to be verified

### 3.1 Power distribution

| Net / connection | Design intent | Verification status |
|---|---|---|
| `5V_GATEWAY` from NUCLEO `CN3.6` | Powers DWM3001-CDK 5 V input route and XIAO `5V/VBUS` | Pending physical test |
| `3V3_GATEWAY` from NUCLEO `CN3.16` | Provides pull-up/auxiliary 3.3 V rail | Pending physical test |
| Common `GND` | Ties NUCLEO, DWM3001-CDK, XIAO, passive returns and test points together | Pending physical test |
| XIAO `3V3` pin | Left unconnected as a power input in the carrier-board design | Pending continuity check |

### 3.2 NUCLEO-to-DWM3001-CDK route

| Signal | NUCLEO connection | DWM3001-CDK connection | Purpose |
|---|---|---|---|
| `SPI5_SCK` | `CN15.11` / `PE15` | `J10.23` / `SPI1_CLK` | Host clock route |
| `SPI5_MISO` | `CN15.13` / `PG1` | `J10.21` / `SPI1_MISO` | Module-to-host data route |
| `SPI5_MOSI` | `CN15.15` | `J10.19` / `SPI1_MOSI` | Host-to-module data route |
| `DWM_CS` | `CN15.17` | `J10.24` / `CS_RPI` | DWM chip-select/control route |
| `DWM_IRQ` | `CN15.16` | `J10.15` | DWM interrupt/GPIO route |
| `DWM_RESET` | `CN15.33` | `J10.12` | DWM reset route |

This is a physical route to the DWM3001-CDK interface. Whether it supports the desired framed-buffer exchange is a firmware/protocol verification question and must not be assumed solely from continuity.

### 3.3 NUCLEO-to-XIAO ESP32-C6 route

| Signal | NUCLEO connection | XIAO connection | Purpose |
|---|---|---|---|
| `SPI5_SCK` | `CN15.11` | `D8` / `GPIO19` / `SCK` | Shared SPI clock |
| `SPI5_MISO` | `CN15.13` | `D9` / `GPIO20` / `MISO` | Shared SPI data route |
| `SPI5_MOSI` | `CN15.15` | `D10` / `GPIO18` / `MOSI` | Shared SPI data route |
| `C6_CS` | `CN15.19` | `D3` / `GPIO21` | Separate chip-select route |
| `C6_INT` | `CN15.5` | `D2` / `GPIO2` | Interrupt/control route |
| `5V_GATEWAY` | `CN3.6` | `5V/VBUS` | XIAO power-input route |
| `GND` | Common reference | `GND` | Ground return |

## 4. Required equipment

| Equipment | Purpose |
|---|---|
| Digital multimeter with continuity and resistance modes | Unpowered continuity, resistance and voltage checks |
| Current-limited power source / correct NUCLEO power arrangement | Controlled powered bring-up |
| Oscilloscope | Rail behaviour and later SPI/control-line observation |
| Logic analyser, where available | SPI/control-line capture during firmware stages |
| ESD-safe work area | Protection of development modules |
| Camera / phone camera | Public evidence record |
| NUCLEO-N657X0-Q | Staged host-module installation |
| DWM3001-CDK | Staged UWB-module installation |
| XIAO ESP32-C6 | Staged optional-networking module installation |
| Appropriate headers/socketing hardware | Non-destructive, reversible module fitting |

## 5. Stop conditions

Bring-up must stop immediately where any of the following occurs:

- visible solder bridge, damaged pad, displaced copper or suspect connector orientation;
- continuity between a supply rail and `GND` inconsistent with expected passive loading;
- unexpected continuity between `5V_GATEWAY` and `3V3_GATEWAY`;
- unexpected continuity to the XIAO `3V3` pin;
- unexpected power rail voltage;
- abnormal current draw, heat, smell, smoke or LED behaviour;
- module orientation uncertainty; or
- a measured pin mapping inconsistent with the intended interface table.

No firmware activity should be used to rationalise an unresolved hardware failure.

## 6. Gate G0: Documentation and arrival record

### Objective

Establish the received hardware identity before any assembly or test.

### Record

| Item | Result / reference | Status |
|---|---|---|
| Supplier / order reference |  | Pending |
| PCB arrival date |  | Pending |
| Quantity received |  | Pending |
| Board identifier visible on silkscreen |  | Pending |
| Intended release relationship | Gateway rev 0.1; ordered fabrication build may be marked `rev 0.1f` | Prepared |
| Photographs taken: front and back |  | Pending |
| Packaging / visible damage checked |  | Pending |

### Acceptance criterion

Bare PCB is received without obvious physical damage, and its visible identity is documented.

## 7. Gate G1: Bare-board visual inspection

Inspect the PCB before soldering headers, fitting passives or mounting any commercial modules.

| Inspection point | Expected condition | Observation | Pass / fail |
|---|---|---|---|
| Board outline and rounded corners | Clean, complete routed outline |  |  |
| Mounting holes `H1`–`H4` | Correct position and clean drilling |  |  |
| NUCLEO footprint orientation | `CN3` left and `CN15` right in intended top/component view |  |  |
| DWM3001-CDK footprint orientation | Pad labels and module orientation correspond to source |  |  |
| XIAO footprint orientation | Pin 14/VBUS, pin 13/GND, pin 12/3V3 position understood |  |  |
| Test points `TP1`–`TP13` | Present, legible and accessible |  |  |
| Passive footprints | Values/reference text and orientation intelligible |  |  |
| Solder mask openings | No obvious missing or merged openings |  |  |
| Silkscreen | Legible and does not obscure critical pads |  |  |
| Copper/fabrication defects | No visible bridging, scratches or damaged pads |  |  |

### Evidence

Place photographs under:

```text
images/bring-up/G0-G1-arrival-and-visual-inspection/
```

## 8. Gate G2: Bare-board continuity and resistance checks

All tests in this gate are carried out with **no NUCLEO, no DWM3001-CDK and no XIAO fitted**.

### 8.1 Ground continuity

Confirm continuity among all intended ground points.

| From | To | Expected result | Measured result | Pass / fail |
|---|---|---|---|---|
| NUCLEO `CN3.8` | Gateway `GND` test point | Continuity |  |  |
| NUCLEO `CN3.19` | Gateway `GND` test point | Continuity |  |  |
| NUCLEO `CN3.20` | Gateway `GND` test point | Continuity |  |  |
| NUCLEO `CN3.22` | Gateway `GND` test point | Continuity |  |  |
| NUCLEO `CN15.9` | Gateway `GND` test point | Continuity |  |  |
| NUCLEO `CN15.20` | Gateway `GND` test point | Continuity |  |  |
| DWM3001-CDK GND pads | Gateway `GND` test point | Continuity |  |  |
| XIAO pin 13 / `GND` | Gateway `GND` test point | Continuity |  |  |
| Ground terminals of `C1`–`C5` | Gateway `GND` test point | Continuity |  |  |

### 8.2 No-short checks

| From | To | Expected result | Measured result | Pass / fail |
|---|---|---|---|---|
| `5V_GATEWAY` | `GND` | No low-resistance short |  |  |
| `3V3_GATEWAY` | `GND` | No low-resistance short |  |  |
| `5V_GATEWAY` | `3V3_GATEWAY` | No continuity |  |  |
| XIAO pin 12 / `3V3` | `5V_GATEWAY` | No continuity |  |  |
| XIAO pin 12 / `3V3` | `3V3_GATEWAY` | No continuity |  |  |
| SPI/control route | Adjacent unrelated pins | No continuity |  |  |

### 8.3 Resistance record

| Measurement | Expected interpretation | Measured resistance | Status |
|---|---|---|---|
| `5V_GATEWAY` to `GND` | Not a hard short; value recorded as baseline |  | Pending |
| `3V3_GATEWAY` to `GND` | Not a hard short; value recorded as baseline |  | Pending |
| `5V_GATEWAY` to `3V3_GATEWAY` | Not a hard short |  | Pending |
| `DWM_CS` to `3V3_GATEWAY` | Approximately fitted pull-up path, expected around 10 kΩ |  | Pending |
| `C6_CS` to `3V3_GATEWAY` | Approximately fitted pull-up path, expected around 10 kΩ |  | Pending |

### Acceptance criterion

All intended ground continuity checks pass; no supply short or unexpected XIAO power connection is found; pull-up paths show plausible resistance.

## 9. Gate G3: Critical signal-route continuity

With the PCB still unpowered and modules absent, confirm the host-interface nets.

### 9.1 DWM route

| Gateway signal | From NUCLEO pad | To DWM pad | Measured result | Pass / fail |
|---|---|---|---|---|
| `SPI5_SCK` | `CN15.11` | `J10.23` |  |  |
| `SPI5_MISO` | `CN15.13` | `J10.21` |  |  |
| `SPI5_MOSI` | `CN15.15` | `J10.19` |  |  |
| `DWM_CS` | `CN15.17` | `J10.24` |  |  |
| `DWM_IRQ` | `CN15.16` | `J10.15` |  |  |
| `DWM_RESET` | `CN15.33` | `J10.12` |  |  |

### 9.2 XIAO route

| Gateway signal | From NUCLEO pad | To XIAO pad | Measured result | Pass / fail |
|---|---|---|---|---|
| `SPI5_SCK` | `CN15.11` | pin 9 / `D8` |  |  |
| `SPI5_MISO` | `CN15.13` | pin 10 / `D9` |  |  |
| `SPI5_MOSI` | `CN15.15` | pin 11 / `D10` |  |  |
| `C6_CS` | `CN15.19` | pin 4 / `D3` |  |  |
| `C6_INT` | `CN15.5` | pin 3 / `D2` |  |  |
| NC check | N/A | XIAO pin 6 | No connection |  |

### Acceptance criterion

Each critical route corresponds to its intended pad mapping, with no observed cross-connection to adjacent pins.

## 10. Gate G4: Passive population and post-solder inspection

Populate only the carrier-board passives and headers required for staged testing, retaining the option not to fit downstream modules until power has been checked.

| Component group | Action | Evidence / result | Status |
|---|---|---|---|
| `R1`, `R2` pull-ups | Fit and inspect values/orientation |  | Pending |
| `C1`, `C3` 100 nF | Fit and inspect |  | Pending |
| `C2`, `C4` 10 µF | Fit with polarity check if relevant |  | Pending |
| `C5` 22 µF | Fit with polarity check if relevant |  | Pending |
| Headers/socketing | Fit for NUCLEO/DWM/XIAO only where orientation is confirmed |  | Pending |
| Solder joints | Magnified visual inspection |  | Pending |
| Repeat no-short checks | Re-run supply-to-ground tests after soldering |  | Pending |

### Acceptance criterion

Assembly is visually sound, and passive/header population has not created unintended rail shorts.

## 11. Gate G5: NUCLEO-only power validation

Fit the Gateway PCB to the NUCLEO only. **Do not fit the DWM3001-CDK or XIAO during the first powered test.**

Power the NUCLEO using its intended supported power method. Record the exact source and any jumper/configuration setting relevant to that power method.

| Measurement | Test point / location | Expected result | Measured result | Pass / fail |
|---|---|---|---|---|
| `5V_GATEWAY` | Gateway test point / distribution pad | Near 5 V |  |  |
| `3V3_GATEWAY` | Gateway test point / pull-up rail | Near 3.3 V |  |  |
| `GND` reference | Gateway ground point | Stable common reference |  |  |
| `DWM_CS` idle | DWM chip-select test point | High through pull-up |  |  |
| `C6_CS` idle | C6 chip-select test point | High through pull-up |  |  |
| DWM 5 V pad position | CDK `J10.2`/designated supply pad | Near 5 V |  |  |
| XIAO `5V/VBUS` pad | XIAO power pad | Near 5 V |  |  |
| XIAO `3V3` pin | XIAO pin 12 | No carrier-driven voltage |  |  |
| Thermal/visual observation | Whole assembly | No abnormal heating or behaviour |  |  |

### Acceptance criterion

Both Gateway rails and idle chip-select paths are correct, the XIAO power boundary is preserved, and no abnormal behaviour is observed.

## 12. Gate G6: XIAO-only module validation

Only after Gate G5 passes, fit the XIAO ESP32-C6 while leaving the DWM3001-CDK absent.

| Check | Expected result | Measured result | Pass / fail |
|---|---|---|---|
| XIAO `5V/VBUS` power | Correct 5 V input route |  |  |
| XIAO `GND` | Common with Gateway ground |  |  |
| XIAO `3V3` boundary | Not externally driven by carrier |  |  |
| `C6_CS` idle | High / sane default before active communication |  |  |
| `C6_INT` state | Sane level according to firmware/configuration |  |  |
| Thermal observation | No abnormal heating |  |  |
| Basic firmware presence, if exercised | XIAO responds through its supported development route |  |  |

### Acceptance criterion

The optional onward-networking module can be powered safely without disturbing the carrier-board rail assumptions.

## 13. Gate G7: DWM3001-CDK-only module validation

After Gate G5 passes, the DWM3001-CDK may be fitted and tested either with the XIAO absent or with the previously validated XIAO installation retained and clearly recorded.

| Check | Expected result | Measured result | Pass / fail |
|---|---|---|---|
| CDK supply pad | Intended 5 V power path present |  |  |
| CDK ground pads | Common with Gateway `GND` |  |  |
| `DWM_CS` idle | High / sane inactive level |  |  |
| `DWM_RESET` state | Not unintentionally held in reset |  |  |
| `DWM_IRQ` electrical condition | Not shorted to rail or ground |  |  |
| Module LED / power behaviour | Consistent with documented CDK operation |  |  |
| Thermal/current observation | No abnormal current or heating |  |  |

### Acceptance criterion

The Gateway powers the DWM3001-CDK safely and exposes its control-route signals without obvious electrical failure.

## 14. Gate G8: GPIO and low-speed SPI observability

Only after all preceding physical and power checks pass should the NUCLEO exercise control lines.

### Test order

1. Configure `DWM_CS` and `C6_CS` as host-controlled outputs.
2. Confirm both lines idle inactive/high.
3. Toggle each chip-select independently at a slow rate and observe at test points.
4. Exercise `DWM_RESET` under controlled conditions only after its polarity and normal idle state are confirmed.
5. Initialise SPI5 at a conservative low frequency.
6. Observe `SPI5_SCK` and `SPI5_MOSI` with only one subordinate device selected at a time.
7. Record any response on `SPI5_MISO`.
8. Confirm that deselected devices remain electrically inactive on the shared bus.

| Test | Instrument evidence | Result | Status |
|---|---|---|---|
| `DWM_CS` toggle | Scope / logic-analyser capture |  | Pending |
| `C6_CS` toggle | Scope / logic-analyser capture |  | Pending |
| SPI5 clock activity | Scope / logic-analyser capture |  | Pending |
| DWM selected transaction attempt | Capture and firmware log |  | Pending |
| XIAO selected transaction attempt | Capture and firmware log |  | Pending |
| Non-selected bus behaviour | Capture / observation |  | Pending |

### Acceptance criterion

Carrier-board control and SPI signals are observable at their intended pads and do not reveal a physical bus-routing failure.

## 15. Gate G9: Synthetic buffer host-interface milestone

### Objective

Demonstrate the first meaningful Gateway data-path milestone without yet depending on a live Thin-Pod UWB transmission:

> A known synthetic payload associated with the DWM-side communications route is delivered into NUCLEO-accessible memory, checked for integrity and logged reproducibly.

### Important architectural constraint

The DWM3001-CDK/DWM3001C subsystem is not to be treated as raw DW3110 radio silicon under direct NUCLEO control. The intended modular path is that the Qorvo subsystem manages its local UWB function and exposes a higher-level host route or firmware-defined interface. The physical SPI route on rev 0.1 must be evaluated in that context.

### Initial synthetic record

Use a deterministic test message such as:

```text
message_type:       SYNTHETIC_WINDOW
protocol_version:   0x0001
source_id:          DWM_GATEWAY_TEST
sequence_number:    1
sample_rate_hz:     25600
sample_count:       256
sample_format:      int16_le
payload_pattern:    incrementing ramp or known sinusoid table
payload_crc32:      calculated integrity value
```

The chosen sample rate and count are provisional test values for interface development, not a final Thin-Pod transport specification.

### Evidence table

| Evidence item | Required record | Result / file reference |
|---|---|---|
| Synthetic payload source | Exact bytes or generating script |  |
| NUCLEO received buffer | Memory dump or serial log |  |
| Integrity comparison | CRC/checksum and byte count |  |
| Repeatability | At least three repeated successful transfers |  |
| Bus capture | Optional logic-analyser screenshot |  |
| Firmware versions | Commit/hash or build identifier |  |

### Acceptance criterion

A known buffer appears in NUCLEO-accessible memory without corruption, with a repeatable integrity check and documented firmware/toolchain state.

## 16. Gate G10: First UWB-received payload milestone

### Objective

Replace the synthetic test record with a payload actually received over the intended UWB subsystem path.

The first payload need not be a full calibrated vibration measurement. It must be a known, framed transmitted payload that passes through the UWB reception route and is made available to NUCLEO memory.

| Evidence item | Required record | Result / file reference |
|---|---|---|
| Transmitting endpoint | Hardware and firmware identity |  |
| Received payload format | Protocol version and framing |  |
| Packet/window count | Sent versus received counts |  |
| Integrity checks | CRC/error counters |  |
| NUCLEO buffer evidence | Memory/log capture |  |
| Failure cases | Dropped/corrupt packet observations |  |

### Acceptance criterion

A framed UWB-received record is delivered into Gateway-host memory and its integrity/result is recorded.

## 17. Gate G11: Initial analytic-supervisor proof

Only after a received window exists in NUCLEO-accessible memory should the first DSP calculation be performed.

| Processing result | Purpose | Status |
|---|---|---|
| RMS | Basic signal-energy measure | Pending |
| Peak / peak-to-peak | Basic amplitude sanity check | Pending |
| Crest factor | Initial impulsive-content measure | Pending |
| Kurtosis | Initial transient/fault-sensitive statistic | Pending |
| Band-energy placeholder | Confirms FFT/filter feature route when sample-rate/window is fixed | Pending |
| Metadata/error record | Preserves traceability of processing state | Pending |

TinyML remains outside the rev 0.1 Gateway bring-up milestone. The first requirement is a trusted data path and conventional DSP baseline.

## 18. Bring-up summary record

Complete after each work session.

| Date | Gates attempted | Gates passed | Faults discovered | Corrections made | Evidence committed |
|---|---|---|---|---|---|
|  |  |  |  |  |  |

## 19. OSHWA release decision after bring-up

After hardware bring-up:

| Outcome | Appropriate action |
|---|---|
| Ordered fabrication build passes without design changes | Freeze source/BOM/Gerbers as Gateway rev 0.1 candidate release; prepare separate OSHWA application |
| Minor documentation-only corrections required | Update public record transparently; design may remain rev 0.1 |
| Electrical or layout correction required before first certification submission | Incorporate the correction into the first clean Gateway rev 0.1 release, document prototype history and regenerate outputs before submission |
| Post-certification design change required | Assign a later Gateway revision; do not silently replace a certified release |

## References

- Project record: `76 Engineering Log.md`, Gateway fabrication order and initial bring-up checklist.
- STMicroelectronics, `NUCLEO-N657X0-Q` product page and documentation: <https://www.st.com/en/evaluation-tools/nucleo-n657x0-q.html>
- Qorvo, `DWM3001CDK` product page and product brief: <https://www.qorvo.com/products/p/DWM3001CDK>
- Seeed Studio, `XIAO ESP32C6` getting-started guide and pin map: <https://wiki.seeedstudio.com/xiao_esp32c6_getting_started/>
- OSHWA Certification Documentation Guidance: <https://certification.oshwa.org/process/documentation.html>

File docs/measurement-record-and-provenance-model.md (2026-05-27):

# Thin-Pod System: Measurement Record and Provenance Model

**Document identifier:** `TP-SYS-PROV-0001`  
**Document revision:** Draft A  
**Applies to:** Thin-Pod rev 0.1 node, Thin-Pod Gateway rev 0.1 and later processing experiments  
**Document status:** Data-governance and measurement-traceability design specification  
**Document date:** 27 May 2026  
**Certification boundary:** This document supports system development and later Gateway documentation. It does not expand the submitted OSHWA scope of Thin-Pod rev 0.1.

## 1. Purpose

This document defines how a Thin-Pod vibration measurement should remain traceable from physical sensing through acquisition, wireless transport, Gateway receipt, DSP processing and later TinyML inference.

The project’s value is not merely that a vibration record can be transmitted. It is that an eventual result can be examined in context:

```text
What was sensed?
How was it sampled?
How was it transported?
Was the raw record valid and preserved?
What processing was applied?
Which hardware, firmware and model versions produced the result?
```

A derived feature or inference without a preserved provenance chain is not sufficient evidence for a measurement-integrity platform.

## 2. Core principles

1. Raw measurement windows are primary evidence; derived features and classifications are secondary records.
2. A valid raw window is immutable once accepted into Gateway ownership.
3. Every derived result refers back to the exact raw record from which it was calculated.
4. Transport integrity is recorded separately from measurement calibration and analytic interpretation.
5. A CRC detects accidental corruption but is not proof of authenticity.
6. Cryptographic hashes should identify preserved/exported artifacts; later signatures/authentication may protect trust boundaries.
7. Missing, rejected or dropped records are themselves part of the evidential record.
8. Hardware certification scope and system-data provenance are related but not identical: OSHWA publication of hardware does not by itself prove a validated measurement or model.

## 3. Provenance layers

A complete traceability chain contains six layers.

| Layer | Record type | Question answered |
|---|---|---|
| Physical hardware | Device/build manifest | Which node, sensor, Gateway and modules were involved? |
| Acquisition | Acquisition configuration and raw-window header | How was the signal sampled? |
| Transport | Window transport event record | How did the record move and was integrity preserved? |
| Ingestion | Gateway ownership/validation record | When did NUCLEO accept the raw record? |
| Processing | DSP result record | Which transformations generated derived features? |
| Inference/reporting | Model/result/report record | Which model or outward message used which input evidence? |

## 4. Identifier scheme

Identifiers should be stable, human-readable where useful and unambiguous in data files.
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

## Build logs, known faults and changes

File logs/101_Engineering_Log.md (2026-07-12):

# 101 Engineering Log: Matched DW3110 One-Way RF Exchange

**Date:** 12 July 2026
**Repository:** `Pealie/Thin-Pod-Gateway-rev-0.1`
**Source branch:** `gateway-dw3110-rf-exchange`
**Merged pull request:** `#7 Validate matched DW3110 one-way Gateway-to-Node RF exchange`
**Merge commit:** `dbe355b80a2afed867bcaa09a2f3f1b23abea8e5`
**Scope:** Physical one-way UWB frame transmission from the Gateway-side DWM3001-CDK to the Node-side DWM3001-CDK, matched sequence validation, raw RTT evidence preservation, build provenance and merge into `main`

## Summary

This milestone established a real one-way UWB RF exchange between the two Thin-Pod DWM3001-CDK boards.

The Gateway-side board configured its internal DW3110 as the transmitter. The Node-side board configured its internal DW3110 as the receiver. Both applications ran under Zephyr using Nordic nRF Connect SDK v3.3.1 and the external Qorvo `DW3\_QM33\_SDK\_1.1.0` driver.

The proof used deterministic 24-byte application payloads with a DW3110-generated two-byte frame check sequence. Each record included role, sequence number, source and destination identifiers, payload length, uptime marker and checksum. The Gateway transmitted repeated 20-frame suites at 500 ms intervals. The Node validated frame length, addressing, payload content, checksum and sequence progression.

The decisive evidence is a matched transmitter and receiver sequence window:

```text
first\_seq=41
last\_seq=60
frames=20
```

Gateway result:

```text
TPRF\_TX\_SUMMARY role=gateway suite=3 attempted=20 pass=20 fail=0 first\_seq=41 last\_seq=60 result=PASS
```

Node result:

```text
TPRF\_RX\_SUMMARY role=node suite=3 valid=20 invalid=0 timeouts=0 errors=0 gaps=0 duplicates=0 first\_seq=41 last\_seq=60 result=PASS
```

The same twenty sequence numbers were therefore transmitted by the Gateway-side DW3110 and received and validated by the Node-side DW3110.

## Relationship to Engineering Log 100

Engineering Log 100 established physical SPI communication, DW3110 identity, IDLE\_RC entry and successful initialisation on both boards.

Engineering Log 101 closes the next stated firmware gate:

```text
one-way UWB frame transmission and reception
```

The evidence chain has progressed from physical device access to an actual over-the-air exchange with correlated transmitter and receiver records.

## Firmware and build progression

The RF work was preserved through three main commits:

```text
5a14e3f25226f8d49e7431ec8381c82bf5c8476b
Implement DW3110 one-way RF frame proof

5736322d3e6d319d7b9ce3f43bd5f23695cbf047
Adapt RF proof to QM33 DW3 driver APIs

700e7f5c2ced13e50d46b8f2c1f48415d70fc6dd
Record matched DW3110 one-way RF exchange
```

The implementation introduced:

```text
firmware/common/qorvo\_dw3000/include/thinpod\_dw3000\_rf\_proof.h
firmware/common/qorvo\_dw3000/src/thinpod\_dw3000\_rf\_proof.c
firmware/gateway/uwb\_initiator\_stage2\_rf/
firmware/node/uwb\_responder\_stage2\_rf/
scripts/check\_dw3110\_rf\_exchange.py
docs/firmware/DW3110\_One\_Way\_RF\_Exchange\_Procedure.md
docs/firmware/UWB\_RF\_Proof\_Stage2.md
```

The first build exposed legacy Qorvo API names that were absent from the QM33 SDK. The RF proof was adapted to the supported APIs:

```text
dwt\_readsysstatuslo()
dwt\_writesysstatuslo()
dwt\_getframelength()
```

The receiver recovery path retained `dwt\_forcetrxoff()` and removed the unavailable legacy `dwt\_rxreset()` call.

Both applications then built successfully.

Node receiver build:

```text
FLASH: 54,624 bytes of 512 KB, 10.42%
RAM:    9,280 bytes of 128 KB, 7.08%
Result: PASS
```

Gateway transmitter build:

```text
FLASH: 53,672 bytes of 512 KB, 10.24%
RAM:    9,280 bytes of 128 KB, 7.08%
Result: PASS
```

## Physical test configuration

The physical proof used two distinct DWM3001-CDK boards:

```text
Gateway transmitter J-Link serial: 760203854
Node receiver J-Link serial:       760222856
```

RF configuration:

```text
Channel:             5
Preamble length:     128
PAC:                 8
TX preamble code:    9
RX preamble code:    9
SFD:                 DWT\_SFD\_DW\_8
Data rate:           6.8 Mbps
PHR mode:            standard
STS:                 disabled
PDOA:                disabled
Application payload: 24 bytes
Air frame length:    26 bytes including hardware FCS
Frame interval:      500 ms
Suite length:        20 frames
```

The Node receiver was started first and placed into repeated bounded receive windows. The Gateway transmitter was then flashed, logged and reset while both SEGGER RTT loggers were active.

## Evidence package

The validation report was generated at:

```text
docs/validation/DW3110\_One\_Way\_RF\_Exchange\_Validation.md
```

Raw evidence was stored under:

```text
logs/validation/dw3110-one-way-rf/
```

The evidence package contains:

```text
build-artifact-sha256.txt
gateway-dwm3001cdk-rf-rtt.log
node-dwm3001cdk-rf-rtt.log
source-state.txt
```

Raw RTT hashes:

```text
SHA256  E785C5474F3F6E4E11F51E46A6EC7C98B5CDBE5A2875A65E7A3051CCEF8117ED  gateway-dwm3001cdk-rf-rtt.log
SHA256  2C4570004CE481DEEE3967B7AD15DEDAE000203CD99C241BA22D5EAF33A8EFAC  node-dwm3001cdk-rf-rtt.log
```

Build artefact hashes:

```text
SHA256  06581830CA9AB1E0ADB8729C6B8848AFF47EBEB89EEAE269FE2414B7D598B2F4  node zephyr.elf
SHA256  9C6189A03506A3548DF68A358C183F818E155004FA028D88A57776FFCD7BF57A  node merged.hex
SHA256  2EE1AAB862E1AC207826B69A7CB770D44B21BABE2F38E8843CC21C44A14F9866  gateway zephyr.elf
SHA256  A6316CE6B9A4590B1B5742468931F0C67DBAD72AD9A8F745EF0557C11E2B395A  gateway merged.hex
```

## Automated evidence validation

The evidence checker was strengthened to require a passing Gateway summary and a passing Node summary with identical `first\_seq` and `last\_seq` values.

Final checker output:

```text
gateway\_summary=TPRF\_TX\_SUMMARY role=gateway suite=3 attempted=20 pass=20 fail=0 first\_seq=41 last\_seq=60 result=PASS
node\_summary=TPRF\_RX\_SUMMARY role=node suite=3 valid=20 invalid=0 timeouts=0 errors=0 gaps=0 duplicates=0 first\_seq=41 last\_seq=60 result=PASS
matched\_sequence\_window=first\_seq=41 last\_seq=60
result=PASS
```

The complete captures contained:

```text
Gateway TX PASS records: 535
Gateway TX FAIL records:   0
Node RX PASS records:     580
Node RX FAIL records:       2
```

The two Node failures occurred outside the selected matched suite.

The first was a valid frame with a restarted sequence number and `sequence\_valid=0`. The second was a single receiver error without a payload. Both records remain preserved in the raw evidence. The selected sequence window 41-60 contains a clean twenty-frame exchange with zero invalid frames, timeouts, receiver errors, sequence gaps or duplicates.

## Validated claim

The evidence supports the following claim:

```text
The Thin-Pod Gateway-side DWM3001-CDK transmitted deterministic UWB frames through its internal DW3110, and the Node-side DWM3001-CDK received the same matched sequence window through its internal DW3110, verified the exact frame length, addressing, payload, checksum and sequence progression, and completed a repeatable 20-frame one-way RF exchange.
```

## Evidence boundary

The present evidence establishes:

* Gateway-to-Node one-way UWB frame transport;
* successful physical transmission and reception through two internal DW3110 devices;
* deterministic payload integrity;
* checksum agreement;
* sequence-window correlation;
* repeatable twenty-frame suites;
* polled DW3110 status handling;
* raw-log and build-artifact provenance.

The following remain future work:

* Node-to-Gateway one-way exchange in the intended sensor-to-Gateway direction;
* bidirectional exchange;
* ranging;
* vibration-window transport;
* Thin-Pod telemetry transport;
* IRQ-driven receive handling;
* RF range and link-budget validation;
* production transmit-power calibration;
* antenna and coexistence performance;
* security properties;
* regulatory compliance.

## Repository integration

The feature branch was pushed as:

```text
gateway-dw3110-rf-exchange
```

Pull request:

```text
#7 Validate matched DW3110 one-way Gateway-to-Node RF exchange
```

The pull request contained ten commits, passed the repository check and reported no conflict with `main`.

It was merged into `main` as:

```text
dbe355b80a2afed867bcaa09a2f3f1b23abea8e5
```

This places the physical RF implementation, validation report, raw evidence, artefact hashes and automated matched-suite checker in the main Gateway repository history.

## Engineering significance

The Gateway work has advanced from board-level bring-up and transceiver initialisation to a measured radio link between two physical Thin-Pod UWB subsystems.

The milestone demonstrates that the Zephyr platform layer, external Qorvo driver integration, deterministic frame format, transmitter path, receiver path and evidence workflow operate together successfully.

The result also confirms the value of the current evidence discipline:

1. define the smallest defensible claim;
2. build both roles reproducibly;
3. test on physical hardware;
4. retain raw output;
5. hash source-linked artefacts;
6. automate the acceptance criteria;
7. preserve anomalous records;
8. merge only after a matched result is established.

## Next concrete milestone

The next justified RF gate is:

```text
Node-to-Gateway one-way UWB frame transmission and reception
```

That milestone should reuse the existing PHY configuration, deterministic payload format, matched-sequence checker and evidence package structure while reversing the radio roles.

Once the intended Node-to-Gateway direction is established, the following gate can introduce a bounded Thin-Pod telemetry or vibration-window payload.

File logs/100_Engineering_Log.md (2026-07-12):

# 100 Engineering Log: DW3110 Physical Identity and Initialisation Proof

**Date:** 12 July 2026  
**Repository:** `Pealie/Thin-Pod-Gateway-rev-0.1`  
**Branch:** `gateway-dw3110-rf-exchange`  
**Final branch commit:** `6988263aef77a63e214045627d8691e1f9ca2777`  
**Scope:** External Qorvo DW3000/DW3110 driver integration, reproducible Gateway and Node builds, physical SPI identity proof, DW3110 initialisation, raw RTT evidence capture and repository evidence preservation

## Summary

This work established the first complete physical communication proof between the nRF52833 and the internal DW3110 transceiver on both Thin-Pod DWM3001-CDK boards.

The milestone progressed through a controlled sequence:

1. integrate the Qorvo DW3000/DW3110 driver as an external SDK dependency;
2. build the Gateway-side and Node-side Stage-2 applications;
3. implement a bounded identity and initialisation proof;
4. flash and test each DWM3001-CDK independently;
5. capture repeatable RTT evidence;
6. record firmware and log hashes;
7. preserve the original evidence bytes in Git;
8. leave the branch clean, pushed and ready for the next RF milestone.

Both boards successfully prepared their Zephyr SPI3 and GPIO interfaces, asserted and released the DW3110 reset line, completed `dwt\_probe()`, reached IDLE\_RC, completed `dwt\_initialise(DWT\_READ\_OTP\_ALL)`, and returned stable device identifiers at both 2 MHz and 8 MHz SPI rates.

The Gateway-side and Node-side boards also returned distinct OTP part identifiers, confirming that the validation covered two separate physical DW3110 transceivers.

The milestone demonstrates physical SPI communication and successful DW3110 initialisation. It does not yet demonstrate UWB transmission, reception, ranging or telemetry transport.

## Repository progression

The work was developed on:

```text
gateway-dw3110-rf-exchange
```

The main commits in the milestone sequence were:

```text
f16f693 Add external Qorvo DW3000 build integration
73e3668 Document Qorvo DW3000 build integration
368c570 Implement DW3110 identity and initialisation proof
d87dcfd Record DW3110 physical identity and initialisation proof
a1e14e6 Preserve raw DW3110 RTT evidence bytes
6988263 Store exact raw DW3110 RTT evidence
```

The branch finished at:

```text
6988263aef77a63e214045627d8691e1f9ca2777
```

Final Git state:

```text
On branch gateway-dw3110-rf-exchange
Your branch is up to date with 'origin/gateway-dw3110-rf-exchange'.

nothing to commit, working tree clean
```

## External Qorvo driver integration

The Qorvo DW3000/DW3110 source remained outside the Git repository and was selected through:

```text
QORVO\_DW3\_SDK\_ROOT
```

The validated local SDK location was:

```text
C:\\Qorvo\\DW3\_QM33\_SDK\_1.1.0
```

The integration compiled the required Qorvo sources together with the Thin-Pod Zephyr platform adapter while maintaining a clear boundary between Thin-Pod-owned source and Qorvo-owned SDK material.

The common integration included:

```text
firmware/common/qorvo\_dw3000/
```

with platform support for:

* SPI transactions;
* slow and fast SPI rates;
* DW3110 reset control;
* IRQ sampling;
* delays and critical sections;
* Qorvo probe-interface callbacks;
* physical identity and initialisation reporting.

Both Gateway-side and Node-side applications built successfully with the external driver.

## Build results

The Gateway identity and initialisation build completed successfully:

```text
FLASH: 51,808 bytes of 512 KB, 9.88%
RAM:    9,280 bytes of 128 KB, 7.08%
Result: PASS
```

The Node application also completed successfully.

The generated ELF and merged HEX artefacts were recorded with SHA-256 hashes:

```text
SHA256  872BC431F2DFEADC609F4A04C8B79BDB9E0CDEE7CB894D80CA70DA46689A33D4  gateway zephyr.elf
SHA256  9FAEA9B8698F03D92BA6E776B13F57D17E3CEC113D27B089387ED3E14A1FE7D1  gateway merged.hex
SHA256  C26C4C893B4666C77B1A323640252779D684D9C0F59BE595A42881D1F56CBBC1  node zephyr.elf
SHA256  7F419321B029CBCC661A48E9DEFA453A8BAF19EDDBF259237466774E7FEA5F3C  node merged.hex
```

## Physical proof sequence

The identity proof used a deliberately bounded sequence:

1. prepare Zephyr SPI3 and GPIO devices;
2. select the 2 MHz SPI rate;
3. assert DW3110 RESET low;
4. release RESET and allow the transceiver to settle;
5. sample the IRQ line;
6. call `dwt\_probe()`;
7. read and validate the device identifier;
8. wait for IDLE\_RC with a finite timeout;
9. call `dwt\_initialise(DWT\_READ\_OTP\_ALL)`;
10. read the post-initialisation device identifier;
11. capture part ID, lot ID, OTP revision and reference values;
12. select the 8 MHz SPI rate;
13. repeat the device-ID read;
14. verify device-ID stability;
15. emit structured RTT result lines.

The proof intentionally excluded RF configuration, transmission and reception.

## Gateway-side physical result

The Gateway-side DWM3001-CDK reported:

```text
TPDW\_RESULT role=gateway role\_id=0x0000 result=PASS failure\_stage=none final\_rc=0 platform\_rc=0 reset\_rc=0 probe\_rc=0 idlerc=1 init\_rc=0 devid\_match=1 post\_match=1 fast\_match=1 stable=1
```

Device evidence:

```text
expected=0xdeca0312
mask=0xffffff0f
devid\_slow=0xdeca0302
devid\_after\_init=0xdeca0302
devid\_fast=0xdeca0302
```

OTP evidence:

```text
part\_id=0x0f34872a
lot\_hi=0x00005056
lot\_lo=0x36583637
otp\_revision=1
ref\_voltage=119
ref\_temperature=124
```

IRQ observation:

```text
before=1
after=1
```

Result:

```text
PASS
```

## Node-side physical result

The Node-side DWM3001-CDK reported:

```text
TPDW\_RESULT role=node role\_id=0x0001 result=PASS failure\_stage=none final\_rc=0 platform\_rc=0 reset\_rc=0 probe\_rc=0 idlerc=1 init\_rc=0 devid\_match=1 post\_match=1 fast\_match=1 stable=1
```

Device evidence:

```text
expected=0xdeca0312
mask=0xffffff0f
devid\_slow=0xdeca0302
devid\_after\_init=0xdeca0302
devid\_fast=0xdeca0302
```

OTP evidence:

```text
part\_id=0x8ec49c9a
lot\_hi=0x00005056
lot\_lo=0x34583230
otp\_revision=1
ref\_voltage=118
ref\_temperature=126
```

IRQ observation:

```text
before=1
after=1
```

Result:

```text
PASS
```

## Device distinction

The two boards returned different OTP part IDs:

```text
Gateway: 0x0f34872a
Node:    0x8ec49c9a
```

This provides evidence that two distinct physical DW3110 devices were independently flashed, probed and initialised.

## Evidence package

The durable physical-validation record was added at:

```text
docs/validation/DW3110\_Physical\_Identity\_Initialisation\_Validation.md
```

The external integration document was updated at:

```text
docs/firmware/Qorvo\_DW3000\_External\_SDK\_Integration.md
```

The raw validation evidence was stored under:

```text
logs/validation/dw3110-identity-init/
```

The evidence set contains:

```text
build-artifact-sha256.txt
gateway-dwm3001cdk-rtt.log
node-dwm3001cdk-rtt.log
```

Recorded RTT SHA-256 hashes:

```text
SHA256  DA14DCC850B29FFE88ED0CE282CE651F9DB178BF7CC7AFFE446EA073F634BF9E  gateway-dwm3001cdk-rtt.log
SHA256  9AC40F65C265C37CE6FC36067F6D0D118E1ACB244C8DF193C7EC39CF8EF3CB05  node-dwm3001cdk-rtt.log
```

The RTT Viewer files contain legitimate blank records represented as `00> ` and use CRLF line endings. Repository attributes were therefore added to preserve them as raw evidence:

```text
logs/validation/dw3110-identity-init/\*.log -text -diff -whitespace
```

The originally captured CRLF bytes were then written directly into the Git index and committed. This aligned the committed files with the recorded SHA-256 hashes.

## Validated claim

The evidence supports the following claim:

```text
The Thin-Pod Gateway-side and Node-side DWM3001-CDK boards independently established physical SPI communication with their internal DW3110 transceivers, returned Qorvo-driver-matching device identifiers, reached IDLE\_RC and completed DW3110 initialisation successfully.
```

## Remaining boundary

This milestone does not demonstrate:

* UWB RF transmission;
* UWB RF reception;
* a frame exchanged between boards;
* ranging;
* vibration-window transport;
* telemetry transport;
* IRQ-driven receive handling;
* RF performance;
* regulatory compliance.

Both boards reported IRQ high before and after initialisation. IRQ polarity, idle behaviour and event clearing remain subjects for the receive-path milestone.

## Next concrete milestone

The next justified firmware gate is:

```text
one-way UWB frame transmission and reception
```

The intended progression is:

1. configure both DW3110 transceivers with the same bounded PHY settings;
2. place one board in receive mode;
3. transmit a small, deterministic frame from the other board;
4. verify frame length and payload;
5. capture transmit and receive status;
6. record repeatability over multiple exchanges;
7. preserve raw RTT evidence and firmware hashes;
8. defer ranging and vibration-window transport until the basic RF exchange is reliable.

This keeps the Gateway work aligned with the agreed milestone sequence: concrete bring-up evidence first, followed by the smallest defensible RF proof.

##

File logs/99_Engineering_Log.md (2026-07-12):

# 99 Engineering Log

**Date:** 11–12 July 2026
**Repository:** `Pealie/Thin-Pod-Gateway-rev-0.1`
**Branch:** `gateway-dwm-spis-get-capabilities`
**Scope:** Completion of the PoE-powered NUCLEO-to-DWM TPHIP `GET_CAPABILITIES` physical host-interface proof

## Session summary

The Thin-Pod Gateway rev 0.1 NUCLEO-to-DWM host interface has completed its first repeatable bidirectional physical protocol proof.

The investigation began with a deterministic two-transaction phase slip. The DWM3001-CDK received valid 16-byte requests and constructed valid 32-byte responses, although the NUCLEO did not recognise the READY assertion reliably. Each following 16-byte request then clocked only half of the pending response, producing:

```text
response_callback_result=16
response_complete ret=-122
```

The failure was traced through the RESET and READY hardware paths. A marginal solder connection at DWM J10.12 held the DWM RESET net at approximately 2 V under PoE-only power. Reflowing J10.12 restored the released RESET level to approximately 3.3 V.

A temporary static READY-toggle diagnostic then demonstrated valid rail-level signalling at every accessible point on the physical READY route:

```text
DWM J10.15    approximately 0 V / 3.3 V
Gateway TP6   approximately 0 V / 3.3 V
NUCLEO PB9    approximately 0 V / 3.3 V
```

The TPHIP SPIS endpoint was restored and rebuilt with the supported READY readback diagnostic retained. The existing NUCLEO host-interface probe was retained with its complete hexadecimal response dump. The resulting tested source therefore matches the diagnostic behaviour present in the captured validation evidence.

## Hardware configuration

| Item | Test configuration |
|---|---|
| Gateway carrier | Thin-Pod Gateway rev 0.1 physical fabrication build |
| Main host | STM32 NUCLEO-N657X0-Q |
| UWB subsystem | Qorvo DWM3001-CDK |
| Power | PoE splitter into NUCLEO USB-C sink/user connector |
| NUCLEO selector | Pins 3–4, `5V_USB_SNK` |
| DWM power | Gateway carrier 5 V path to DWM J10.2 |
| NUCLEO console | ST-LINK virtual COM port, 115200 8N1 |
| Host bus | SPI5, mode 0, 1 MHz, MSB first |
| Request length | 16 bytes |
| Response length | 32 bytes |

## Corrective action

The DWM J10.12 RESET solder connection was reflowed with flux and minimal fresh solder.

Before corrective action:

```text
DWM J10.12 RESET to TP1: approximately 2.0 V
READY path: approximately 0.5 V to 0.8 V during attempted assertion
```

After corrective action:

```text
DWM J10.12 RESET to TP1: approximately 3.3 V
DWM J10.15 READY:        approximately 0 V / 3.3 V
Gateway TP6 READY:       approximately 0 V / 3.3 V
NUCLEO PB9 READY:        approximately 0 V / 3.3 V
```

The observed change establishes the J10.12 joint as the principal physical cause of the marginal DWM start-up and invalid READY levels.

## Supported diagnostic source retained

Two diagnostic changes are retained as supported behaviour in the rev 0.1 bring-up applications.

### DWM READY output readback

The DWM READY pin remains configured with input sensing enabled while operating as an output. Input sensing is used solely to read back the physical logic level driven by the endpoint for bring-up observability.

The endpoint reports:

```text
tphip_dwm ready_set_ret=<return value> ready_physical=<0 or 1>
```

Protocol flow does not depend on this readback value.

### NUCLEO complete response dump

The NUCLEO host-interface probe retains the complete 32-byte hexadecimal response dump:

```text
response_after_clock=54 50 47 57 ...
```

This output permits direct comparison between captured physical responses and the frozen TPHIP test vectors. The application is a validation probe, so this detailed output forms part of its intended observability.

## TPHIP validation result

Each complete suite contains:

- one local valid-CRC sequence-mismatch parser self-test;
- ten valid `GET_CAPABILITIES` exchanges with sequences 1 through 10;
- one unknown-version test;
- one reserved-flags test;
- one oversized-payload test;
- one bad-CRC test;
- one unknown-opcode test.

The ten valid exchanges returned:

```text
status=OK
crc=OK
protocol=1.0
flags=0x000c
max_payload=64
max_record=0
build_id=0x00010001
guard=OK
result=PASS
```

The adverse requests returned the required statuses:

| Test | Required status | Observed status |
|---|---|---|
| Unknown version | `BAD_VERSION` | `BAD_VERSION` |
| Reserved flags | `BAD_FLAGS` | `BAD_FLAGS` |
| Oversized payload | `BAD_LENGTH` | `BAD_LENGTH` |
| Bad request CRC | `BAD_CRC` | `BAD_CRC` |
| Unknown opcode | `UNKNOWN_OPCODE` | `UNKNOWN_OPCODE` |

Every fully captured suite concluded:

```text
suite=GET_CAPABILITIES passes=16 failures=0 guard=OK result=PASS
```

## Repeatability evidence

Three independent PoE power-cycle procedures were completed.

PuTTY could attach only after the boards were powered. Each power-cycle log therefore begins with repeated:

```text
host_if_probe idle ready=0 suite_result=PASS
```

This records that the power-up suite had completed successfully before console capture began. A manual NUCLEO reset was then applied, and each log captured a second complete suite from boot banner through final PASS.

| Evidence record | Power-up state | Fully captured rerun |
|---|---|---|
| `nucleo_putty_sun2.log` | `suite_result=PASS` visible on attachment | 16 passes, 0 failures |
| `nucleo_putty_sun3.log` | `suite_result=PASS` visible on attachment | 16 passes, 0 failures |
| `nucleo_putty_sun4.log` | `suite_result=PASS` visible on attachment | 16 passes, 0 failures |

An earlier complete passing record is also present in `nucleo_putty_sun1.log`.

The evidence supports three successful PoE power-up executions and three fully captured NUCLEO-reset reruns with identical protocol results.

## Physical path established

The completed proof covers:

```text
NUCLEO SPI5 SCK / COPI / CS
    →
Gateway carrier routing and test access
    →
DWM3001-CDK SPIS request reception
    →
TPHIP request validation and response construction
    →
DWM READY assertion and CIPO response transfer
    →
Gateway carrier READY / CIPO routing
    →
NUCLEO response reception, CRC validation and decoding
```

The following carrier routes are now physically exercised:

| Function | NUCLEO | DWM3001-CDK | Gateway test point |
|---|---|---|---|
| SCK | PE15 | J10.23 / P0.31 | TP10 |
| COPI / MOSI | PG2 | J10.19 / P0.27 | TP11 |
| CIPO / MISO | PG1 | J10.21 / P0.07 | TP12 |
| CS | PA3 | J10.24 / P0.30 | TP7 |
| READY | PB9 | J10.15 / P0.28 | TP6 |
| RESET | PD0 | J10.12 / P0.18 | TP5 |

## Milestone conclusion

The PoE-powered Thin-Pod Gateway has completed three independent power-cycle validations of the NUCLEO-to-DWM TPHIP `GET_CAPABILITIES` interface.

Each validation demonstrated:

- stable DWM RESET release at approximately 3.3 V;
- valid READY low and high rail levels across J10.15, TP6 and PB9;
- ten consecutive valid bidirectional SPI exchanges;
- complete 32-byte CIPO responses;
- request and response CRC validation;
- sequence correlation;
- expected adverse-request handling;
- intact request and response buffer guards;
- zero suite failures.

The NUCLEO host-interface and physical pin-path confirmation milestone is closed.

## Evidence boundary

Established:

- PoE power reaches the NUCLEO and DWM through the intended Gateway arrangement.
- The DWM RESET path releases correctly after J10.12 reflow.
- READY is physically valid from DWM P0.28 through J10.15 and TP6 to NUCLEO PB9.
- The NUCLEO sends valid 16-byte requests over the physical SPI path.
- The DWM validates requests and constructs the expected responses.
- The DWM returns complete 32-byte responses over CIPO.
- The NUCLEO validates magic, version, flags, lengths, opcode, sequence, status and CRC.
- All normal and adverse host-interface tests pass.
- Three PoE power-up executions and three fully captured reruns pass.

Pending:

- real DWM-to-DWM DW3110 UWB RF exchange;
- node-to-Gateway vibration-window transport;
- Gateway buffering, DSP and later TinyML validation;
- any later production security, secure-boot or regulatory claims.

## Next Gateway milestone

The next gated Gateway activity is:

> Real DWM3001-CDK to DWM3001-CDK UWB RF proof using the staged node responder and Gateway initiator roles.

No RF, vibration-transport, DSP, TinyML, production-security or regulatory claim is made from the completed host-interface proof.

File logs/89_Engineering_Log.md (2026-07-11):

# 89 Engineering Log - Gateway Branch Consolidation and NUCLEO Probe Direction

**Date:** 2026-06-30<br>
**Project:** Thin-Pod Gateway rev 0.1<br>
**Repository:** `Thin-Pod-Gateway-rev-0.1`<br>
**Primary branch at end of session:** `gateway-nucleo-spi5-gpio-probe`<br>
**Definitive base branch:** `main`<br>

## Summary

This evening's work clarified the current state of the Thin-Pod Gateway repository, confirmed that the Gateway completion checklist work had already been merged into `main`, and established a clean feature branch for the next code step: implementing the NUCLEO-side SPI5/GPIO probe for the manufactured Gateway PCB.

The session resolved uncertainty around which branch should now be considered definitive. The earlier `gateway-rev0.1-completion-checklist` branch is no longer visible on GitHub because it has been merged into `main` through pull request #2. The local and remote Git history confirmed that the checklist artefacts, CI workflow, validation log, OSHWA preparation checklist, packet definition, parser, and sample telemetry packet are all now present on `main`.

The older `stage2-uwb-rf-proof` branch remains visible, but it is now 21 commits behind `main` and should be treated as historical/stale rather than as the active development branch.

## Branch status confirmed

The branch page showed only:

```text
main
stage2-uwb-rf-proof
```

This initially raised the question of where `gateway-rev0.1-completion-checklist` had gone. Local Git checks confirmed that it had been merged into `main`.

Relevant log entries included:

```text
1f5dbe3 Update engineering log 88 after PR merge
38aacb5 Merge pull request #2 from Pealie/gateway-rev0.1-completion-checklist
768fd7b Reference Gateway hardware images in README
648953e Add engineering log 88 for Gateway weekend work
4a436b2 Add Gateway OSHWA preparation checklist
0c858b6 Add Gateway GitHub Actions artifact check
db3ca99 Add Gateway rev 0.1 validation log
7d78138 Ignore Python cache files
b92eae5 Add Gateway release artifact check script
```

The following command confirmed that the OSHWA preparation checklist commit is now contained by `origin/main`:

```bat
git branch -r --contains 4a436b2
```

Output:

```text
origin/HEAD -> origin/main
origin/main
```

The following command confirmed the expected completion artefacts are present on `origin/main`:

```bat
git ls-tree -r --name-only origin/main | findstr /i "Gateway_OSHWA gateway-checks validation gateway_packet_logger telemetry_packet"
```

Confirmed files:

```text
.github/workflows/gateway-checks.yml
docs/oshwa/Gateway_OSHWA_Preparation_Checklist.md
docs/protocol/ThinPod_Gateway_Telemetry_Packet_v1.md
docs/validation/Gateway_rev0_1_Validation_Log.md
samples/telemetry_packet_v1_sample.hex
scripts/gateway_packet_logger.py
```

## Definitive branch decision

The definitive branch is now:

```text
main
```

The active development branch for the next code task is:

```text
gateway-nucleo-spi5-gpio-probe
```

The historical/stale branch is:

```text
stage2-uwb-rf-proof
```

Current interpretation:

| Branch | Status | Notes |
|---|---|---|
| `main` | Definitive | Contains merged Gateway completion checklist work |
| `gateway-nucleo-spi5-gpio-probe` | Active feature branch | Created from current `main` for the NUCLEO probe implementation |
| `stage2-uwb-rf-proof` | Historical/stale | 21 commits behind `main`; do not continue new work from here |
| `gateway-rev0.1-completion-checklist` | Merged/deleted | Work merged into `main` via PR #2 |

## New feature branch created

A new branch was created from the current `main` to isolate the next code change:

```bat
cd C:\ThinPod\Thin-Pod-Gateway-rev-0.1
git checkout main
git pull
git checkout -b gateway-nucleo-spi5-gpio-probe
git push -u origin gateway-nucleo-spi5-gpio-probe
```

Result:

```text
Switched to a new branch 'gateway-nucleo-spi5-gpio-probe'
branch 'gateway-nucleo-spi5-gpio-probe' set up to track 'origin/gateway-nucleo-spi5-gpio-probe'
```

GitHub confirmed the new branch is visible and current, with checks green.

## Completion evidence baseline carried forward

The current `main` branch now contains the Gateway rev 0.1 evidence framework built during the completion checklist work:

| Item | Status |
|---:|---|
| 1. Stable hardware bring-up note | Present, awaiting final measured values |
| 2. Final verified pin map | Present, awaiting final verification entries |
| 3. Minimal SPI/GPIO probe app | Scaffold present |
| 4. One defined telemetry packet | Present |
| 5. One node-to-Gateway transfer | Still to do |
| 6. One parser or logging script | Present and tested |
| 7. One validation log | Present |
| 8. GitHub Actions/scripted check | Present and passing |
| 9. One tagged Gateway release | Later |
| 10. OSHWA certification preparation | Present |

The local artifact check previously reached:

```text
Passes:   47
Warnings: 0
Failures: 0

Artifact check passed.
```

GitHub Actions was also confirmed green on the current branch baseline.

## Repo image-folder clarification

There was a concern that an `images` folder might have been deleted. Git history checks showed that no tracked `images` folder had been deleted during the completion checklist work.

Earlier checks showed no tracked `images` path in branch history at that point:

```bat
git log --all --name-status -- images
```

Later `main` history showed image work had been added and referenced through commits such as:

```text
b960ddc Add Gateway PCB and node images
768fd7b Reference Gateway hardware images in README
ff56e86 Reference Gateway hardware images in README
```

Conclusion: image handling is now part of `main`; no accidental deletion was identified from the completion checklist work.

## Repo zip review and firmware upload clarification

A review of the repository zip clarified that the repo contains source-level Zephyr application folders rather than ready-made `.hex`, `.bin`, `.uf2`, or `.elf` firmware images.

The practical flashing model is:

```text
source folder -> west build -> generated merged.hex -> west flash
```

### Thin-Pod node CDK

Primary source folder:

```text
firmware/node/uwb_responder/
```

Purpose:

```text
Node-side Stage-1 responder/stub firmware
```

Relevant files:

```text
firmware/node/uwb_responder/CMakeLists.txt
firmware/node/uwb_responder/prj.conf
firmware/node/uwb_responder/src/main.c
firmware/common/thinpod_protocol/thinpod_protocol.c
firmware/common/thinpod_protocol/thinpod_protocol.h
```

### Gateway DWM3001-CDK

Primary source folder:

```text
firmware/gateway/uwb_initiator/
```

Purpose:

```text
Gateway-side Stage-1 initiator/stub firmware
```

Relevant files:

```text
firmware/gateway/uwb_initiator/CMakeLists.txt
firmware/gateway/uwb_initiator/prj.conf
firmware/gateway/uwb_initiator/src/main.c
firmware/common/thinpod_protocol/thinpod_protocol.c
firmware/common/thinpod_protocol/thinpod_protocol.h
```

### Gateway NUCLEO

Current source folder:

```text
firmware/gateway_probe/
```

Current status:

```text
Probe scaffold exists, but it is not yet a full hardware-facing SPI5/GPIO proof app.
```

The repo still needs the next code step to make this NUCLEO-side probe genuinely exercise the manufactured Gateway PCB signal paths.

## Next code step determined

The next code step is:

```text
Upgrade firmware/gateway_probe from a heartbeat scaffold into a real NUCLEO SPI5/GPIO hardware probe.
```

This is the correct next step before attempting real UWB RF transfer, because it proves the Gateway host-side hardware routes first.

The implementation should happen on:

```text
gateway-nucleo-spi5-gpio-probe
```

Target files:

```text
firmware/gateway_probe/boards/nucleo_n657x0_q.overlay
firmware/gateway_probe/src/main.c
firmware/gateway_probe/prj.conf
firmware/gateway_probe/README.md
```

The probe should demonstrate:

- NUCLEO firmware boots;
- SPI5 is enabled on the Gateway PCB route;
- `DWM_RESET` can be toggled;
- `DWM_CS` can be toggled;
- `DWM_IRQ` can be read;
- a harmless SPI test frame such as `AA 55 00 FF` can be transmitted;
- output is visible over console/RTT/UART;
- the validation log can be updated with the result.

## What not to claim yet

The project should not yet claim:

- real DW3110 RF exchange;
- full UWB transfer;
- production DWM3001 host control;
- completed node-to-Gateway telemetry;
- full DSP/TinyML Gateway pipeline;
- final OSHWA readiness.

Those claims require further bench evidence.

## Current project posture

At the end of the session, the repository is in a much clearer state:

- `main` is definitive;
- the old completion checklist work is safely merged;
- `stage2-uwb-rf-proof` is historical;
- a new focused feature branch exists for the NUCLEO SPI5/GPIO probe;
- the next technical step is bounded and specific;
- no new architecture document is required;
- the work remains aligned to the fixed Gateway completion checklist.

## Next actions

1. Stay on `gateway-nucleo-spi5-gpio-probe`.
2. Implement `nucleo_n657x0_q.overlay`.
3. Replace the probe scaffold `main.c` with real GPIO/SPI probe logic.
4. Update `prj.conf` if needed.
5. Update the probe README.
6. Run the artifact check locally.
7. Build in an NCS/Zephyr-enabled shell.
8. Flash the NUCLEO and capture output.
9. Update the pin map and validation log with real evidence.
10. Open a PR back into `main`.

## Closing note

The main achievement of the evening was not simply creating another branch. It was resolving branch ambiguity, confirming the completion checklist work is now safely in `main`, identifying the stale branch, and narrowing the next code step to a concrete hardware-facing probe. The Gateway work is now positioned to move from repository evidence into bench evidence.

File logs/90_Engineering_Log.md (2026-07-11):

# 90 Engineering Log

## NUCLEO-N657X0-Q standalone Zephyr bring-up

**Date:** 6 July 2026<br>
**Repository:** `Thin-Pod-Gateway-rev-0.1`<br>
**Branch:** `gateway-nucleo-spi5-gpio-probe`<br>
**Scope:** Gateway firmware-led bring-up, NUCLEO supervisor validation before Gateway PCB pin-path probing.

## Summary

This session moved the Gateway firmware work from board-level readiness into a validated NUCLEO Zephyr runtime baseline. The manufactured Gateway PCB and component soldering were already complete, with earlier power and continuity checks recorded. The open item was to prove that the STM32 NUCLEO-N657X0-Q supervisor could build, sign, flash, boot and produce console output under Zephyr before it is connected back into the Gateway SPI/GPIO path.

The evening achieved that standalone milestone. Zephyr `hello_world` was built for `nucleo_n657x0_q`, signed using the STM32 signing tool, flashed through STM32CubeProgrammer and ST-LINK, and confirmed running through the ST-LINK virtual COM port.

Observed console output:

```text
*** Booting Zephyr OS build v4.4.0-7558-g9a27e2e135af ***
Hello World! nucleo_n657x0_q/stm32n657xx
```

This confirms that the NUCLEO supervisor can now act as the firmware platform for the next Gateway step: a minimal GPIO-only pin-path probe, followed by SPI5 dummy transfer and then DWM3001/DW3110-facing proof.

## Work completed

### 1. Zephyr workspace and build backend

The Windows Zephyr workspace was brought into a usable state under:

```text
C:\Users\n_tho\zephyrproject
```

The Python virtual environment was activated and the missing build backend was corrected by installing Ninja into the virtual environment:

```text
C:\Users\n_tho\zephyrproject\.venv\Scripts\ninja.exe
```

This resolved the earlier issue where Winget showed Ninja installed but PowerShell could not locate `ninja.exe`.

### 2. Zephyr Python requirements

The earlier `jsonschema` failure during `west sdk install` was resolved by installing Zephyr's Python requirements into the active `.venv`:

```powershell
python -m pip install @((west packages pip) -split ' ')
```

`jsonschema` then imported successfully, confirming that the missing dependency set had been corrected.

### 3. Zephyr SDK and ARM GNU toolchain

The Zephyr SDK 1.0.1 host tools were installed, followed by the missing ARM GNU toolchain:

```powershell
west sdk install --toolchains arm-zephyr-eabi
```

The SDK then exposed the expected ARM toolchain under:

```text
C:\Users\n_tho\zephyr-sdk-1.0.1\gnu\arm-zephyr-eabi
```

The `nucleo_n657x0_q` board target was visible through `west boards`.

### 4. STM32CubeProgrammer and signing tool path

The first successful `hello_world` build reached `zephyr.elf` but warned that the STM32 signing tool was unavailable. STM32CubeProgrammer was already installed but its `bin` directory was not on PATH.

The path was added for the active session and then repaired at user level:

```text
C:\Program Files\STMicroelectronics\STM32Cube\STM32CubeProgrammer\bin
```

After this, both tools resolved:

```text
STM32_Programmer_CLI.exe
STM32_SigningTool_CLI.exe
```

A clean rebuild then generated:

```text
zephyr.bin
zephyr.elf
zephyr.hex
zephyr.signed.bin
```

The signed image was generated at:

```text
C:\Users\n_tho\zephyrproject\zephyr\build\zephyr\zephyr.signed.bin
```

### 5. ST-LINK detection and PC USB issue

An initial `west flash` failed because no debug probe was detected. This was traced to Windows/USB enumeration rather than Zephyr. Rebooting the PC and using a different USB port allowed STM32CubeProgrammer to detect the NUCLEO:

```text
Board Name  : NUCLEO-N657X0-Q
ST-LINK SN  : 003900273234510E33353533
ST-LINK FW  : V3J16M7
Port        : COM7
Description : STMicroelectronics STLink Virtual COM Port
```

This established that the PC, cable and ST-LINK path were then functioning.

### 6. Target voltage fault traced to CN9

After ST-LINK enumeration, the target still failed to connect. STM32CubeProgrammer reported:

```text
Voltage : 0.00V
Unable to get core ID
No STM32 target found
```

The cause was the CN9 power selection jumper. CN9 was on the middle pair:

```text
CN9 = 3-4 / 5V_USB_SNK
```

For flashing through the ST-LINK USB connector, CN9 needed to be moved to:

```text
CN9 = 1-2 / 5V_STLK
```

After moving CN9, STM32CubeProgrammer reported target voltage and identified the STM32N6 device:

```text
Voltage     : 3.26V
Device ID   : 0x486
Device name : STM32N6xx
Device type : MCU
Device CPU  : Cortex-M55
```

This was the decisive power-path correction for the evening.

### 7. Flash and runtime proof

With target voltage present, `west flash` completed successfully using STM32CubeProgrammer and the external loader:

```text
File          : zephyr.signed.bin
Size          : 27.38 KB
Address       : 0x70000000
Download      : 100%
File download complete
```

After flashing, JP2 / BOOT1 was returned to run mode and PuTTY was opened on:

```text
COM7
115200 baud
8 data bits
no parity
1 stop bit
no flow control
```

The NUCLEO booted Zephyr and printed the expected `hello_world` output.

## Final hardware state after runtime proof

The validated standalone runtime state is:

```text
JP1 / BOOT0 = position 1
JP2 / BOOT1 = position 1
CN9          = 1-2 / 5V_STLK
USB          = ST-LINK USB connector
Console      = COM7, 115200 8N1, no flow control
```

The flashing state used during the session was:

```text
JP1 / BOOT0 = position 1
JP2 / BOOT1 = position 2
CN9          = 1-2 / 5V_STLK
```

## Evidence boundary

This log establishes:

```text
NUCLEO-N657X0-Q standalone Zephyr build, sign, flash and boot are complete.
```

It does not yet establish:

```text
NUCLEO fitted to Gateway PCB running Zephyr
Gateway RESET / CS / IRQ pin-path confirmation
SPI5 dummy transfer
DWM3001 / DW3110 register-level communication
UWB RF proof
```

The next Gateway action should therefore remain firmware-led and conservative.

## Next steps

1. Create a minimal NUCLEO Gateway GPIO-only Zephyr app.

   Initial pin targets:

   ```text
   PD0  -> DWM_RESET
   PA3  -> DWM_CS
   PB9  -> DWM_IRQ
   ```

   The first app should only print a boot banner, configure the GPIOs, toggle reset and CS slowly, read IRQ, and print a heartbeat.

2. Build the GPIO probe standalone before reconnecting the NUCLEO to the Gateway PCB.

3. Fit/connect the NUCLEO to the Gateway PCB and confirm the physical pin paths at the DWM3001-CDK header.

4. Add SPI5 only after reset, CS and IRQ are physically confirmed.

   SPI5 mapping remains:

   ```text
   PE15 -> SPI5_SCK
   PG1  -> SPI5_MISO
   PG2  -> SPI5_MOSI
   PA3  -> DWM_CS
   PB9  -> DWM_IRQ
   PD0  -> DWM_RESET
   ```

5. Perform a harmless SPI dummy transfer before any DW3110 register-level behaviour.

6. Move to DW3110 identity/status read only after SPI edge activity is confirmed on the real header pins.

7. Defer UWB RF proof until after the NUCLEO-to-DWM firmware path is evidenced.

## Risk notes

The main risk for the next stage is overreach. The NUCLEO is now a proven Zephyr target, but the Gateway PCB path is still unproven under NUCLEO firmware. The next log should therefore capture reset, CS, IRQ and SPI evidence separately.

The CN9 issue should remain documented because it creates a misleading state: ST-LINK can enumerate while the STM32 target voltage remains at `0.00V`. Future flashing failures should include an immediate check of CN9 and the CubeProgrammer voltage reading.

The Windows USB issue should also remain documented. ST-LINK detection improved after changing PC USB port, and future failures should first check `STM32_Programmer_CLI.exe -l` before changing firmware or jumpers.

## Outcome

The evening successfully moved the Gateway work past a toolchain and NUCLEO runtime blocker. The project now has a validated STM32N657 Zephyr supervisor baseline ready for Gateway-specific GPIO and SPI bring-up.

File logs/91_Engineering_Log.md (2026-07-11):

# 91 Engineering Log

## Thin-Pod Gateway rev 0.1: NUCLEO GPIO Probe Runtime Proof

**Date:** 7 July 2026<br>
**Repository:** `Thin-Pod-Gateway-rev-0.1`<br>
**Branch:** `gateway-nucleo-spi5-gpio-probe`<br>
**Scope:** NUCLEO-N657X0-Q GPIO-only firmware probe for Gateway bring-up

---

## High-level summary

This session advanced the Gateway bring-up from a standalone Zephyr `hello_world` proof to a purpose-built GPIO probe for the Thin-Pod Gateway rev 0.1 hardware path.

The main objective was deliberately narrow: prove that the NUCLEO-N657X0-Q can build, sign, flash and run Gateway-specific GPIO firmware before moving toward SPI5 or DW3110/UWB behaviour.

The GPIO probe firmware was added under:

```text
firmware/nucleo_gpio_probe/
```

The probe targets three Gateway control/readback signals:

```text
PD0  -> DWM_RESET
PA3  -> DWM_CS
PB9  <- DWM_IRQ
```

The firmware does not initialise SPI, does not attempt DW3110 register access, and does not perform UWB RF work. This keeps the evidence boundary clean: GPIO firmware behaviour first, Gateway PCB signal-path measurement next.

---

## Work completed

A new Zephyr application was added to the Gateway repository:

```text
firmware/nucleo_gpio_probe/CMakeLists.txt
firmware/nucleo_gpio_probe/prj.conf
firmware/nucleo_gpio_probe/README.md
firmware/nucleo_gpio_probe/boards/nucleo_n657x0_q.overlay
firmware/nucleo_gpio_probe/src/main.c
```

The initial application commit was:

```text
2ab718f Add NUCLEO GPIO pin-path probe
```

A first build exposed a devicetree issue. The overlay created named GPIO nodes, but the nodes were not attached to a binding that allowed Zephyr to treat their `gpios` properties as GPIO phandle arrays. The overlay was corrected by placing the probe GPIO nodes under a `gpio-leds` compatible parent and explicitly enabling the relevant GPIO controllers.

The devicetree fix was committed as:

```text
6e6e0a9 Fix GPIO probe devicetree bindings
```

The local Zephyr build output directory was then added to `.gitignore` so that generated files would not be tracked:

```text
/build/
```

That repository hygiene fix was committed as:

```text
c39f4f9 Ignore local Zephyr build output
```

After the build directory was intentionally removed, the GPIO probe was rebuilt from scratch. The build completed successfully, linked the Zephyr ELF, and generated the STM32N6 signed image:

```text
zephyr.elf
zephyr.signed.bin
```

The GPIO probe image was then flashed successfully to the NUCLEO-N657X0-Q using `west flash` and STM32CubeProgrammer.

The flashed image booted and produced the expected PuTTY runtime output on the ST-LINK virtual COM port. The runtime screenshot was saved and committed as:

```text
images/GPIO_Probe_PuTTY.png
```

The screenshot commit was:

```text
6e99b6b Add NUCLEO GPIO probe runtime screenshot
```

---

## Runtime evidence

The PuTTY output showed the GPIO probe running continuously:

```text
probe=7  phase=LOW  reset=0 cs=0 irq=0
probe=7  phase=HIGH reset=1 cs=1 irq=0
probe=8  phase=LOW  reset=0 cs=0 irq=0
probe=8  phase=HIGH reset=1 cs=1 irq=0
probe=9  phase=LOW  reset=0 cs=0 irq=0
probe=9  phase=HIGH reset=1 cs=1 irq=0
```

This confirms that the NUCLEO is no longer running the generic `hello_world` image. It is running the Gateway-specific GPIO probe application.

The runtime evidence proves:

```text
RESET logical state toggles in firmware
CS logical state toggles in firmware
IRQ is readable in firmware
Firmware loop is stable
Serial console output is working
```

The observed `irq=0` value is acceptable at this stage. It indicates that PB9 is being read as low in the present setup. This session does not yet require IRQ activity, only that the firmware can configure and sample the input.

---

## Current evidence chain

The branch now contains a clean firmware bring-up sequence:

```text
NUCLEO Zephyr hello_world proof captured
Gateway GPIO probe app added
Devicetree binding issue found and fixed
Local build output ignored
GPIO probe rebuilt successfully
STM32N6 signed image generated
GPIO probe flashed successfully
GPIO probe runtime confirmed in PuTTY
Runtime screenshot committed
Working tree clean
Branch pushed to origin
```

The current branch state after the session was:

```text
On branch gateway-nucleo-spi5-gpio-probe
Your branch is up to date with 'origin/gateway-nucleo-spi5-gpio-probe'.
nothing to commit, working tree clean
```

---

## Evidence boundary

This session completes the standalone NUCLEO GPIO firmware proof.

It does not yet prove that the signals are present at the DWM3001-CDK header through the Gateway PCB. That remains the next bench task.

The next evidence boundary is physical signal-path confirmation at the DWM3001-CDK header:

```text
RESET  PD0 -> J10.12  toggles low/high
CS     PA3 -> J10.24  toggles low/high
IRQ    PB9 <- J10.15  reads stable level
GND    common ground confirmed
```

The acceptance point for the next step is the DWM3001-CDK header, not merely the NUCLEO pins and not merely the serial console output.

---

## Risk profile

The main technical risk has moved from firmware build/toolchain uncertainty to physical signal-path verification.

The build and flash path is now known good. The remaining risk is assuming that firmware-level toggling proves Gateway PCB connectivity. It does not. The next step must confirm the RESET, CS and IRQ paths electrically at the DWM3001-CDK header.

The second risk is scope creep. SPI5, DW3110 register access and UWB RF proof should remain deferred until the GPIO paths are measured and logged.

---

## Next actions

1. Keep using branch:

```text
gateway-nucleo-spi5-gpio-probe
```

2. Fit or connect the NUCLEO/Gateway PCB arrangement in the intended test configuration.

3. With the GPIO probe running, measure at the DWM3001-CDK header:

```text
J10.12 RESET
J10.24 CS
J10.15 IRQ
GND reference
```

4. Capture measurement evidence in the next engineering log.

5. Only after GPIO signal-path evidence is captured, proceed to a minimal SPI5 dummy-transfer probe.

---

## Session judgement

This was a good bring-up session.

The work produced a specific Gateway firmware artefact, resolved a real Zephyr devicetree issue, preserved the build hygiene of the repository, flashed the NUCLEO successfully, and captured runtime proof in the repository.

The Gateway rev 0.1 work is now positioned for the next concrete hardware milestone: measured RESET, CS and IRQ path confirmation at the DWM3001-CDK header.

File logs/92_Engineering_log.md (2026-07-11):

# 92 Engineering Log

## Thin-Pod Gateway rev 0.1: GPIO Signal-Path Confirmation at DWM3001-CDK Header

**Date:** 7 July 2026<br>
**Repository:** `Thin-Pod-Gateway-rev-0.1`<br>
**Branch:** `gateway-nucleo-spi5-gpio-probe`<br>
**Scope:** Gateway PCB signal-path confirmation for NUCLEO GPIO probe outputs and IRQ input

---

## High-level summary

This session completed the first physical Gateway PCB signal-path confirmation using the previously flashed NUCLEO GPIO probe firmware.

The previous session proved that the NUCLEO-N657X0-Q could build, sign, flash and run the GPIO probe. This session moved the evidence boundary from firmware runtime output to physical measurements at the Gateway-to-DWM3001-CDK interface.

The confirmed paths were:

```text
GND    common ground confirmed
RESET  CN15.33 / PD0 -> DWM3001-CDK J10.12, TP5
CS     CN15.17 / PA3 -> DWM3001-CDK J10.24, TP7
IRQ    CN15.16 / PB9 <- DWM3001-CDK J10.15, TP6
```

The GPIO probe was left running during measurement. RESET and CS were observed on the oscilloscope as repeated low/high pulse trains matching the probe firmware state transitions. IRQ was measured with a DMM on DC voltage range and was consistent with the PuTTY console reporting `irq=0`.

This session therefore confirms that the Gateway PCB carries the required RESET, CS and IRQ paths between the NUCLEO and the DWM3001-CDK header/test-point boundary.

---

## Starting point

The session began from the proven firmware state recorded in `91_Engineering_Log.md`.

The NUCLEO was running:

```text
firmware/nucleo_gpio_probe
```

The GPIO probe repeatedly drives RESET and CS low/high and samples IRQ:

```text
probe=N phase=LOW  reset=0 cs=0 irq=0
probe=N phase=HIGH reset=1 cs=1 irq=0
```

The test objective was to confirm that these firmware-level states were visible electrically at the DWM3001-CDK interface.

---

## Ground confirmation

Common ground was confirmed before signal measurement.

Result:

```text
GND common: confirmed
```

This established the measurement reference for the subsequent RESET, CS and IRQ checks.

---

## RESET path confirmation

The RESET path was measured from the NUCLEO side through the Gateway PCB to the DWM3001-CDK boundary.

Signal path:

```text
CN15.33 / PD0 -> DWM3001-CDK J10.12, TP5
```

Measurement:

```text
Instrument: oscilloscope
Probe point: TP5 / DWM3001-CDK J10.12
Expected: repeated low/high pulse train
Observed: repeated low/high pulse train
```

The observed RESET waveform matched the GPIO probe firmware behaviour:

```text
phase=LOW   reset=0
phase=HIGH  reset=1
```

Result:

```text
RESET path confirmed
```

---

## CS path confirmation

The chip-select path was measured from the NUCLEO side through the Gateway PCB to the DWM3001-CDK boundary.

Signal path:

```text
CN15.17 / PA3 -> DWM3001-CDK J10.24, TP7
```

Measurement:

```text
Instrument: oscilloscope
Probe point: TP7 / DWM3001-CDK J10.24
Expected: repeated low/high pulse train
Observed: repeated low/high pulse train
```

The CS trace showed the same expected pulse behaviour as RESET, matching the GPIO probe firmware loop.

Result:

```text
CS path confirmed
```

---

## IRQ path confirmation

The IRQ path was measured as an input path from the DWM3001-CDK boundary back to the NUCLEO.

Signal path:

```text
CN15.16 / PB9 <- DWM3001-CDK J10.15, TP6
```

Measurement:

```text
Instrument: DMM
Mode: DC volts
Probe point: TP6 / DWM3001-CDK J10.15
Measured value: 0.5 V DC
Console state: irq=0
```

The measured TP6 level was consistent with the PuTTY output reporting `irq=0`.

Result:

```text
IRQ input path confirmed for the current GPIO-probe stage
```

The measured value should be recorded as 0.5 V DC rather than rounded to 0 V.

---

## Completed measurement table

```text
Signal   NUCLEO pin       Test point   DWM header   Expected behaviour        Observed
GND      GND              TP1/J10 GND  J10 GND      common ground             confirmed
RESET    CN15.33 / PD0    TP5          J10.12       toggles low/high          confirmed on scope
CS       CN15.17 / PA3    TP7          J10.24       toggles low/high          confirmed on scope
IRQ      CN15.16 / PB9    TP6          J10.15       stable readable level     0.5 V DC, PuTTY irq=0
```

---

## Evidence captured

The session captured measurement evidence for:

```text
RESET pulse train at TP5 / J10.12
CS pulse train at TP7 / J10.24
IRQ DC level at TP6 / J10.15
Common ground confirmation
```

The RESET and CS results provide active signal-path proof. The IRQ result provides input-level proof aligned with the firmware console output.

---

## Engineering judgement

The Gateway PCB GPIO signal-path confirmation is complete for this stage.

The firmware-level GPIO proof and the PCB-level signal-path proof now agree:

```text
Firmware drives RESET and CS
RESET and CS are visible at the DWM3001-CDK boundary
Firmware reads IRQ as low
TP6 measures low relative to confirmed common ground
```

This gives the Gateway rev 0.1 work firmer ground: practical evidence, clean commits, and real forward motion.

---

## Risk profile

The main remaining technical risk has moved from GPIO routing to SPI5 routing and peripheral configuration.

RESET, CS and IRQ have now been checked at the intended boundary. The next milestone should continue the same evidence-first method by proving SPI5 edge activity before attempting DW3110 register access.

The expected next-stage risks are:

```text
SPI5 devicetree node or pinctrl mismatch
incorrect STM32 alternate-function mapping for PE15, PG1 or PG2
SPI transfer completing in firmware while no edge activity reaches the DWM3001-CDK header
MISO returning an idle value during dummy transfers
```

These risks are manageable if the next step remains a dummy-transfer probe.

---

## Next steps

Next steps are to implement the dedicated SPI5 dummy-transfer probe described in the current bring-up plan.

That next probe should remain scoped to electrical/path confirmation:

```text
CS     PA3  -> J10.24 / TP7   low during transfer
SCK    PE15 -> J10.23 / TP10  clock burst
MOSI   PG2  -> J10.19 / TP11  dummy byte activity
MISO   PG1  <- J10.21 / TP12  sampled and printed as RX bytes
GND    common ground remains confirmed
```

The SPI dummy-transfer stage should use a simple byte pattern:

```text
0xAA 0x55 0x00 0xFF
```

A successful next milestone will be:

```text
spi_transceive returns ret=0
CS pulses at TP7 / J10.24
SCK bursts at TP10 / J10.23
MOSI activity appears at TP11 / J10.19
MISO is sampled and RX bytes are printed
```

DW3110 register reads and UWB RF proof should follow only after the SPI5 dummy-transfer path has been measured and logged.

---

## Session conclusion

This session established the Gateway PCB GPIO signal paths needed before SPI work.

GND, RESET, CS and IRQ are now confirmed at the DWM3001-CDK header/test-point boundary. The project is ready to proceed to SPI5 dummy-transfer implementation and measurement.

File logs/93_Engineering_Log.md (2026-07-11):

# 93 Engineering Log

## Thin-Pod Gateway rev 0.1: SPI5 Dummy-Transfer Probe Firmware Proof

**Date:** 7 July 2026<br>
**Repository:** `Thin-Pod-Gateway-rev-0.1`<br>
**Branch:** `gateway-nucleo-spi5-gpio-probe`<br>
**Scope:** NUCLEO-N657X0-Q SPI5 dummy-transfer firmware bring-up

---

## High-level summary

This session advanced the Gateway firmware bring-up from confirmed GPIO signal-path evidence to the first successful SPI5 dummy-transfer firmware proof.

The previous session confirmed the Gateway PCB GPIO paths for GND, RESET, CS and IRQ at the DWM3001-CDK header/test-point boundary. This session created a dedicated SPI5 dummy-transfer probe to exercise the planned SPI path before attempting DW3110 register access or UWB behaviour.

The new firmware application was added under:

```text
firmware/nucleo_spi5_dummy_probe/
```

The intended SPI5 signal paths are:

```text
CS     PA3  -> DWM3001-CDK J10.24 / TP7
SCK    PE15 -> DWM3001-CDK J10.23 / TP10
MOSI   PG2  -> DWM3001-CDK J10.19 / TP11
MISO   PG1  <- DWM3001-CDK J10.21 / TP12
```

The dummy probe transmits the test pattern:

```text
0xAA 0x55 0x00 0xFF
```

The application keeps the scope deliberately narrow. It performs no DW3110 register access and no UWB RF work.

---

## Firmware added

A new Zephyr application was created:

```text
firmware/nucleo_spi5_dummy_probe/CMakeLists.txt
firmware/nucleo_spi5_dummy_probe/prj.conf
firmware/nucleo_spi5_dummy_probe/boards/nucleo_n657x0_q.overlay
firmware/nucleo_spi5_dummy_probe/src/main.c
```

The first SPI5 dummy-transfer probe commit was:

```text
50dd84d Add NUCLEO SPI5 dummy-transfer probe
```

The overlay enables SPI5 and maps the planned Gateway pins:

```text
PE15 -> SPI5 SCK
PG1  -> SPI5 MISO
PG2  -> SPI5 MOSI
PA3  -> manual DWM CS GPIO
PD0  -> DWM RESET GPIO
PB9  -> DWM IRQ GPIO
```

Manual CS handling was retained so the CS line can be observed clearly at TP7 / J10.24 during transfer attempts.

---

## Initial build and text-encoding issue

The first build attempt exposed a Kconfig parsing issue in `prj.conf`:

```text
warning: ignoring malformed line '∩╗┐CONFIG_GPIO=y'
error: Aborting due to Kconfig warnings
```

This was caused by a UTF-8 byte-order mark at the start of the file. The SPI5 probe source files were rewritten as UTF-8 without BOM.

After that correction, the application configured, built, linked and generated a signed STM32N6 image successfully.

---

## Initial SPI runtime result

The initial flashed SPI5 probe booted and ran, but `spi_transceive()` returned:

```text
ret=-22
```

The console output showed repeated lines of this form:

```text
spi_probe=N ret=-22 irq=0 tx=aa 55 00 ff rx=00 00 00 00
```

This confirmed that:

```text
the SPI5 probe image was booting
the main loop was running
the TX test pattern was being prepared
IRQ remained readable as irq=0
the SPI transaction was being rejected before a successful transfer completed
```

The error value `-22` corresponds to `EINVAL`, indicating an invalid SPI transfer/configuration condition.

---

## SPI master-mode repair

The SPI operation field was then made explicit by adding `SPI_OP_MODE_MASTER`:

```c
.operation = SPI_OP_MODE_MASTER |
     SPI_WORD_SET(8) |
     SPI_TRANSFER_MSB,
```

A temporary PowerShell replacement inserted literal backtick characters into the C file, producing a compile error:

```text
error: stray '`' in program
```

The source file was then rewritten cleanly as UTF-8 without BOM. The repaired source built, linked, signed and flashed successfully.

After this repair, runtime still reported:

```text
ret=-22
```

This narrowed the issue away from C syntax and missing master-mode declaration.

---

## SPI frequency correction

The dummy probe originally requested:

```c
#define SPI5_FREQUENCY_HZ 100000U
```

The SPI frequency was increased to:

```c
#define SPI5_FREQUENCY_HZ 1000000U
```

After rebuilding and flashing the 1 MHz version, PuTTY showed repeated successful SPI transaction completion:

```text
spi_probe=N ret=0 irq=0 tx=aa 55 00 ff rx=00 00 00 00
```

This resolved the earlier `ret=-22` condition.

The 1 MHz firmware fix was committed as:

```text
f02b4b1 Set SPI5 dummy probe frequency to 1 MHz
```

---

## Runtime evidence

The successful PuTTY output demonstrated:

```text
SPI5 probe boots
the SPI5 dummy-transfer loop runs continuously
spi_transceive() completes with ret=0
the TX pattern is aa 55 00 ff
IRQ remains readable as irq=0
RX currently reads 00 00 00 00
```

The RX value is acceptable at this stage. The purpose of this stage is firmware-side dummy-transfer completion, not DW3110 protocol interpretation.

Result:

```text
Firmware-side SPI5 dummy-transfer proof: complete
```

---

## Repository hygiene

A `.gitattributes` file was added to reduce future line-ending noise in diffs.

Commit:

```text
036136c Add line-ending normalization rules
```

The rules cover key source and documentation files:

```text
*.c
*.h
*.conf
*.overlay
*.dts
*.dtsi
*.md
*.txt
CMakeLists.txt
```

Binary artefacts such as images and zip files are marked as binary.

The line-ending rules were added after the SPI5 source diff showed `^M` markers and large line-ending churn. The working tree returned to a clean state after the commit and push.

---

## Current evidence chain

At the end of this session, the branch contains:

```text
GPIO probe runtime proof
GPIO PCB signal-path confirmation
SPI5 dummy-transfer probe application
SPI5 1 MHz runtime fix
SPI5 dummy-transfer ret=0 firmware proof
line-ending normalization rules
```

Current branch state after the final push:

```text
On branch gateway-nucleo-spi5-gpio-probe
Your branch is up to date with 'origin/gateway-nucleo-spi5-gpio-probe'.
nothing to commit, working tree clean
```

---

## Engineering judgement

This session completed the firmware-side SPI5 dummy-transfer milestone.

The Gateway work has now progressed through three increasingly concrete layers:

```text
1. NUCLEO Zephyr build/flash/boot proof
2. Gateway GPIO signal-path proof at the DWM3001-CDK boundary
3. SPI5 dummy-transfer firmware proof with ret=0
```

The next evidence boundary is electrical confirmation of the SPI5 signals at the Gateway PCB test points and DWM3001-CDK header.

---

## Risk profile

The main remaining risk has moved from Zephyr SPI transaction acceptance to physical SPI5 signal-path confirmation.

The firmware now reports `ret=0`, so the SPI driver is accepting and completing the dummy transaction. The next task is to confirm that the expected edges are present at the board boundary.

Specific risks for the next stage are:

```text
SCK activity absent at TP10 despite ret=0
MOSI activity absent at TP11 despite ret=0
CS pulse timing too narrow for easy capture
MISO remaining idle during dummy transfer
incorrect interpretation of RX bytes before a DW3110 register-read stage
```

These risks are manageable with scope or logic-analyser evidence at the relevant test points.

---

## Next steps

Next steps are the SPI5 electrical/path measurements defined in the current bring-up plan.

Measure with the SPI5 dummy probe running:

```text
CS     TP7  / J10.24   low pulse during transfer
SCK    TP10 / J10.23   clock burst
MOSI   TP11 / J10.19   data activity for aa 55 00 ff
MISO   TP12 / J10.21   sampled level/activity, RX currently 00 00 00 00
```

Suggested acceptance condition:

```text
CS pulses at TP7 / J10.24
SCK bursts at TP10 / J10.23
MOSI activity appears at TP11 / J10.19
MISO is sampled and RX bytes are printed
PuTTY continues to report ret=0
```

DW3110 register access and UWB RF proof should follow after SPI5 electrical signal-path evidence has been captured and logged.

---

## Session conclusion

This session established the first successful SPI5 dummy-transfer firmware proof for the Thin-Pod Gateway rev 0.1 NUCLEO supervisor.

The key result is:

```text
spi_probe=N ret=0 irq=0 tx=aa 55 00 ff rx=00 00 00 00
```

The project is now ready for SPI5 scope evidence at TP7, TP10, TP11 and TP12.

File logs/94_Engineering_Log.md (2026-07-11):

# 94 Engineering Log

## Thin-Pod Gateway rev 0.1: SPI5 Electrical Proof at Gateway/DWM Boundary

**Date:** 8 July 2026<br>
**Repository:** `Thin-Pod-Gateway-rev-0.1`<br>
**Branch:** `gateway-nucleo-spi5-gpio-probe`<br>
**Scope:** SPI5 electrical signal-path confirmation using 64-byte stretched dummy-transfer probe

---

## High-level summary

This session completed the SPI5 electrical proof boundary for the Thin-Pod Gateway rev 0.1 NUCLEO supervisor path.

The previous engineering log established firmware-side SPI5 dummy-transfer success, with Zephyr accepting and completing `spi_transceive()` calls at 1 MHz. The key runtime result was:

```text
spi_probe=N ret=0 irq=0 tx=aa 55 00 ff rx=00 00 00 00
```

This session moved beyond firmware success and captured physical SPI5 activity at the Gateway PCB / DWM3001-CDK boundary.

The measured lines were:

```text
TP7   / J10.24   CS
TP10  / J10.23   SCK
TP11  / J10.19   MOSI
TP12  / J10.21   MISO
```

The SPI5 dummy-transfer probe was temporarily stretched from 4 bytes to 64 bytes to make the SPI burst easier to capture on the handheld oscilloscope. This increased the expected clock-burst duration from approximately 32 microseconds to approximately 512 microseconds at 1 MHz.

---

## Starting point

At the start of the session, the branch already contained:

```text
Zephyr NUCLEO build/flash/boot evidence
GPIO probe runtime evidence
Gateway GPIO signal-path confirmation
SPI5 dummy-transfer probe application
SPI5 1 MHz runtime fix
Engineering Log 93
```

The key remaining question was whether the firmware-side `ret=0` condition corresponded to observable electrical activity at the SPI5 board boundary.

---

## Initial scope attempts

The first scope captures were attempted with the original 4-byte dummy-transfer probe.

Expected transfer length:

```text
4 bytes x 8 bits = 32 clocks
1 MHz SPI clock = approximately 32 microseconds
```

The early captures showed activity, but the event was short and difficult to capture cleanly. Several images showed edge detail or partial activity on TP7 and TP10, but they did not clearly show a CS-framed SCK burst.

Engineering judgement from the initial attempts:

```text
Firmware running: confirmed
ret=0 runtime output: confirmed
TP7 / TP10 activity: observed
Clean formal CS-framed SCK proof: still pending
```

The practical issue was capture visibility, not firmware failure.

---

## Stretched-transfer firmware change

To make the electrical evidence easier to capture, the SPI5 dummy-transfer probe was deliberately stretched from 4 bytes to 64 bytes.

The firmware was updated with:

```c
#define SPI_PROBE_BYTES 64U
```

The transmit buffer repeats the existing dummy pattern:

```text
AA 55 00 FF AA 55 00 FF ...
```

The runtime print format was updated to show the transfer length and the start of the TX/RX buffers:

```text
spi_probe=N ret=0 irq=0 len=64 tx_start=aa 55 00 ff rx_start=00 00 00 00
```

The stretched probe retains the same purpose:

```text
SPI5 electrical/path confirmation only
No DW3110 register access
No UWB RF
```

The stretched firmware was built, signed and flashed successfully. PuTTY confirmed repeated successful runtime output:

```text
spi_probe=N ret=0 irq=0 len=64 tx_start=aa 55 00 ff rx_start=00 00 00 00
```

The firmware change was committed as:

```text
8e4d122 Stretch SPI5 dummy probe transfer for scope capture
```

---

## Scope setup

The working oscilloscope setup for the stretched transfer was:

```text
Probe:        x10
Coupling:     DC
Vertical:     approximately 2 V/div
Timebase:     100 us/div for full transfer evidence
Trigger:      CH1 falling edge
Trigger mode: Single
Trigger line: TP7 / CS
Ground:       confirmed Gateway/DWM ground
```

The longer 64-byte transfer made the SPI activity visible across a substantial portion of the display.

Expected timing at 1 MHz:

```text
64 bytes x 8 bits = 512 clocks
1 clock at 1 MHz = 1 microsecond
Expected SCK burst duration = approximately 512 microseconds
```

---

## TP7 / TP10: CS and SCK evidence

Scope capture:

```text
images/SPI5_TP7_CS_TP10_SCK_64byte_scope.jpg
```

Signal mapping:

```text
Yellow: TP7  / CS
Blue:   TP10 / SCK
```

Observed result:

```text
TP7 / CS showed the active-low chip-select window.
TP10 / SCK showed dense clock activity during the CS-low interval.
```

Engineering classification:

```text
TP7 / CS activity:   PASS
TP10 / SCK activity: PASS
CS-framed SCK proof: PASS
```

This capture confirms that the SPI5 clock is physically present at the Gateway/DWM boundary while chip-select is asserted.

---

## TP7 / TP11: CS and MOSI evidence

Scope capture:

```text
images/SPI5_TP7_CS_TP11_MOSI_64byte_scope.jpg
```

Signal mapping:

```text
Yellow: TP7  / CS
Blue:   TP11 / MOSI
```

Observed result:

```text
TP7 / CS showed the active-low chip-select window.
TP11 / MOSI showed data activity during the CS-low interval.
```

The MOSI activity is consistent with the repeated dummy transmit pattern:

```text
AA 55 00 FF
```

Engineering classification:

```text
TP7 / CS activity:    PASS
TP11 / MOSI activity: PASS
CS-framed MOSI proof: PASS
```

This capture confirms that the SPI5 MOSI path is physically active at the Gateway/DWM boundary during a valid firmware-side SPI transfer.

---

## TP7 / TP12: CS and MISO evidence

Scope capture:

```text
images/SPI5_TP7_CS_TP12_MISO_64byte_scope.jpg
```

Signal mapping:

```text
Yellow: TP7  / CS
Blue:   TP12 / MISO
```

Observed result:

```text
TP7 / CS showed the active-low chip-select window.
TP12 / MISO was observed and remained mostly quiet / low during the dummy transfer.
```

This is acceptable at this stage. The firmware is still performing a dummy transfer, not a meaningful DW3110 register read. The runtime output was consistent with the quiet MISO observation:

```text
rx_start=00 00 00 00
```

Engineering classification:

```text
TP7 / CS activity:     PASS
TP12 / MISO observed:  PASS / quiet as expected for dummy transfer
CS-framed MISO state:  documented
```

---

## Evidence committed

The stretched firmware and scope captures were committed in two separate commits:

```text
8e4d122 Stretch SPI5 dummy probe transfer for scope capture
cfc9b02 Add SPI5 64-byte scope evidence
```

Images added:

```text
images/SPI5_TP7_CS_TP10_SCK_64byte_scope.jpg
images/SPI5_TP7_CS_TP11_MOSI_64byte_scope.jpg
images/SPI5_TP7_CS_TP12_MISO_64byte_scope.jpg
```

The branch returned to a clean state after the image commit and push:

```text
On branch gateway-nucleo-spi5-gpio-probe
Your branch is up to date with 'origin/gateway-nucleo-spi5-gpio-probe'.

nothing to commit, working tree clean
```

---

## Current evidence chain

At the end of this session, the Gateway branch contains the following evidence chain:

```text
1. NUCLEO Zephyr build/sign/flash/boot proof
2. GPIO probe firmware proof
3. GPIO signal-path proof at DWM3001-CDK boundary
4. SPI5 dummy-transfer firmware proof with ret=0
5. SPI5 64-byte stretched-transfer firmware helper
6. SPI5 electrical proof at TP7, TP10, TP11 and TP12
```

The SPI5 electrical proof now covers:

```text
TP7  / CS    active-low chip-select window
TP10 / SCK   clock burst during CS-low interval
TP11 / MOSI  data activity during CS-low interval
TP12 / MISO  observed quiet/low state during dummy transfer
```

---

## Engineering judgement

This session completed the SPI5 dummy-transfer electrical proof boundary.

The Gateway SPI5 path is now supported by:

```text
runtime firmware evidence
ret=0 SPI transaction completion
64-byte stretched dummy-transfer scope helper
scope evidence at CS, SCK, MOSI and MISO
clean commits
pushed branch
```

The risk profile has moved again. The open question is no longer whether the NUCLEO can issue an SPI5 transfer or whether SPI5 activity appears at the Gateway/DWM boundary. The next meaningful question is whether controlled DW3110 register access can be performed through the same electrical path.

---

## Remaining limitations

This log deliberately does not claim:

```text
successful DW3110 register access
valid DW3110 device ID read
valid UWB radio operation
ranging
application-level Gateway behaviour
```

The MISO line was observed during dummy transfer, and the firmware reported `rx_start=00 00 00 00`. That is acceptable for this stage because the transfer was not constructed as a DW3110 register transaction.

---

## Next boundary

The next technical boundary is a controlled DW3110 register-read probe.

Recommended next step:

```text
Create a separate DW3110 register-read probe or extend the existing SPI5 probe in a controlled branch.
Keep the 64-byte stretched-transfer scope helper available as bench evidence.
Attempt a minimal known-register read only after confirming the expected DW3110 SPI command format and reset/wake timing.
Retain the same evidence discipline: PuTTY output, scope capture if needed, commit, engineering log.
```

Candidate success criteria for the next stage:

```text
SPI transaction returns ret=0
CS, SCK and MOSI remain physically observable if scoped
MISO returns non-zero or recognisable DW3110 register data
the result is repeatable across resets
the firmware prints the register address, TX bytes, RX bytes and interpretation
```

---

## Session conclusion

The SPI5 electrical proof boundary is complete for the dummy-transfer stage.

The key result is:

```text
TP7 / CS, TP10 / SCK, TP11 / MOSI and TP12 / MISO were all observed at the Gateway/DWM boundary with the 64-byte stretched SPI5 dummy-transfer probe running at 1 MHz and PuTTY reporting ret=0 len=64.
```

The project is now ready to move from dummy-transfer electrical proof to controlled DW3110 register-read bring-up.

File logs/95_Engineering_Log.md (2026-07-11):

# 95 Engineering Log

## Thin-Pod Gateway rev 0.1 — Initial DW3110 Register-Read Probe

**Date:** 2026-07-09<br>
**Branch:** `gateway-dw3110-register-probe`<br>
**Commit:** `8697c5c Add NUCLEO DW3110 register-read probe`<br>
**Repository path:** `C:\ThinPod\Thin-Pod-Gateway-rev-0.1`

---

## 1. Purpose

This log records the first Gateway-local DW3110 register-read probe for the Thin-Pod Gateway rev 0.1 hardware.

The objective was deliberately narrow:

```text
NUCLEO-N657X0-Q -> Gateway PCB -> DWM3001-CDK / DW3110
Attempt to read DEV_ID register 0x00 over the verified SPI5 path.
```

This stage does not attempt UWB RF, ranging, node-to-Gateway communication, packet exchange, payload logging, or production driver integration.

---

## 2. Starting Point

The register-read probe was started after the following Gateway-local evidence had already been established:

```text
GPIO signal-path proof:              complete
SPI5 firmware dummy-transfer proof:  complete
SPI5 electrical proof:               complete
```

The verified Gateway SPI5 path was:

```text
TP7  / CS          PA3
TP10 / SCK         PE15
TP11 / COPI/MOSI   PG2
TP12 / CIPO/MISO   PG1
TP5  / RESET       PD0
TP6  / IRQ         PB9
```

The preceding evidence chain included:

```text
8e4d122  Stretch SPI5 dummy probe transfer for scope capture
cfc9b02  Add SPI5 64-byte scope evidence
d868022  Add engineering log 94 for SPI5 electrical proof
```

---

## 3. Firmware Added

A new standalone Zephyr probe application was added:

```text
firmware/nucleo_dw3110_register_probe/
```

Files added:

```text
firmware/nucleo_dw3110_register_probe/CMakeLists.txt
firmware/nucleo_dw3110_register_probe/README.md
firmware/nucleo_dw3110_register_probe/boards/nucleo_n657x0_q.overlay
firmware/nucleo_dw3110_register_probe/prj.conf
firmware/nucleo_dw3110_register_probe/src/main.c
```

The app reuses the previously verified GPIO and SPI5 mapping and attempts a raw DEV_ID read using register address `0x00`.

The firmware prints:

```text
TX bytes
RX bytes
candidate 32-bit little-endian interpretations
candidate 32-bit big-endian interpretations
expected DW3110-class value
SPI transaction result
```

Expected DW3110-class candidate value used by the probe:

```text
0xDECA0302
```

---

## 4. Build and Flash Evidence

The application was built using Zephyr for:

```text
Board: nucleo_n657x0_q
Target: stm32n657xx
```

Build completed successfully:

```text
[170/170] Linking C executable zephyr\zephyr.elf
```

The STM32 signing tool generated:

```text
zephyr.signed.bin
Size: 32.50 KB
Address: 0x70000000
```

Flash completed successfully through STM32CubeProgrammer / ST-LINK:

```text
File download complete
```

---

## 5. Runtime Evidence

PuTTY output showed the probe running repeatedly.

Representative output:

```text
dw3110_probe=21 ret=0 irq=0 reg=0x00 len=6
tx=00 00 00 00 00 00
rx=00 00 00 00 00 00
candidate offset=0 le=0x00000000 be=0x00000000
candidate offset=1 le=0x00000000 be=0x00000000
candidate offset=2 le=0x00000000 be=0x00000000
expected_dw3110_dev_id=0xdeca0302
probe_result=SPI_OK
```

Further repeated probes showed the same pattern:

```text
ret=0
rx=00 00 00 00 00 00
probe_result=SPI_OK
```

---

## 6. Interpretation

The result is a useful diagnostic milestone.

Confirmed:

```text
The new DW3110 register-probe app builds.
The signed image flashes to the NUCLEO-N657X0-Q.
The firmware runs and prints repeated probe output.
The SPI transaction completes with ret=0.
The Gateway SPI5 transaction path remains firmware-valid.
```

Not yet confirmed:

```text
DW3110 DEV_ID readback
CIPO/MISO return data from the DW3110
A match to 0xDECA0302 or 0xDECA03xx
```

Current observed result:

```text
SPI transaction complete, but RX remains all zero.
```

This should be treated as diagnostic evidence rather than a Gateway PCB failure. The preceding SPI5 dummy-transfer and scope evidence already proved the Gateway carrier board's CS, SCK, COPI/MOSI and CIPO/MISO signal paths at the test-point level.

---

## 7. Technical Boundary Reached

The Gateway has now reached the first register-probe boundary:

```text
Firmware probe implemented:    yes
Build/sign/flash successful:   yes
Runtime SPI transaction ret=0: yes
DW3110 DEV_ID returned:        no
```

Therefore the stage is best classified as:

```text
Initial DW3110 register-read probe: diagnostic partial pass
Gateway-local DW3110 bring-up:      still open
```

---

## 8. Likely Next Investigation

The next controlled refinement should focus on the conditions required for the DW3110 to drive CIPO/MISO data back to the NUCLEO.

Recommended next checks:

```text
1. Reset handling:
   Drive RESET low, then release the line as input/high-Z rather than holding it actively high.

2. Transaction framing:
   Test a fuller DW3000-style DEV_ID read transaction with a longer header and explicit read clocking.

3. Chip-select timing:
   Keep CS low across the full header and read phase.

4. Module ownership / routing:
   Confirm whether the DWM3001-CDK exposes the DW3110 SPI path directly to the external header in the expected state, or whether the onboard module controller owns the DW3110 SPI bus.

5. Scope fallback:
   If RX remains zero, scope TP7 / CS with TP12 / CIPO/MISO during the register probe.
```

Scope fallback pair:

```text
CH1: TP7  / CS
CH2: TP12 / CIPO/MISO
Trigger: CH1 falling edge
```

---

## 9. Repository Status

The new firmware probe was committed and pushed:

```text
8697c5c Add NUCLEO DW3110 register-read probe
```

Final Git status after push:

```text
On branch gateway-dw3110-register-probe
Your branch is up to date with 'origin/gateway-dw3110-register-probe'.

nothing to commit, working tree clean
```

---

## 10. Open-Hardware Readiness Implication

This stage improves the Gateway open-hardware evidence trail by adding a dedicated register-read probe app and documenting the first DW3110 access attempt.

The Gateway remains one technical proof away from the desired pre-packaging state:

```text
NUCLEO reads a known DW3110 register through the verified Gateway SPI5 path.
```

Once a repeatable DEV_ID or other recognised DW3110 register response is obtained, the Gateway will be ready to move from bring-up evidence collection into OSHWA/open-hardware packaging cleanup.

---

## 11. Summary

This was a valid and useful Gateway bring-up step.

```text
Build:        pass
Flash:        pass
Firmware run: pass
SPI ret=0:    pass
DEV_ID data:  pending
```

The next work should remain narrow: refine reset release, transaction framing and DWM3001-CDK direct-access assumptions until the DW3110 returns a repeatable register value.

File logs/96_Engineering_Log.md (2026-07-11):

# 96 Engineering Log

## Thin-Pod Gateway rev 0.1 — DWM3001-CDK Live State and UWB Module Access Model

**Date:** 2026-07-09<br>
**Branch:** `gateway-dw3110-register-probe`<br>
**Repository path:** `C:\ThinPod\Thin-Pod-Gateway-rev-0.1`<br>
**Status:** Completed live-state and access-model closeout record

---

## 1. Purpose

This log records the technical closeout step following the initial and refined NUCLEO-side DW3110 register-read probe.

The purpose is to confirm the live state of the Gateway Qorvo DWM3001-CDK and to record the Gateway rev 0.1 access-model decision:

```text
Gateway rev 0.1 treats the DWM3001-CDK as an intelligent UWB coprocessor/module.
```

---

## 2. Starting point

The following evidence already exists:

```text
GPIO signal-path proof:              complete
SPI5 dummy-transfer firmware proof:  complete
SPI5 electrical proof:               complete
Initial DW3110 register probe:       implemented and logged
DW3110 register probe v2:            reset/framing refinement committed
```

The NUCLEO-side DW3110 register probe reached the following state:

```text
Build/sign/flash: pass
Firmware run:     pass
SPI ret=0:        pass
DEV_ID data:      pending / all-zero RX
```

The direct NUCLEO-to-DW3110 path remains diagnostic rather than architectural.

---

## 3. Gateway CDK live-state check

### Method

The Gateway DWM3001-CDK was connected through its SEGGER J-Link / RTT interface.

RTT logging was opened using SEGGER J-Link RTT Viewer.

```text
Tool:        SEGGER J-Link RTT Viewer V8.52
Log started: 2026-07-09 19:23:30
Target role: Gateway DWM3001-CDK
```

### Observed output

The RTT log showed the Gateway Stage-1 firmware running and emitting poll / packet records.

Representative output:

```text
*** Booting nRF Connect SDK v3.3.1-1d7a0b0e49b8 ***
*** Using Zephyr OS v4.3.99-37e6c28576ee ***

Thin-Pod Gateway UWB initiator stage-1
gateway_id=0x0000 role=initiator backend=stub
packet_log_format=TPGW_PKT key=value
TPGW_POLL seq=1 dst=0x0001
TPGW_PKT seq=1 src=0x0001 dst=0x0000 uptime_ms=252 valid=0 samples=32 rate=1600 first_mg=-41 min_mg=-92 max_mg=85 mean_mg=-4 rms_mg=46 checksum=0x1abff43f
```

The same log continued with repeated `TPGW_POLL` and `TPGW_PKT` records.

### Result

```text
[x] Previous Stage-1 Gateway initiator/stub firmware confirmed.
[ ] Different firmware observed.
[ ] No RTT output observed.
[ ] CDK state not confirmed.
```

---

## 4. Interpretation of CDK state

The Gateway DWM3001-CDK is not in a neutral pass-through state.

The observed live firmware state is:

```text
Thin-Pod Gateway UWB initiator stage-1
gateway_id=0x0000
role=initiator
backend=stub
packet_log_format=TPGW_PKT key=value
```

This confirms that the onboard nRF52833 should be treated as an active module controller in the current Gateway setup.

Direct external NUCLEO ownership of the DW3110 remains unproven. The all-zero NUCLEO-side DW3110 DEV_ID result should therefore be interpreted as diagnostic evidence about direct-access limitations rather than as evidence against the Gateway carrier board.

---

## 5. Architecture decision

Gateway rev 0.1 adopts the DWM3001-CDK-as-UWB-coprocessor model.

```text
DWM3001-CDK:
    intelligent UWB coprocessor/module
    owns DW3110 radio control
    provides UWB role behaviour through module firmware

NUCLEO-N657X0-Q:
    Gateway supervisor / host
    owns admitted-window memory and analysis path
    communicates with the DWM subsystem through a defined host-interface contract

Gateway PCB:
    open-hardware carrier/interface board
    provides modular power, GPIO, SPI/host-interface routing and test points
```

Direct NUCLEO-to-DW3110 register probing is retained as diagnostic bring-up evidence and is not the primary technical gate for Gateway rev 0.1 open-hardware readiness.

---

## 6. Relationship to previous DW3110 probe work

The NUCLEO-side DW3110 register probe remains useful because it demonstrated:

```text
dedicated register-probe app builds
signed NUCLEO image flashes
runtime probe loop operates
SPI transaction returns ret=0
multiple DEV_ID read framings were attempted
RX remained all zero
```

The refined v2 probe tested:

```text
RESET driven low then released high-Z
CS wake pulse
manual CS low across full header/read transaction
minimal DEV_ID framing
six-zero diagnostic framing
two-byte subaddress-style framing
three-byte extended-style framing
```

No variant returned a recognised `0xDECA0302` or `0xDECA03xx` response.

This result now sits under the module-access investigation boundary.

---

## 7. Scope evidence status

Oscilloscope work during the DW3110 probe session was not retained as formal evidence because the instrument required recharge and one channel ground lead was found to be disconnected.

Scope evidence should be repeated later only after measurement-chain sanity checks:

```text
CH1 tip to TP1, ground to TP1: flat 0 V
CH2 tip to TP1, ground to TP1: flat 0 V
CH1/CH2 to known 3V3: about 3.3 V
CH2 to TP7 / CS: clean logic-level CS pulse
```

This scope re-check is supporting evidence, not the primary architecture gate.

---

## 8. Consequence for open-hardware readiness

Gateway rev 0.1 technical closeout now focuses on the modular carrier/interface boundary.

The certifiable hardware object is:

```text
Thin-Pod Gateway rev 0.1 modular carrier/interface board for integrating
a NUCLEO-N657X0-Q supervisor, DWM3001-CDK UWB coprocessor/module and
XIAO ESP32-C6 auxiliary network module.
```

Remaining technical work before packaging:

```text
1. Commit this CDK live-state record.
2. Commit the UWB module access-model architecture note.
3. Draft the DWM-to-NUCLEO host-interface protocol.
4. Perform optional corrected scope sanity capture once the oscilloscope is recharged.
```

---

## 9. Repository updates

Add / commit:

```text
docs/architecture/Gateway_UWB_Module_Access_Model.md
logs/96_Engineering_Log.md
logs/Gateway_CDK_Live_State_RTT_2026-07-09.log
```

Suggested commits:

```text
Add Gateway UWB module access model
Add engineering log 96 for DWM3001-CDK state and access model
```

---

## 10. Summary

This log closes the direct-DW3110 diagnostic branch as useful but not architecture-defining.

The Gateway rev 0.1 architecture now follows the modular model:

```text
DWM3001-CDK owns UWB/radio control.
NUCLEO supervises, stores, analyses and coordinates.
Gateway PCB provides the open-hardware modular carrier/interface layer.
```

The live Gateway CDK state confirms that the DWM3001-CDK is running the Stage-1 Gateway initiator/stub firmware and should be treated as an active UWB module/controller in the rev 0.1 Gateway architecture.

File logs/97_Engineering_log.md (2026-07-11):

# Engineering Log 97 — DWM3001-CDK Host-Interface Boot Stub and TP6 READY Timing Correlation

Date: 2026-07-09<br>
Branch: gateway-dw3110-register-probe<br>
Repository: Thin-Pod-Gateway-rev-0.1

## Summary

This session moved the Gateway rev 0.1 DWM3001-CDK host-interface work from documented pin feasibility into firmware, runtime proof and physical signal observation.

The DWM3001-CDK was treated as the Gateway UWB coprocessor/module. The NUCLEO remained the Gateway supervisor and future SPI host. The work focused on proving that the DWM-side firmware can own the J10 host-interface pins and drive the READY/IRQ path toward the Gateway PCB.

This log makes no direct NUCLEO-to-DW3110 register-control claim.

## Firmware work completed

A Zephyr application was brought up under:

```text
firmware/dwm3001cdk_host_interface_stub/
```

The application defines and uses the DWM3001-CDK J10 host-interface pin map:

```text
SCK candidate         = P0.31 / J10.23 / SPI1_CLK
MOSI candidate        = P0.27 / J10.19 / SPI1_MOSI
MISO candidate        = P0.07 / J10.21 / SPI1_MISO
CS candidate          = P0.30 / J10.24 / CS_RPI
READY / IRQ candidate = P0.28 / J10.15 / GPIO_RPI
RESET external path   = P0.18 / J10.12 / RESET
```

The firmware configures SCK, MOSI, MISO and CS as safe GPIO inputs. READY / P0.28 is configured as an output with input readback enabled.

## Build and flash proof

The Zephyr application built successfully for:

```text
decawave_dwm3001cdk/nrf52833
```

The DWM3001-CDK was flashed through J-Link using `west flash` and the Nordic `nrfutil` runner.

The Nordic tooling path was repaired by adding `C:\Tools\Nordic` to PATH and installing the `nrfutil device` command.

## RTT proof

RTT confirmed that the firmware booted as the Thin-Pod DWM3001-CDK host-interface stub and printed the intended pin map.

The READY loop was refined from a simple toggle/read to an explicit set/read sequence:

```text
set READY high
read READY
print phase=ready_high
sleep
set READY low
read READY
print phase=ready_low
sleep
```

The final RTT proof showed stable alternation:

```text
phase=ready_high set_ret=0 ready=1 cs=1
phase=ready_low  set_ret=0 ready=0 cs=1
```

This proves that the DWM3001-CDK firmware can drive and read back READY / P0.28, while CS / P0.30 remains visible as a high input.

RTT evidence file:

```text
logs/thinpod_gateway_stage8_rtt.log
```

## TP6 physical timing proof

The READY loop was slowed to make the physical signal easier to observe:

```text
HEARTBEAT_MS = 2000
```

This produced an intended READY cadence of approximately two seconds high and two seconds low.

Earlier TP6 scope captures showed faster, lower-amplitude activity that did not match the firmware cadence. Those captures are treated as exploratory only.

With the NUCLEO powered as part of the Gateway assembly, TP6 / DWM_IRQ showed slow physical activity on the handheld scope consistent with the slowed READY high/low firmware loop.

Scope evidence file:

```text
images/TP6_DWM_READY_2s_scope_2026-07-09.JPEG
```

The scope evidence supports physical activity and timing correlation on TP6. The displayed amplitude is approximately 2 Vpp rather than a clean 0 V to 3.3 V rail-level capture, so final voltage-level characterisation remains open.

## Result summary

```text
DWM3001-CDK host-interface boot stub: PASS
DWM-side J10 pin ownership: PASS
Zephyr overlay and GPIO alias resolution: PASS
READY / P0.28 set/read firmware proof: PASS
CS / P0.30 readback high: PASS
TP6 / DWM_IRQ physical activity with Gateway assembly powered: PASS
TP6 timing correlation with slowed READY loop: PASS
TP6 final rail-level 0 V to 3.3 V characterisation: PARTIAL
SPIS receive/respond behaviour: NOT YET STARTED
GET_CAPABILITIES transaction: NOT YET STARTED
```

## Engineering interpretation

The Gateway rev 0.1 DWM host-interface path is now materially stronger than a schematic-level claim. The DWM3001-CDK firmware boots, reports the intended J10 pin map, configures the host-interface pins, and drives/reads READY / P0.28.

With the Gateway assembly properly powered, TP6 / DWM_IRQ shows slow activity consistent with the firmware READY cadence. This supports proceeding toward the first SPI-peripheral host-interface proof.

The remaining electrical caution is voltage-level characterisation. The present evidence proves timing and physical activity, while final rail-level confirmation should be completed with a cleaner scope setup or multimeter check.

## Boundaries

This log makes no direct NUCLEO ownership claim over the DW3110 radio silicon.

This log does not yet claim a completed SPI peripheral transaction or a completed GET_CAPABILITIES response.

## Next steps

1. Optionally confirm TP6 voltage levels with a multimeter or cleaner scope setup while the 2000 ms loop runs.
2. Record `HEARTBEAT_MS = 2000` as a temporary physical-proof setting.
3. Return `HEARTBEAT_MS` to the desired development value before SPIS transaction work, unless the slower cadence remains useful for measurement.
4. Add SPIS peripheral configuration on the confirmed J10 SPI pins.
5. Implement only `GET_CAPABILITIES` first.
6. Build the matching NUCLEO-side SPI host probe.
7. Capture the first DWM-to-NUCLEO command/response proof.

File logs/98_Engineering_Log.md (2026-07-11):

# Engineering Log 98 — TP6 READY Rail-Level Proof After Reflow

Date: 2026-07-11<br>
Branch: gateway-dw3110-register-probe<br>
Repository: Thin-Pod-Gateway-rev-0.1

## Summary

This session followed up Engineering Log 97 by rechecking the DWM3001-CDK READY / IRQ path after reflowing the suspected J10.15 solder joint.

The focus was the physical route:

```text
DWM3001-CDK P0.28 / J10.15 / GPIO_RPI
→ Gateway TP6 / DWM_IRQ
→ NUCLEO CN15.16 / PB9
```

The result is a stronger physical proof than the earlier timing-only evidence. TP6 was observed against TP1 / GND with an approximately 0 V to 3 V waveform while the DWM3001-CDK READY stub was running. This closes the previous rail-level caveat as a bench-pass, with timing still taken from the RTT firmware log.

## Starting point

Engineering Log 97 recorded that the DWM3001-CDK host-interface stub could boot, configure the intended J10 pins, drive READY / P0.28, and read back the READY state correctly.

The open caveat was that TP6 physical observation was timing-correlated but not yet a clean rail-level 0 V to 3.3 V characterisation.

A possible dry or partially wetted solder joint was identified on the J10.15 / GPIO_RPI route. This joint was reflowed before the tests recorded here.

## Firmware state

The DWM3001-CDK host-interface stub remained the firmware source of truth for READY state.

The firmware identifies itself as:

```text
Thin-Pod DWM3001-CDK host-interface stub
stage=boot_identity_ready_toggle
board=decawave_dwm3001cdk
role=gateway_initiator backend=stub state=pre_spis
```

The pin map reported by RTT was:

```text
sck=P0.31
mosi=P0.27
miso=P0.07
cs=P0.30
ready=P0.28
reset=P0.18_external
```

The GPIO configuration completed successfully, including:

```text
HOST_READY port=gpio@50000000 pin=28 mode=output_input_inactive ret=0
```

The READY loop continued to show successful firmware readback:

```text
phase=ready_high set_ret=0 ready=1
phase=ready_low  set_ret=0 ready=0
```

RTT evidence file:

```text
logs/thinpod_gateway_tp6_ready_after_reflow_rtt_2026-07-11.log
```

## Continuity and isolation checks

Continuity checks were performed after reflow.

Confirmed continuity:

```text
CDK GND post ↔ CDK J1 -ve: PASS
CDK GND post ↔ Gateway TP1: PASS
CDK J1 -ve ↔ Gateway TP1: PASS
J10.15 / GPIO_RPI ↔ Gateway TP6: PASS
Gateway TP6 ↔ NUCLEO CN15.16 / PB9: PASS
```

Confirmed non-shorts:

```text
TP6 ↔ GND: no short detected
TP6 ↔ 3V3: no short detected
J10.15 ↔ neighbouring J10 pins: no short detected
```

These checks ruled out the main suspected open-circuit, ground-bond and adjacent-pin short faults.

## Measurement observations

Several exploratory scope/DMM observations were made while the DWM READY stub was running.

A 100 kΩ pulldown from TP6 to TP1 / GND caused the trace to flatline and was not adopted as a fix. This behaviour is recorded as an abnormal loading sensitivity observed during bench measurement.

With the DMM and scope connected between TP1 / GND and TP6, the signal resolved into a clear rail-level waveform.

Final scope evidence file:

```text
images/TP6_READY_rail_level_after_reflow_2026-07-11.jpeg
```

Final bench observation:

```text
Reference: TP1 / GND
Signal:    TP6 / DWM_IRQ / J10.15 / GPIO_RPI
Scale:     500 mV/div
Timebase:  2 s/div
Measured:  approximately 2.96–2.98 Vpp
Low:       near 0 V
High:      near 3 V
```

This confirms that the DWM READY / IRQ signal reaches the Gateway TP6 net at a valid logic-level amplitude under the observed bench conditions.

## Result summary

```text
J10.15 suspected solder issue reflowed: DONE
DWM READY firmware readback: PASS
J10.15 ↔ TP6 continuity: PASS
TP6 ↔ NUCLEO PB9 continuity: PASS
TP6 shorts to GND / 3V3: NOT DETECTED
Adjacent J10.15 shorts: NOT DETECTED
TP6 rail-level READY observation: PASS
Observed TP6 amplitude: approximately 0 V to 3 V
RTT / scope evidence pair: PASS
Direct NUCLEO-to-DW3110 DEV_ID probe: still not proven
```

## Engineering interpretation

The DWM3001-CDK READY / IRQ route should now be treated as physically proven at Gateway TP6 for bring-up purposes.

Engineering Log 97 established the DWM-side firmware proof and timing correlation. This log improves that evidence by showing TP6 reaching a valid logic-level amplitude after reflow and continuity checks.

The NUCLEO direct DW3110 register-read experiment remains a side diagnostic path. It continued to return all-zero DEV_ID reads during related testing and should not be treated as the Gateway architecture gate.

The working Gateway architecture remains:

```text
DWM3001-CDK / DWM3001C subsystem owns DW3110 radio control.
NUCLEO-N657X0-Q acts as Gateway supervisor, logger, analysis host and SPI controller.
Gateway PCB provides the modular open-hardware carrier/interface.
The DWM-to-NUCLEO host-interface contract is the next firmware milestone.
```

## Notes and caveats

The TP6 waveform showed sensitivity to measurement conditions during the investigation. Earlier unloaded scope captures were weak or distorted. The final retained capture shows a valid logic-level amplitude and should be used as the primary TP6 rail-level evidence.

RTT remains the timing source of truth for firmware READY high/low phases.

The latest RTT log showed `cs=0` during the READY proof run. This should be checked before SPIS transaction work, because CS idle/high behaviour matters for the host-interface contract.

## Next steps

1. Commit this log and the saved TP6 rail-level scope image.
2. Return `HEARTBEAT_MS` from the long measurement cadence to the normal development value before SPIS work.
3. Add a short note in the code or log history that the long READY cadence was a temporary physical-proof setting.
4. Verify CS idle behaviour on P0.30 / J10.24 / CS_RPI with the NUCLEO/Gateway assembly in the intended powered state.
5. Confirm PB9 is configured as a high-impedance input on the NUCLEO side before using TP6 / DWM_IRQ as a live interrupt/READY line.
6. Move to the first DWM-owned host-interface transaction proof.
7. Implement the smallest SPIS response first: `GET_CAPABILITIES`.
8. Build the matching NUCLEO SPI host probe for the DWM-to-NUCLEO protocol.
9. Capture and log the first valid command/response exchange:
   - NUCLEO asserts CS.
   - NUCLEO clocks request bytes over SPI5.
   - DWM3001-CDK receives the request through the confirmed J10 SPI pins.
   - DWM3001-CDK returns a valid protocol response.
   - NUCLEO validates status, sequence and CRC.

## Next milestone definition

The next meaningful firmware milestone is:

```text
DWM3001-CDK SPIS endpoint responds to a NUCLEO GET_CAPABILITIES request over the Gateway J10/SPI5 host-interface path.
```

That milestone should be treated as the next architecture-gating proof, rather than further direct NUCLEO-to-DW3110 register probing.

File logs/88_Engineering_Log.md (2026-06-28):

# 88 Engineering Log: Gateway Completion Checklist, Observability Notes, Hardware Evidence and PR Consolidation

**Date:** 28 June 2026  
**Repository:** `Pealie/Thin-Pod-Gateway-rev-0.1`  
**Final branch state:** `main`  
**Merged branch:** `gateway-rev0.1-completion-checklist`  
**Scope:** Thin-Pod Gateway rev 0.1 repository completion work, observability evaluation, hardware evidence, README presentation, engineering-log capture, pull-request merge and branch cleanup

## Summary

This weekend’s work strengthened the Thin-Pod Gateway rev 0.1 repository as a more complete, reviewable and evidence-backed open-source hardware project.

The morning work focused on the project’s completion-checklist branch, Stage-2 preparation, firmware scaffolding, validation documentation and observability evaluation. Memfault and nRF Cloud were considered as possible diagnostic and fleet-observability layers, while keeping the core Gateway rev 0.1 evidence package modular and not dependent on a proprietary cloud service.

The evening work focused on repository evidence, presentation and consolidation. Two photographs of the physical Gateway hardware were added under `images/`, referenced from `README.md`, and documented in this engineering log. The completion-checklist branch was then opened as Pull Request #2, reviewed at a high level, merged into `main`, pulled locally, and cleaned up by deleting the merged feature branch.

Taken together, the work moved the Gateway repository from a set of parallel development notes and branch-local evidence into a cleaner `main` branch containing hardware images, README evidence, firmware scaffolds, validation notes, observability notes, release-checking scripts and a dated engineering log.

## Morning work: completion checklist, Stage-2 preparation and observability evaluation

The morning work continued the `gateway-rev0.1-completion-checklist` branch and examined how Memfault and nRF Cloud might fit into the Thin-Pod Gateway project.

The important outcome was architectural clarification rather than immediate cloud implementation. Memfault and nRF Cloud were treated as possible observability and diagnostics layers, not as required dependencies for the first Gateway hardware release. This preserves the modular character of Thin-Pod: the core hardware, firmware, telemetry and evidence path should remain understandable and usable without depending on a specific proprietary service.

The work helped separate three concerns:

1. **Gateway rev 0.1 completion evidence**  
   The repository needs to show clear hardware design files, build evidence, documentation, known limits and release-readiness material.

2. **Stage-2 UWB RF proof preparation**  
   The repository gained firmware scaffolding and notes for the next verification phase, while keeping the real DW3110 driver port, RF exchange and vibration-window transfer clearly marked as future work.

3. **Device and fleet observability**  
   Memfault-style crash, log, metric and fleet-health concepts are relevant to later Gateway development, especially if Thin-Pod moves from bench prototype to deployed sensor network.

4. **Cloud integration boundaries**  
   nRF Cloud may be useful in Nordic-centred evaluation, but it should not become a hard requirement for interpreting the Gateway repository or validating the open hardware release.

Relevant recent commits included:

```text
696e6c5 Evaluate Memfault nRF Cloud observability fit
87d51ab Add Memfault nRF Cloud PR notes
1b64b26 Merge pull request #1 from Pealie/memfault-nrfcloud-evaluation
```

This gave the branch a cleaner evidence trail for why observability was considered, how it relates to the Gateway, and why it remains a bounded future-facing layer rather than an immediate rev 0.1 blocker.

## Repository files consolidated by the completion-checklist branch

The merged completion-checklist work added or consolidated a substantial set of repository files, including:

```text
.github/workflows/gateway-checks.yml
.gitignore
docs/archive/architecture/Gateway_Module_Substitution_and_EOL_Strategy.md
docs/archive/roadmap/Thin-Pod_Post-Gateway_Roadmap_Synthesis.md
docs/bringup/Gateway_rev0_1_Hardware_Bringup_Note.md
docs/firmware/NUCLEO_SPI5_Gateway_PCB_Pin_Mapping.md
docs/firmware/ThinPod_Gateway_NUCLEO_SPI5_GPIO_Probe_App_Commit_Plan.md
docs/firmware/UWB_RF_Proof_Stage2.md
docs/firmware/Zephyr_DW3110_Stage2_RF_Bringup_Plan.md
docs/observability/Thin-Pod_Memfault_nRFCloud_Evaluation.md
docs/observability/Thin-Pod_Memfault_nRFCloud_PR_Notes.md
docs/oshwa/Gateway_OSHWA_Preparation_Checklist.md
docs/protocol/ThinPod_Gateway_Telemetry_Packet_v1.md
docs/validation/Gateway_rev0_1_Validation_Log.md
firmware/gateway/uwb_initiator_stage2_rf/
firmware/gateway_probe/
firmware/node/uwb_responder_stage2_rf/
logs/88_Engineering_Log.md
samples/telemetry_packet_v1_sample.hex
scripts/check_gateway_release_artifacts.py
scripts/gateway_packet_logger.py
```

This is a meaningful repo consolidation step. It brings architecture, firmware intent, validation, telemetry protocol, observability, release checking and engineering-log evidence into the same mainline history.

## Evening work: hardware image evidence

The evening work added physical hardware evidence to the repository.

A new `images` folder was created and two Gateway photographs were added:

```text
images/Thin-Pod Gateway PCB.JPG
images/Thin-Pod Gateway and Thin-Pod node.JPG
```

The first image records the Gateway PCB as a physical assembled board. The second image places the Gateway in context with the Thin-Pod node, helping show the relationship between the sensor node and Gateway hardware.

This matters because open-source hardware repositories are stronger when they provide visible continuity between design intent, fabricated hardware and system context. The images help demonstrate that Gateway rev 0.1 is not only a schematic or KiCad exercise, but a real bench-built hardware artefact.

## README hardware evidence section

The README was updated to include a concise `Gateway hardware evidence` section. This section explains the purpose of the photographs and displays the Gateway PCB and Gateway-plus-node images directly from the repository.

The README image rendering was checked in GitHub and refined so that the images display at a controlled width rather than overwhelming the page.

The section now provides a useful front-page evidence path:

```text
Gateway hardware evidence
short explanatory paragraph
Gateway PCB image
caption
Gateway and Thin-Pod node image
caption
```

This makes the physical build visible to a reviewer, certifier, collaborator or future user arriving at the repository cold.

## Branch and commit work

The hardware images were first added to `main`.

Relevant commit:

```text
b960ddc Add Gateway PCB and node images
```

The active completion-checklist branch was then updated by merging `main` into `gateway-rev0.1-completion-checklist`.

Relevant merge commit:

```text
b54ca01 Merge branch 'main' into gateway-rev0.1-completion-checklist
```

The image evidence, README changes and this engineering log were then committed on the completion-checklist branch.

Relevant commits included:

```text
ff56e86 Reference Gateway hardware images in README
648953e Add engineering log 88 for Gateway weekend work
768fd7b Reference Gateway hardware images in README
```

The duplicate README commit message is harmless. It reflects a refinement of the README image presentation after the initial README update.

## Pull Request #2

A pull request was opened from:

```text
gateway-rev0.1-completion-checklist
```

into:

```text
main
```

The PR title was:

```text
Complete Gateway rev 0.1 checklist, RF proof scaffolds and hardware evidence
```

GitHub showed:

```text
27 commits
31 files changed
All checks have passed
No conflicts with base branch
```

The PR was then merged successfully.

Final merge commit on `main`:

```text
38aacb5 Merge pull request #2 from Pealie/gateway-rev0.1-completion-checklist
```

This merged the completion-checklist branch into `main`.

## Local main update after merge

After the GitHub merge, the local repository was switched to `main` and updated from GitHub.

Commands used:

```bat
cd C:\ThinPod\Thin-Pod-Gateway-rev-0.1

git switch main
git pull origin main

git status
git log --oneline --decorate -5
```

The pull fast-forwarded local `main` from:

```text
b960ddc
```

to:

```text
38aacb5
```

The pull brought in 31 files and 5666 insertions.

The final status confirmed:

```text
On branch main
Your branch is up to date with 'origin/main'.

nothing to commit, working tree clean
```

The recent log confirmed:

```text
38aacb5 (HEAD -> main, origin/main, origin/HEAD) Merge pull request #2 from Pealie/gateway-rev0.1-completion-checklist
768fd7b Reference Gateway hardware images in README
648953e Add engineering log 88 for Gateway weekend work
ff56e86 Reference Gateway hardware images in README
b54ca01 Merge branch 'main' into gateway-rev0.1-completion-checklist
```

## Branch cleanup

After PR #2 was merged into `main` and local `main` was updated successfully, the merged feature branch was deleted locally and remotely.

Commands used:

```bat
git branch -d gateway-rev0.1-completion-checklist
git push origin --delete gateway-rev0.1-completion-checklist
git fetch --all --prune
git branch -a
```

The local deletion succeeded:

```text
Deleted branch gateway-rev0.1-completion-checklist (was 768fd7b).
```

The remote deletion succeeded:

```text
- [deleted]         gateway-rev0.1-completion-checklist
```

The remaining branches were:

```text
* main
  stage2-uwb-rf-proof
  remotes/origin/HEAD -> origin/main
  remotes/origin/main
  remotes/origin/stage2-uwb-rf-proof
```

The final repository check showed:

```text
On branch main
Your branch is up to date with 'origin/main'.

nothing to commit, working tree clean
```

## Engineering significance

The weekend’s work matters because it improves the repository in several practical ways.

First, it gives the Gateway project a stronger public evidence trail. The images show the real hardware and make the repo more immediately understandable to someone arriving cold.

Second, it brings the completion-checklist work into `main`. That matters because the repo’s main branch now contains the documentation, scripts, firmware scaffolds, validation notes, observability notes and hardware evidence needed to support a more coherent release-readiness story.

Third, it keeps cloud observability in the right architectural place. Memfault and nRF Cloud are useful ideas, but the core Gateway repository remains modular, open and understandable without cloud lock-in.

Fourth, it improves OSHWA-readiness. Hardware images, README references, explicit design boundaries, logs, validation notes, licensing awareness and checklist documentation all contribute to a repository that is easier to review as an open-source hardware artefact.

Fifth, it leaves the repository tidy. The merged branch was deleted after successful integration, avoiding unnecessary stale branch clutter while preserving the full commit history through the PR merge.

## Final repository state

At the end of the weekend:

- `main` contains the completion-checklist work.
- Pull Request #2 has been merged and closed.
- `logs/88_Engineering_Log.md` is present on `main`.
- The Gateway hardware images are present under `images/`.
- `README.md` references the hardware images.
- The README images render correctly on GitHub.
- Memfault and nRF Cloud observability evaluation notes are present.
- Stage-2 UWB RF proof scaffolds are present.
- Gateway firmware probe scaffolding is present.
- Validation, telemetry packet and release-checking documentation are present.
- The local repository is clean.
- `origin/main` and local `main` are aligned.
- The merged `gateway-rev0.1-completion-checklist` branch has been deleted locally and remotely.
- The remaining active development branch is `stage2-uwb-rf-proof`.

## Remaining active branch

The branch list now shows:

```text
* main
  stage2-uwb-rf-proof
  remotes/origin/HEAD -> origin/main
  remotes/origin/main
  remotes/origin/stage2-uwb-rf-proof
```

This means `main` is the current clean release-facing branch, while `stage2-uwb-rf-proof` remains available for continuing the UWB RF verification path.

## Suggested next steps

The next work should proceed from the now-clean `main` branch state.

Suggested next steps are:

1. Review `main` on GitHub and confirm that the README, images, log and docs render as expected.
2. Re-check the Gateway OSHWA preparation checklist against the current repository tree.
3. Decide whether remaining work should continue on `stage2-uwb-rf-proof` or on a new, narrower branch.
4. Keep the Stage-2 RF proof work clearly separated from the Gateway rev 0.1 release boundary unless it becomes verified evidence.
5. Continue documenting real hardware bring-up, RF tests, telemetry packet tests and validation results as they occur.
6. When the Gateway rev 0.1 evidence package is judged complete, prepare a tagged hardware release.
7. Consider a future release title such as `Thin-Pod Gateway rev 0.1 – Open Hardware Release`.

## Closing note

This weekend’s work was valuable repository engineering. It did not claim completion of the full DW3110 driver port, real RF exchange, full vibration-window transfer or production telemetry pipeline. Instead, it made the Gateway repository more coherent, more evidenced and more release-ready.

The Gateway project now has a cleaner main branch, visible hardware evidence, a documented completion trail, validated merge history and an explicit separation between current rev 0.1 evidence and future Stage-2 verification. That is a solid foundation for the next phase.

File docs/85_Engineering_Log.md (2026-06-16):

# 85 Engineering Log

## Thin-Pod Gateway / Node Firmware Bring-Up: Stage-1 UWB Role Harness

**Date:** 16 June 2026  
**Project:** Thin-Pod Gateway rev 0.1 / Thin-Pod node firmware path  
**Repository:** `C:\thinpod\Thin-Pod-Gateway-rev-0.1`  
**Toolchain:** nRF Connect SDK v3.3.1, Zephyr, west v1.5.0, Zephyr SDK 0.17.0, J-Link 9.50  
**Boards:** Qorvo / Decawave DWM3001-CDK, nRF52833 target  
**Stage:** Build, flash and runtime evidence for Stage-1 Gateway initiator and node responder firmware

---

## 1. Summary

Tonight’s work established a clean Stage-1 firmware milestone for the Thin-Pod Gateway and node platform.

Both firmware roles were built successfully under nRF Connect SDK v3.3.1:

- `firmware/node/uwb_responder`
- `firmware/gateway/uwb_initiator`

Both images were flashed successfully to their intended DWM3001-CDKs using the J-Link runner. SEGGER RTT Viewer then confirmed that both boards booted and emitted role-specific structured logs.

The Gateway CDK emitted `TPGW_POLL` and `TPGW_PKT` records. The node CDK emitted `TPNODE_RESPONDER_READY` records. These logs confirm that the Stage-1 firmware harness is buildable, flashable and observable, with stable node/Gateway identity conventions and a parser-friendly packet/log format.

This remains a **stub-backend milestone**, not yet proof of live DW3110 RF exchange. Nevertheless, it is an important step because the project now has working firmware roles on the two DWM3001-CDKs, rather than merely repository scaffolding.

The most important conclusion is:

```text
Thin-Pod Gateway and node Stage-1 firmware roles now build, flash and run on
their intended DWM3001-CDKs, producing observable RTT logs with the expected
Gateway initiator and node responder packet conventions.
```

---

## 2. Hardware / firmware role mapping

The intended board mapping was preserved throughout the work:

```text
Gateway CDK 760203854 -> gateway_uwb_initiator_stage1
Node CDK    760222856 -> node_uwb_responder_stage1
```

The Gateway role uses ID:

```text
gateway_id=0x0000
role=initiator
```

The node role uses ID:

```text
node_id=0x0001
role=responder
```

The intended packet direction is therefore:

```text
Node    0x0001 -> Gateway 0x0000
Gateway 0x0000 -> Node    0x0001
```

At this stage, the firmware uses a stub backend. The output simulates or stages the data path and packet contract rather than proving real UWB RF transport.

---

## 3. Problem: nRF Connect SDK terminal would not start

The original obstacle was that the nRF Connect SDK v3.3.1 terminal could not be started. Ordinary PowerShell was therefore used instead.

Initial checks showed that `west` and `ninja` were not visible in the standard PowerShell environment:

```powershell
west --version
cmake --version
ninja --version
```

The visible results were:

```text
west : The term 'west' is not recognized...
cmake version 3.25.0
ninja : The term 'ninja' is not recognized...
```

A search for the Nordic toolchain found `west.exe` here:

```powershell
Get-ChildItem C:\ncs\toolchains -Recurse -Filter west.exe -ErrorAction SilentlyContinue |
  Select-Object FullName
```

Result:

```text
C:\ncs\toolchains\936afb6332\opt\bin\Scripts\west.exe
```

The toolchain paths were then added manually for the current PowerShell session.

---

## 4. Manual PowerShell environment setup

The following commands made `west` and `ninja` visible:

```powershell
$tc = "C:\ncs\toolchains\936afb6332\opt\bin"
$env:Path = "$tc;$tc\Scripts;$env:Path"

west --version
ninja --version
```

Confirmed versions:

```text
West version: v1.5.0
ninja 1.13.2
```

The Zephyr SDK variables were then set:

```powershell
$env:ZEPHYR_TOOLCHAIN_VARIANT = "zephyr"
$env:ZEPHYR_SDK_INSTALL_DIR = "C:\ncs\toolchains\936afb6332\opt\zephyr-sdk"
```

This successfully reproduced the essential Nordic build environment without needing the SDK terminal shortcut.

---

## 5. Build: Thin-Pod node UWB responder Stage 1

The node responder firmware was built with:

```powershell
cd C:\ncs\v3.3.1

west build -b decawave_dwm3001cdk -p always `
  -d C:\ncs\v3.3.1\build_node_uwb_responder_stage1 `
  C:\thinpod\Thin-Pod-Gateway-rev-0.1\firmware\node\uwb_responder
```

The build identified the board as:

```text
Board: decawave_dwm3001cdk, qualifiers: nrf52833
```

The application was correctly identified as:

```text
Application: C:/ThinPod/Thin-Pod-Gateway-rev-0.1/firmware/node/uwb_responder
```

The build completed successfully:

```text
[164/164] Linking C executable zephyr\zephyr.elf

Memory region         Used Size  Region Size  %age Used
           FLASH:       21104 B       512 KB      4.03%
             RAM:        5696 B       128 KB      4.35%

[10/10] Generating ../merged.hex
```

The output image is:

```text
C:\ncs\v3.3.1\build_node_uwb_responder_stage1\merged.hex
```

The partition-manager warning appeared during configuration, but this was only a deprecation warning and did not prevent the build.

---
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

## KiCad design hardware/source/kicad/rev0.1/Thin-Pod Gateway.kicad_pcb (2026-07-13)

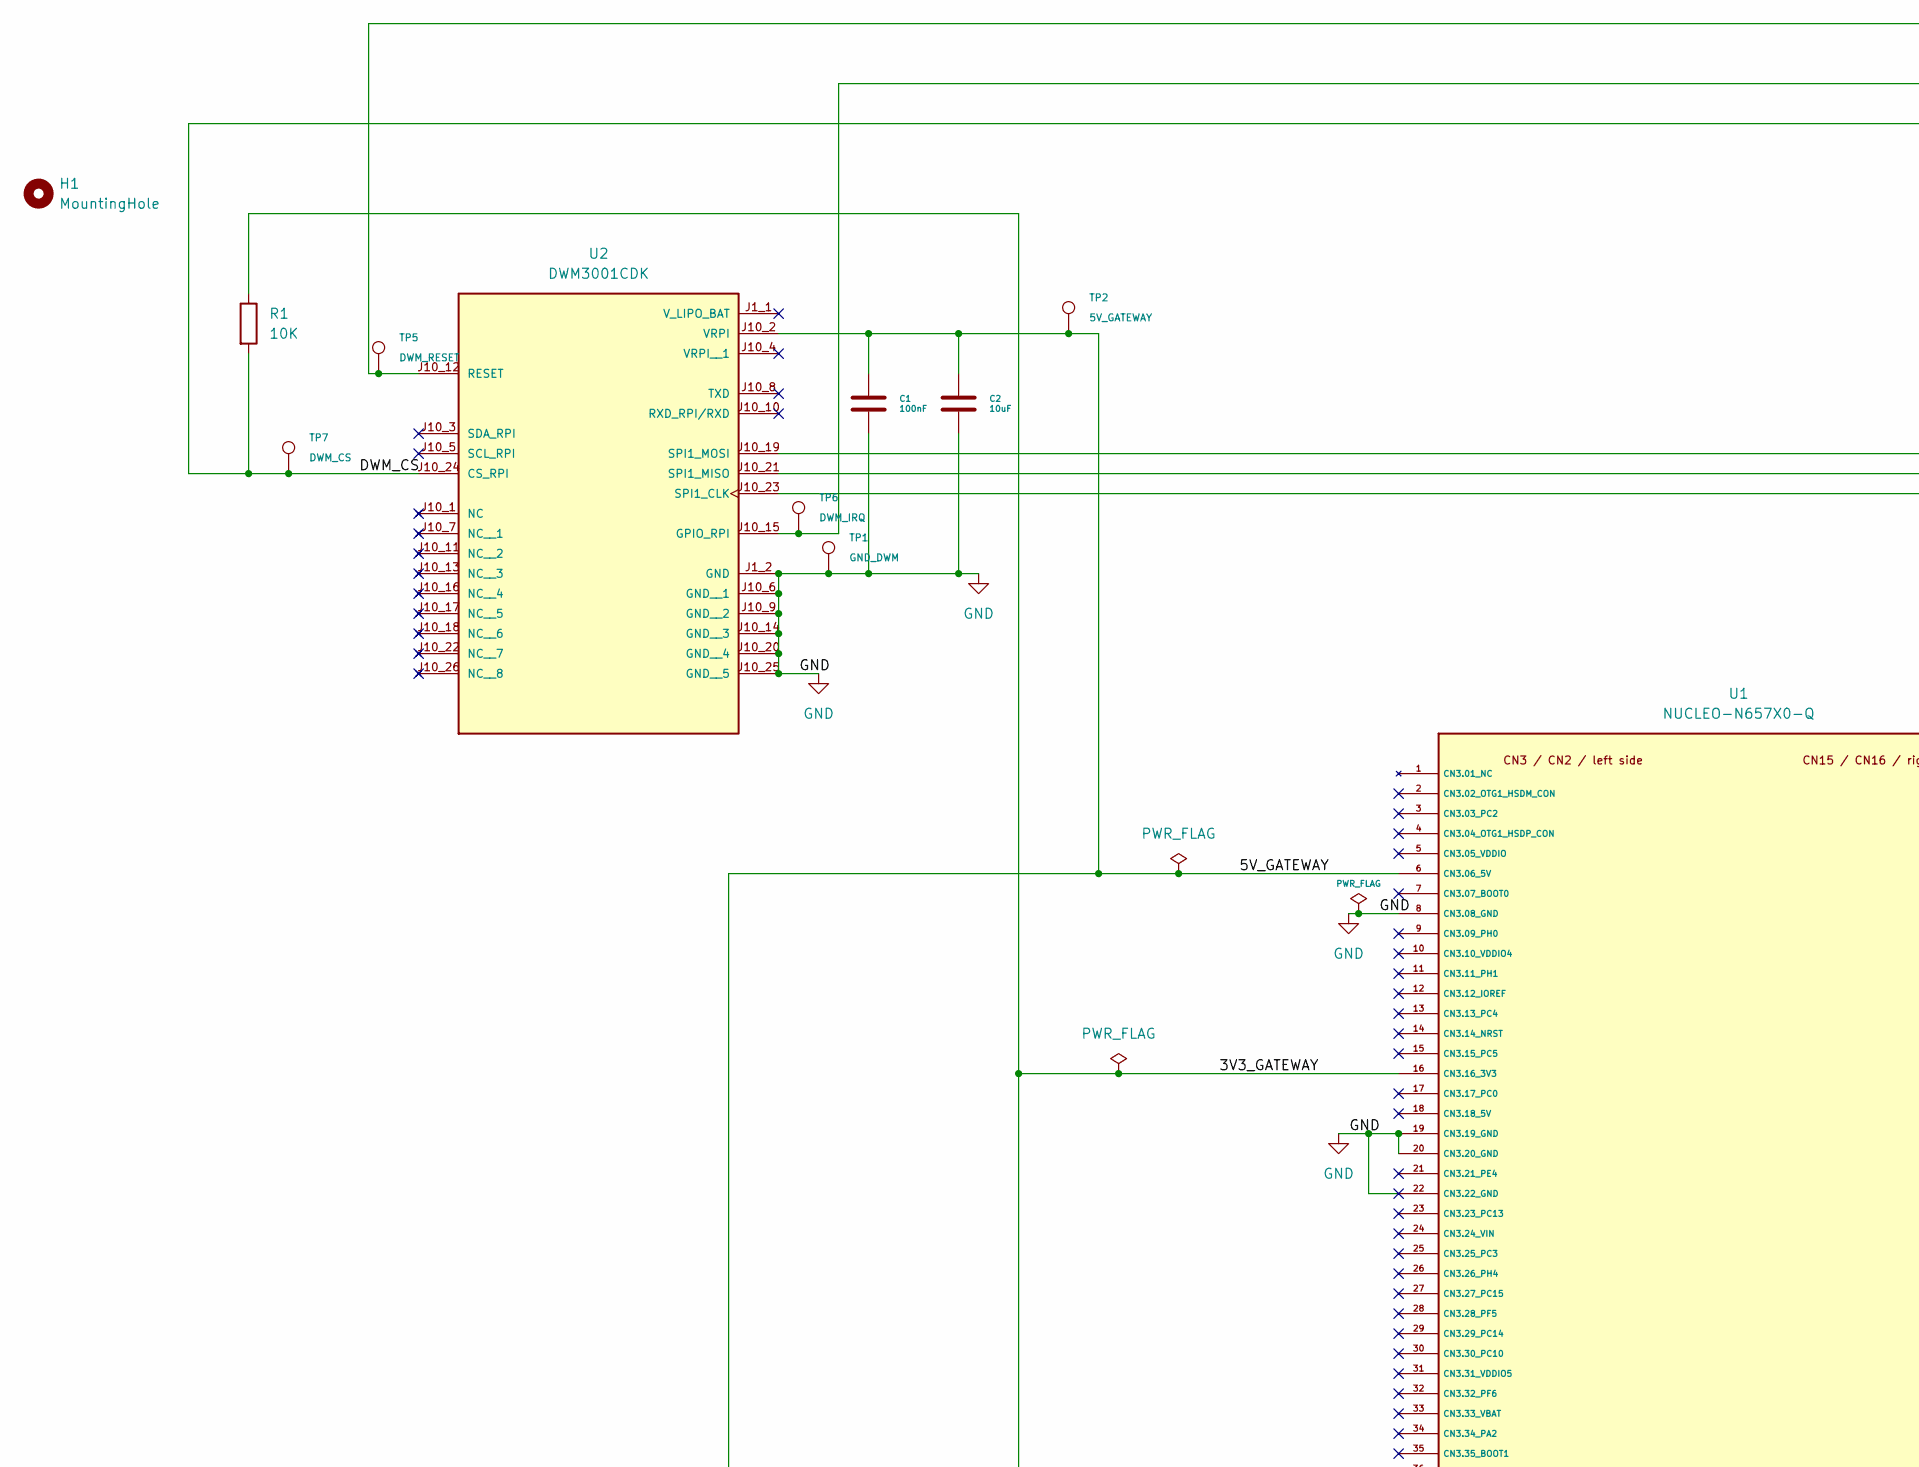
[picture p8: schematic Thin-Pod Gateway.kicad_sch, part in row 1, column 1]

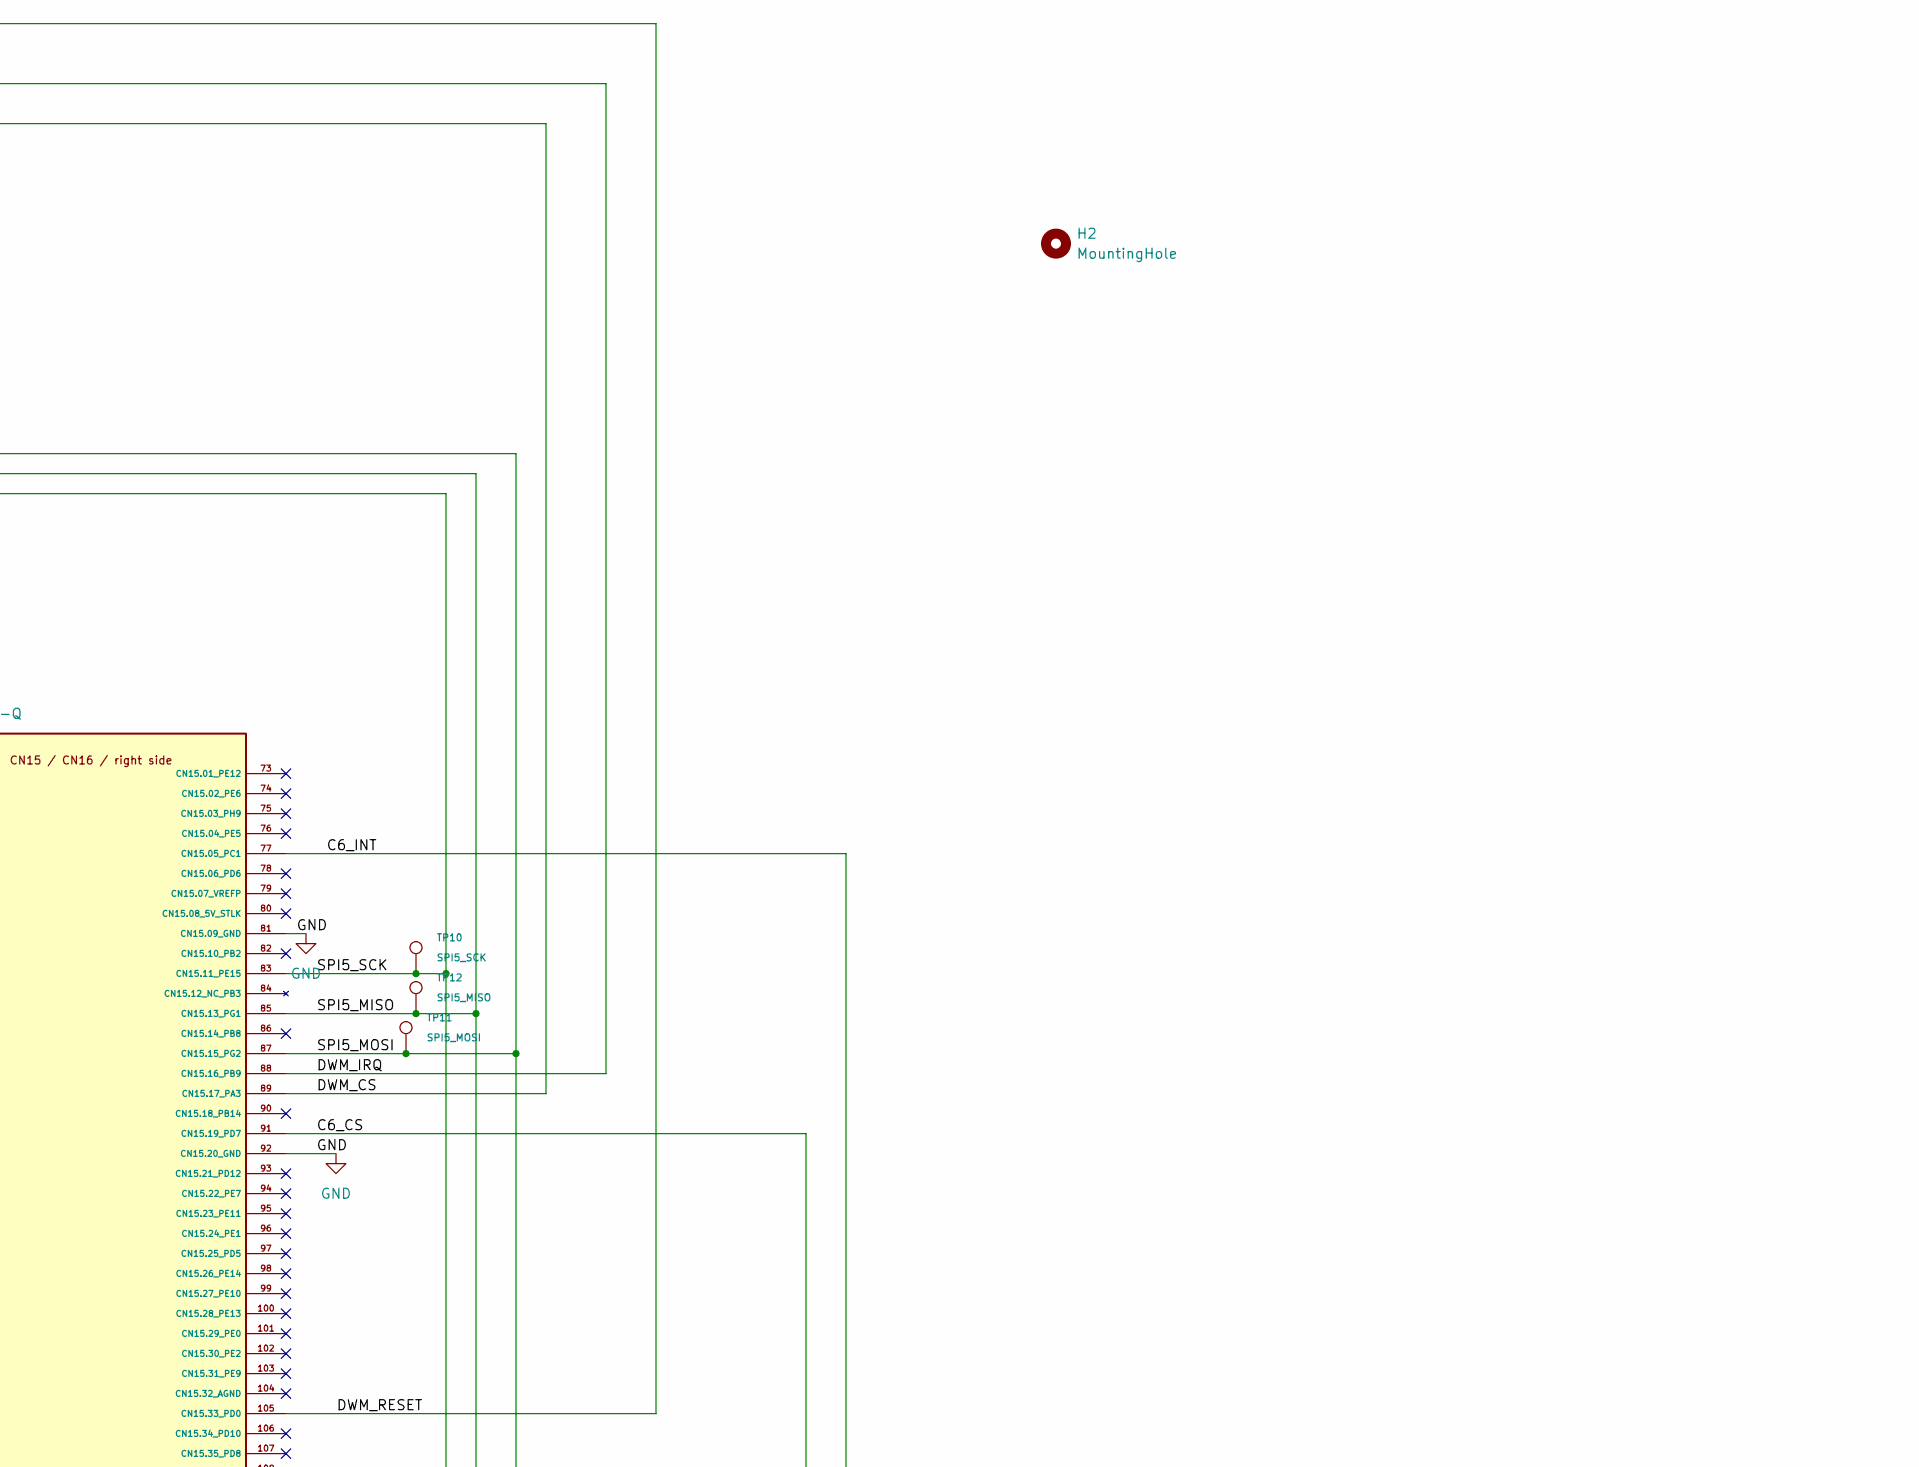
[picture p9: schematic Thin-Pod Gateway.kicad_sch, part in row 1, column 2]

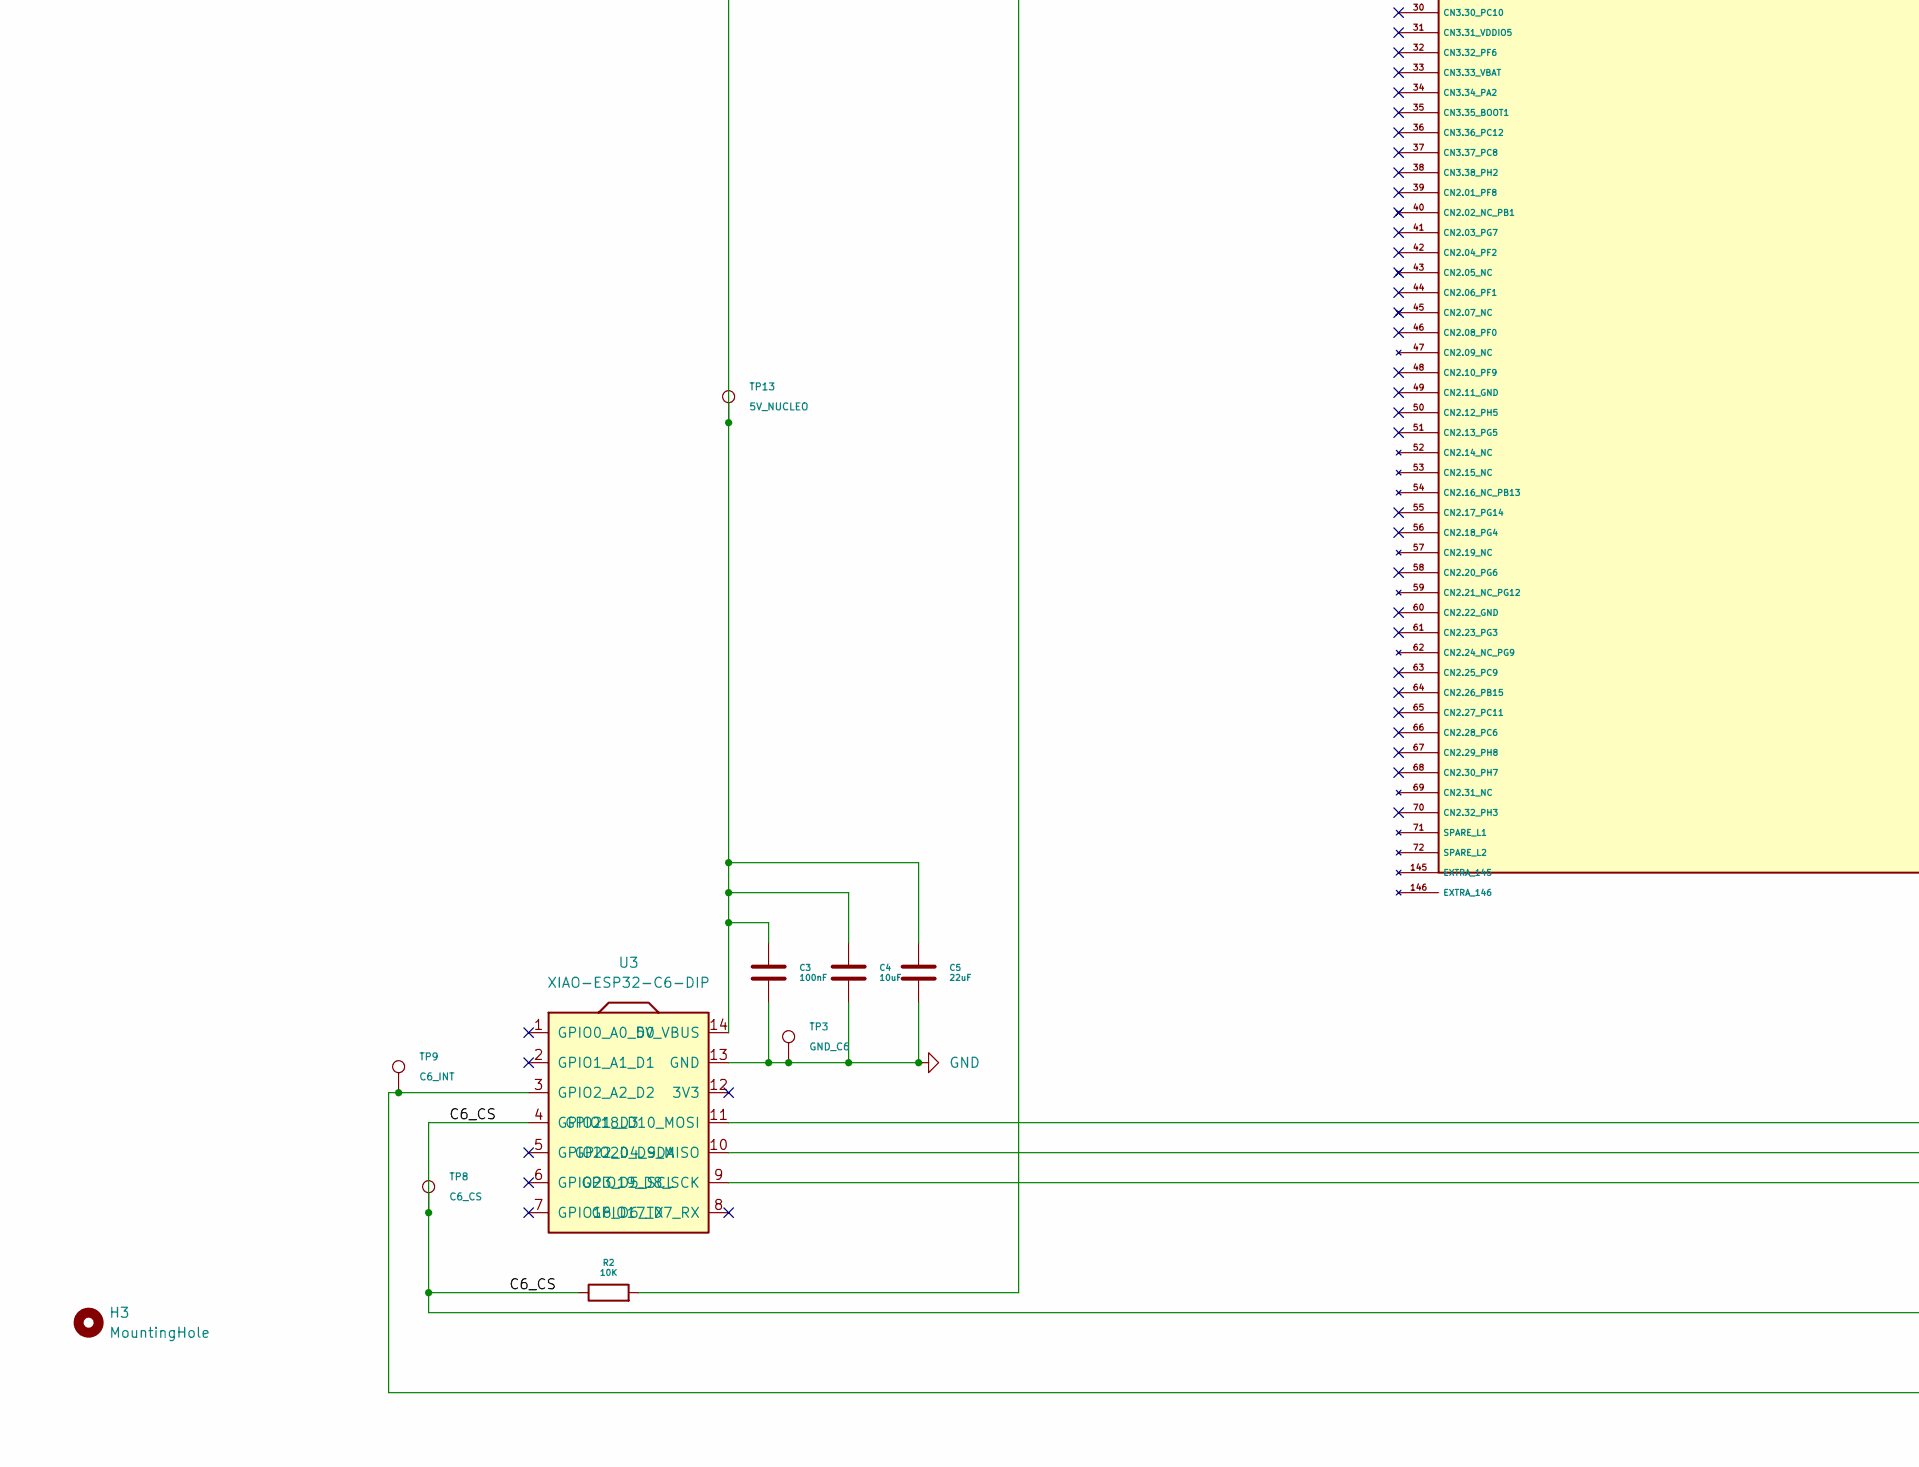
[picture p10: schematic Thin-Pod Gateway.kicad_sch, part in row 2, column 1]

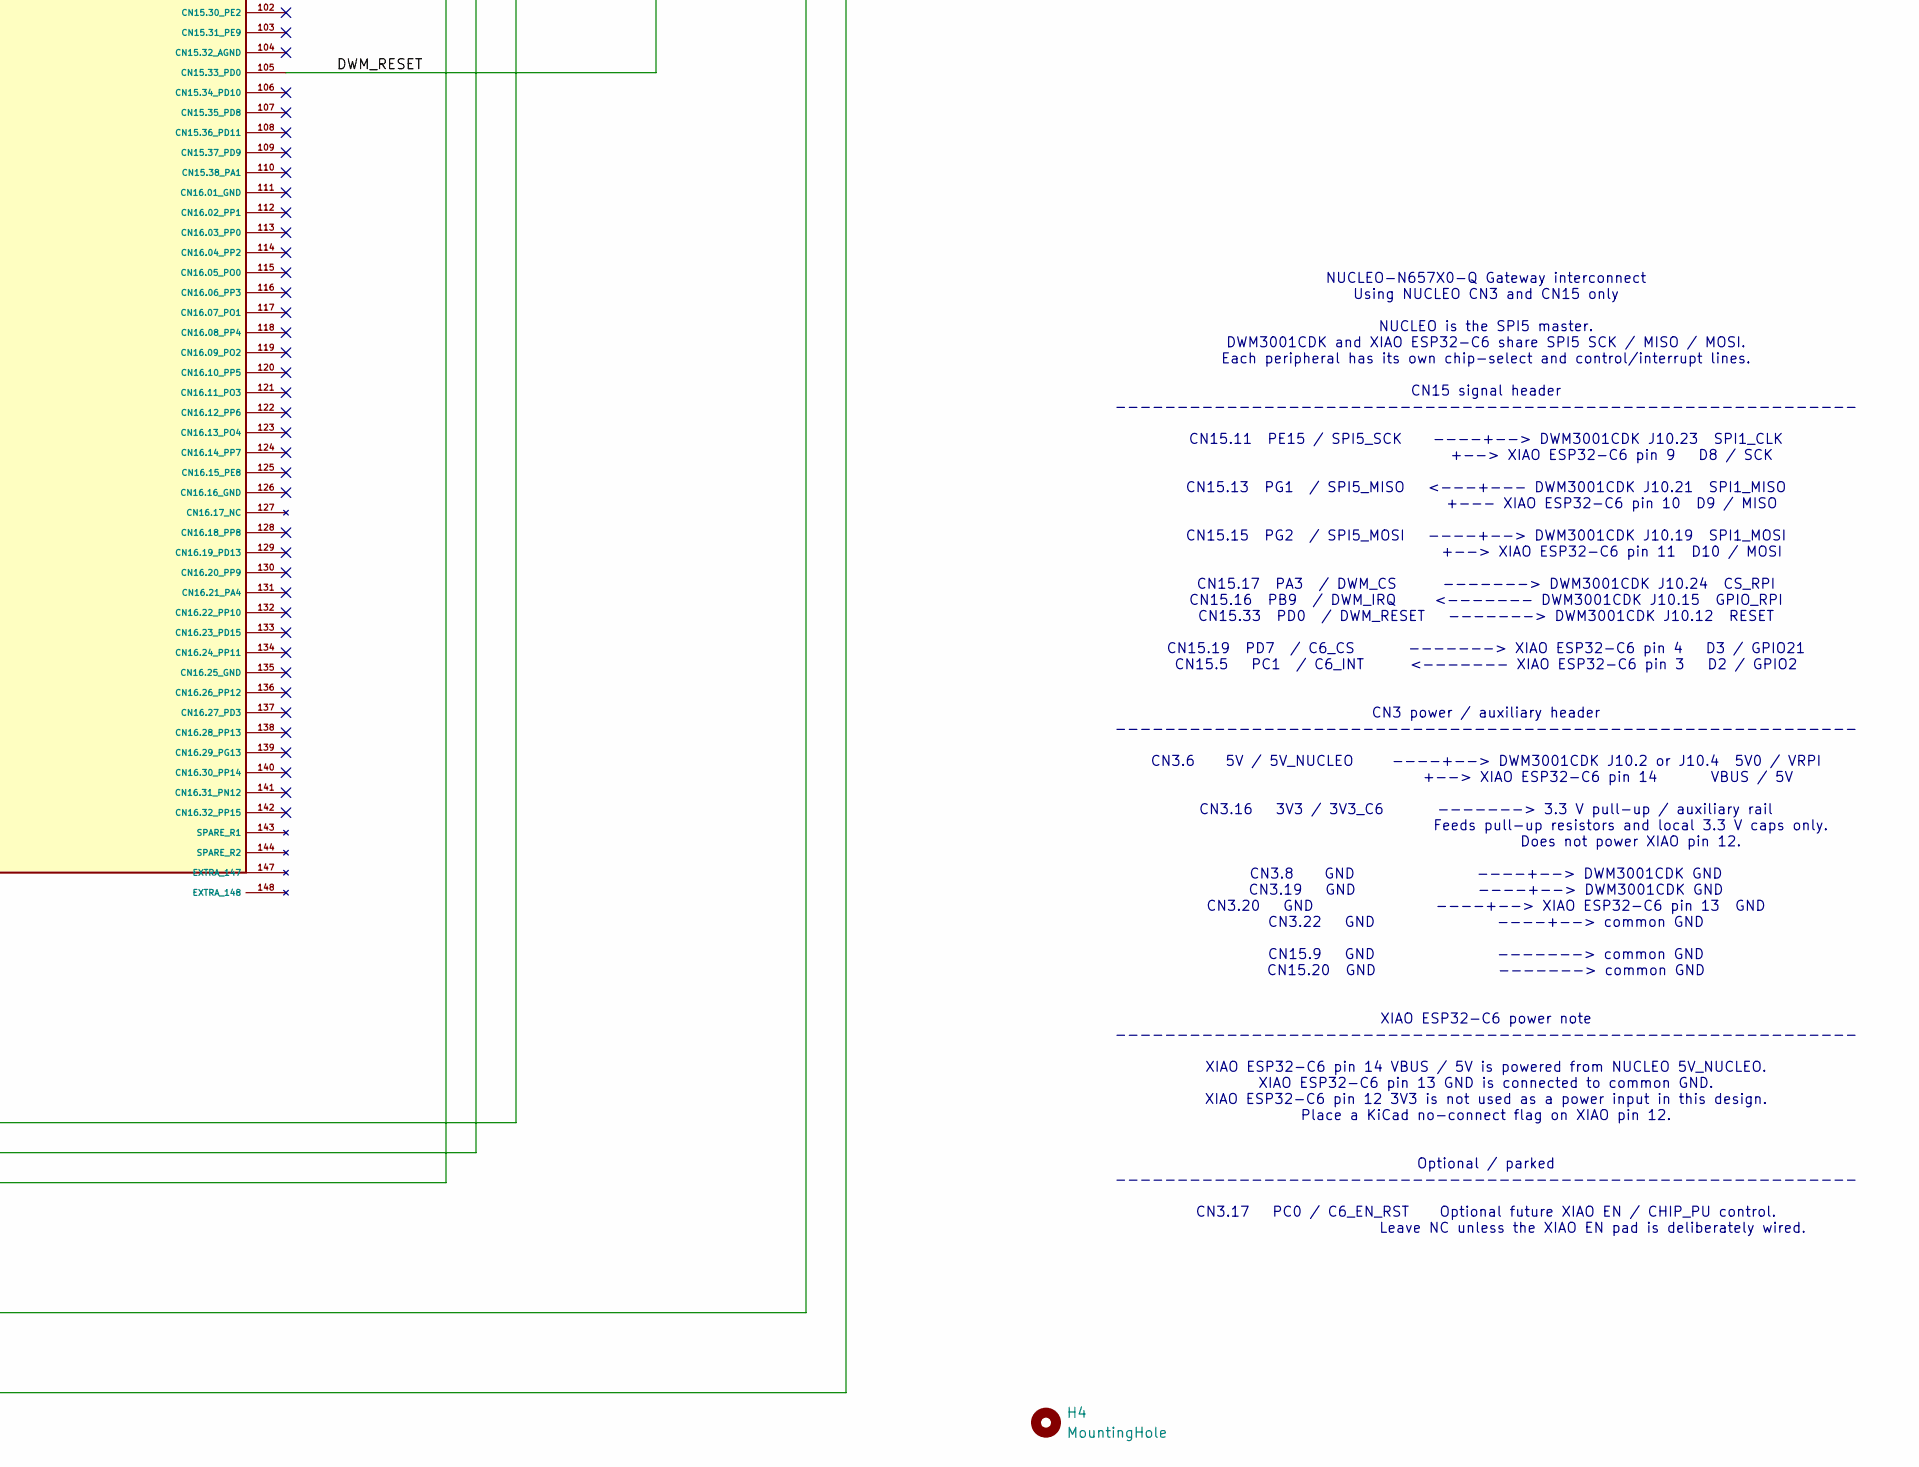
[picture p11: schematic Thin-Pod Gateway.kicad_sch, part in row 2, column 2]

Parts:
C1, C3: 100nF; C_Disc_D5.0mm_W2.5mm_P5.00mm
C2, C4: 10uF; C_Disc_D5.0mm_W2.5mm_P5.00mm
C5: 22uF; C_Disc_D5.0mm_W2.5mm_P5.00mm
H1, H2, H3, H4: MountingHole; MountingHole_3.2mm_M3
R1, R2: 10K; R_Axial_DIN0207_L6.3mm_D2.5mm_P7.62mm_Horizontal
TP1: GND_DWM; TestPoint_THTPad_1.5x1.5mm_Drill0.7mm
TP2: 5V_GATEWAY; TestPoint_THTPad_1.5x1.5mm_Drill0.7mm
TP3: GND_C6; TestPoint_THTPad_1.5x1.5mm_Drill0.7mm
TP5: DWM_RESET; TestPoint_THTPad_1.5x1.5mm_Drill0.7mm
TP6: DWM_IRQ; TestPoint_THTPad_1.5x1.5mm_Drill0.7mm
TP7: DWM_CS; TestPoint_THTPad_1.5x1.5mm_Drill0.7mm
TP8: C6_CS; TestPoint_THTPad_1.5x1.5mm_Drill0.7mm
TP9: C6_INT; TestPoint_THTPad_1.5x1.5mm_Drill0.7mm
TP10: SPI5_SCK; TestPoint_THTPad_2.0x2.0mm_Drill1.0mm
TP11: SPI5_MOSI; TestPoint_THTPad_2.0x2.0mm_Drill1.0mm
TP12: SPI5_MISO; TestPoint_THTPad_2.0x2.0mm_Drill1.0mm
TP13: 5V_NUCLEO; TestPoint_THTPad_1.5x1.5mm_Drill0.7mm
U1: NUCLEO-N657X0-Q; NUCLEO-N657X0-Q_Nucleo144_STMorpho_STLink_MountingHoles
U2: DWM3001CDK; MODULE_DWM3001CDK; PARTREV B
U3: XIAO-ESP32-C6-DIP

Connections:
/3V3_GATEWAY: R1.1, R2.2, U1.16 (CN3.16_3V3); also elsewhere on the board
/5V_GATEWAY: C1.1, C2.1, C3.1, C4.1, C5.1, TP2.1 (1_1), TP13.1 (1_1), U1.6 (CN3.06_5V), U2.J10_2 (VRPI), U3.14 (5V_VBUS)
/C6_CS: R2.1, TP8.1 (1_1), U1.91 (CN15.19_PD7), U3.4 (GPIO21_D3)
/C6_INT: TP9.1 (1_1), U1.77 (CN15.05_PC1), U3.3 (GPIO2_A2_D2)
/DWM_CS: R1.2, TP7.1 (1_1), U1.89 (CN15.17_PA3), U2.J10_24 (CS_RPI)
/DWM_IRQ: TP6.1 (1_1), U1.88 (CN15.16_PB9), U2.J10_15 (GPIO_RPI)
/DWM_RESET: TP5.1 (1_1), U1.105 (CN15.33_PD0), U2.J10_12 (RESET)
/SPI5_MISO: TP12.1 (1_1), U1.85 (CN15.13_PG1), U2.J10_21 (SPI1_MISO), U3.10 (GPIO20_D9_MISO)
/SPI5_MOSI: TP11.1 (1_1), U1.87 (CN15.15_PG2), U2.J10_19 (SPI1_MOSI), U3.11 (GPIO18_D10_MOSI)
/SPI5_SCK: TP10.1 (1_1), U1.83 (CN15.11_PE15), U2.J10_23 (SPI1_CLK), U3.9 (GPIO19_D8_SCK)
GND: C1.2, C2.2, C3.2, C4.2, C5.2, TP1.1 (1_1), TP3.1 (1_1), U1.1 (CN3.01_NC), U1.2 (CN3.02_OTG1_HSDM_CON), U1.8 (CN3.08_GND), U1.19 (CN3.19_GND), U1.20 (CN3.20_GND), U1.22 (CN3.22_GND), U1.71 (SPARE_L1), U1.72 (SPARE_L2), U1.73 (CN15.01_PE12), U1.74 (CN15.02_PE6), U1.81 (CN15.09_GND), U1.92 (CN15.20_GND), U1.143 (SPARE_R1), U1.144 (SPARE_R2), U2.J1_2 (GND), U2.J10_6 (GND__1), U2.J10_9 (GND__2), U2.J10_14 (GND__3), U2.J10_20 (GND__4), U2.J10_25 (GND__5), U3.13 (GND)

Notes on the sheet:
NUCLEO-N657X0-Q Gateway interconnect Using NUCLEO CN3 and CN15 only NUCLEO is the SPI5 master. DWM3001CDK and XIAO ESP32-C6 share SPI5 SCK / MISO / MOSI. Each peripheral has its own chip-select and control/interrupt lines. CN15 signal header ---------------------------------------------------------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

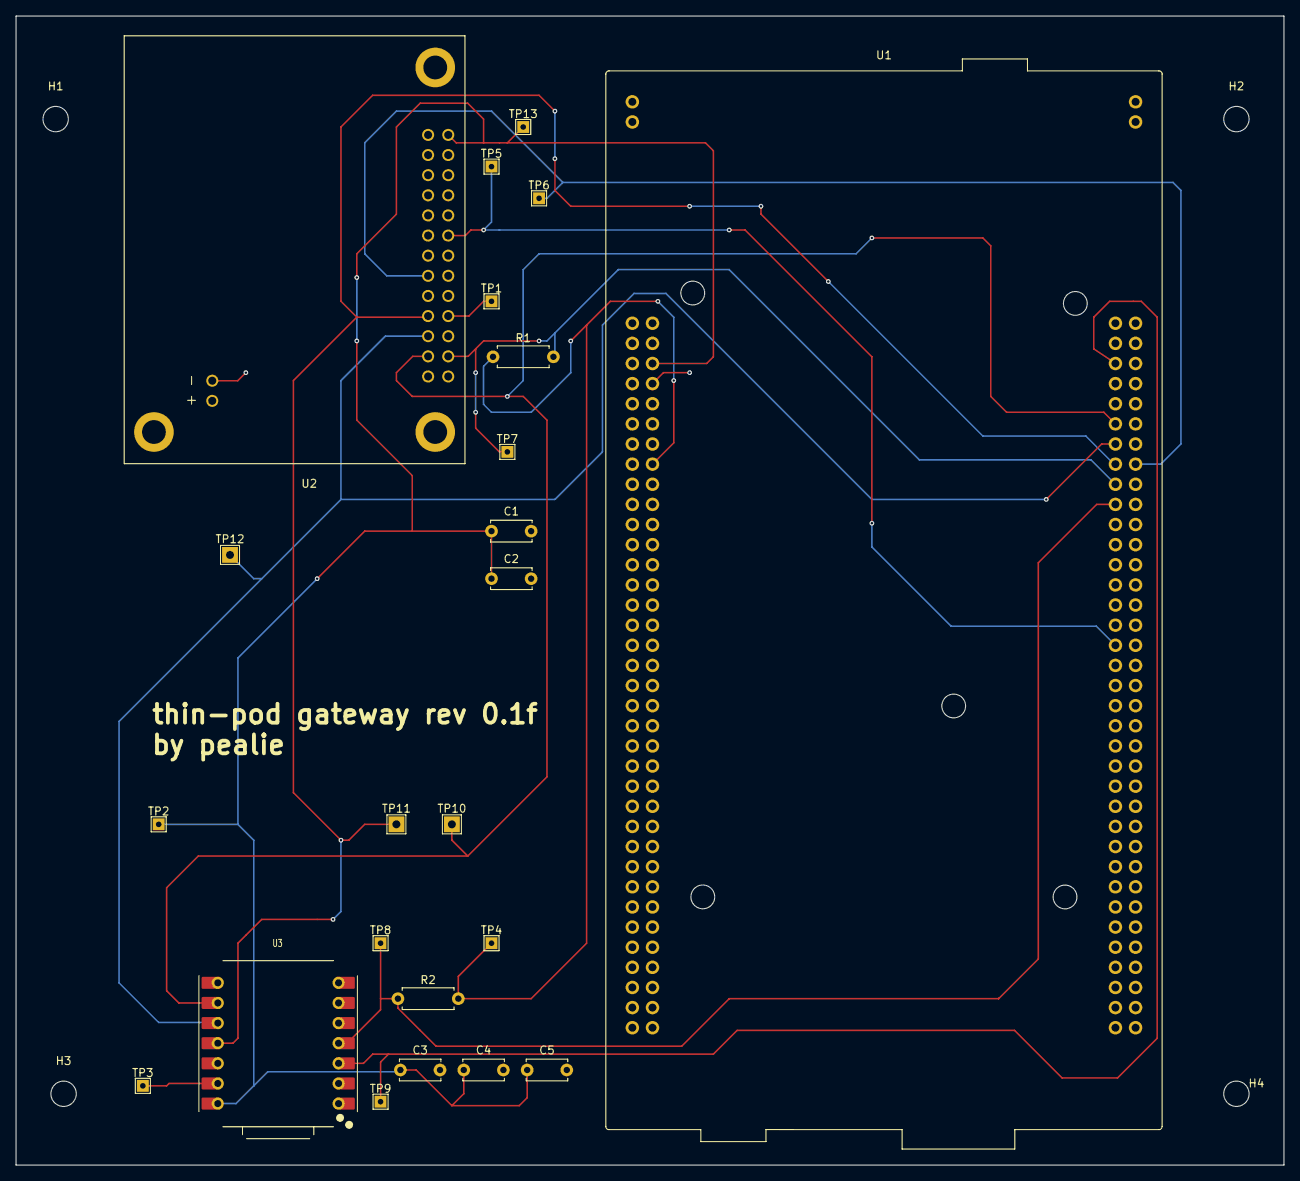
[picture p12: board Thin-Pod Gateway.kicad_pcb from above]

Board: 2 copper layers, 160.0 x 145.0 mm, 27 parts (0 on the bottom side), 11 nets.

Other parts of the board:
TP4: 3V3_GATEWAY; TestPoint_THTPad_1.5x1.5mm_Drill0.7mm

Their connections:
/3V3_GATEWAY: TP4.1 (1_1); also elsewhere on the board

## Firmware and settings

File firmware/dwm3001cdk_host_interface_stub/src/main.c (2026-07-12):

#include <errno.h>
#include <stddef.h>
#include <stdint.h>
#include <string.h>

#include <zephyr/device.h>
#include <zephyr/drivers/gpio.h>
#include <zephyr/drivers/spi.h>
#include <zephyr/kernel.h>
#include <zephyr/sys/printk.h>

#include "tphip.h"

#if !DT_NODE_HAS_STATUS(DT_NODELABEL(spi2), okay)
#error "spi2 must be enabled as the DWM host-interface SPIS endpoint"
#endif

#if !DT_NODE_EXISTS(DT_ALIAS(tphost_ready))
#error "Missing devicetree alias tphost-ready"
#endif

#define SPIS_FREQUENCY_HZ 1000000U
#define GUARD_PRE 0x13579BDFu
#define GUARD_POST 0x2468ACE0u

struct guarded_request_buffer {
    uint32_t pre_guard;
    uint8_t bytes[TPHIP_REQUEST_TRANSACTION_LEN];
    uint32_t post_guard;
};

struct guarded_response_buffer {
    uint32_t pre_guard;
    uint8_t bytes[TPHIP_RESPONSE_TRANSACTION_LEN];
    uint32_t post_guard;
};

static const struct device *const spis_dev = DEVICE_DT_GET(DT_NODELABEL(spi2));
static const struct gpio_dt_spec host_ready =
    GPIO_DT_SPEC_GET(DT_ALIAS(tphost_ready), gpios);

static struct guarded_request_buffer request_rx;
static struct guarded_request_buffer request_idle_tx;
static struct guarded_response_buffer response_tx;
static struct guarded_response_buffer response_discard_rx;

static volatile int response_result;
K_SEM_DEFINE(response_done, 0, 1);

static const struct spi_config spis_config = {
    .frequency = SPIS_FREQUENCY_HZ,
    .operation = SPI_OP_MODE_SLAVE |
                 SPI_WORD_SET(8) |
                 SPI_TRANSFER_MSB,
    .slave = 0,
};

static void initialise_guards(void)
{
    request_rx.pre_guard = GUARD_PRE;
    request_rx.post_guard = GUARD_POST;
    request_idle_tx.pre_guard = GUARD_PRE;
    request_idle_tx.post_guard = GUARD_POST;
    response_tx.pre_guard = GUARD_PRE;
    response_tx.post_guard = GUARD_POST;
    response_discard_rx.pre_guard = GUARD_PRE;
    response_discard_rx.post_guard = GUARD_POST;
}

static int guards_ok(void)
{
    return request_rx.pre_guard == GUARD_PRE &&
           request_rx.post_guard == GUARD_POST &&
           request_idle_tx.pre_guard == GUARD_PRE &&
           request_idle_tx.post_guard == GUARD_POST &&
           response_tx.pre_guard == GUARD_PRE &&
           response_tx.post_guard == GUARD_POST &&
           response_discard_rx.pre_guard == GUARD_PRE &&
           response_discard_rx.post_guard == GUARD_POST;
}

static void print_bytes(const char *label, const uint8_t *data, size_t len)
{
    size_t i;

    printk("%s", label);
    for (i = 0u; i < len; i++) {
        printk("%02x", data[i]);
        if ((i + 1u) < len) {
            printk(" ");
        }
    }
    printk("\n");
}

static void response_complete_callback(
    const struct device *dev,
    int result,
    void *userdata)
{
    ARG_UNUSED(dev);
    ARG_UNUSED(userdata);

    response_result = result;
    k_sem_give(&response_done);
}

static int receive_request(void)
{
    struct spi_buf tx_buffer = {
        .buf = request_idle_tx.bytes,
        .len = sizeof(request_idle_tx.bytes),
    };
    struct spi_buf rx_buffer = {
        .buf = request_rx.bytes,
        .len = sizeof(request_rx.bytes),
    };
    const struct spi_buf_set tx_set = {
        .buffers = &tx_buffer,
        .count = 1,
    };
    const struct spi_buf_set rx_set = {
        .buffers = &rx_buffer,
        .count = 1,
    };
    int ret;

    memset(request_rx.bytes, 0, sizeof(request_rx.bytes));
    memset(request_idle_tx.bytes, 0xff, sizeof(request_idle_tx.bytes));

    printk("tphip_dwm request_armed len=%u\n",
           (unsigned int)sizeof(request_rx.bytes));

    ret = spi_transceive(spis_dev, &spis_config, &tx_set, &rx_set);
    if (ret < 0) {
        printk("tphip_dwm request_transfer_error ret=%d\n", ret);
        return ret;
    }

    if (ret != TPHIP_REQUEST_TRANSACTION_LEN) {
        printk("tphip_dwm request_short expected=%u actual=%d\n",
               TPHIP_REQUEST_TRANSACTION_LEN,
               ret);
        return -EMSGSIZE;
    }

    return 0;
}

static int send_response(void)
{
    struct spi_buf tx_buffer = {
        .buf = response_tx.bytes,
        .len = sizeof(response_tx.bytes),
    };
    struct spi_buf rx_buffer = {
        .buf = response_discard_rx.bytes,
        .len = sizeof(response_discard_rx.bytes),
    };
    const struct spi_buf_set tx_set = {
        .buffers = &tx_buffer,
        .count = 1,
    };
    const struct spi_buf_set rx_set = {
        .buffers = &rx_buffer,
        .count = 1,
    };
    int ret;

    memset(response_discard_rx.bytes, 0, sizeof(response_discard_rx.bytes));
    response_result = -EINPROGRESS;
    k_sem_reset(&response_done);

    ret = spi_transceive_cb(
        spis_dev,
        &spis_config,
        &tx_set,
        &rx_set,
        response_complete_callback,
        NULL);
    if (ret < 0) {
        printk("tphip_dwm response_arm_error ret=%d\n", ret);
        return ret;
    }

    ret = gpio_pin_set_dt(&host_ready, 1);
    if (ret != 0) {
        printk("tphip_dwm ready_assert_error ret=%d\n", ret);
        return ret;
    }

    /*
     * Supported bring-up diagnostic: confirm that the asserted READY output
     * is also sensed at the expected physical logic level.
     */
    k_busy_wait(10);
    {
        int ready_physical = gpio_pin_get_dt(&host_ready);

        printk("tphip_dwm ready_set_ret=%d ready_physical=%d\n",
               ret,
               ready_physical);
    }

    printk("tphip_dwm ready=1 response_armed len=%u\n",
           TPHIP_RESPONSE_TRANSACTION_LEN);

    ret = k_sem_take(&response_done, K_FOREVER);
    (void)gpio_pin_set_dt(&host_ready, 0);
    printk("tphip_dwm ready=0 response_callback_result=%d sem_ret=%d\n",
           response_result,
           ret);

    if (ret != 0) {
        return ret;
    }

    if (response_result != TPHIP_RESPONSE_TRANSACTION_LEN) {
        return response_result < 0 ? response_result : -EMSGSIZE;
    }

    return 0;
}

int main(void)
{
    struct tphip_capabilities capabilities;
    uint32_t transaction_count = 0u;
    int ret;

    printk("\nThin-Pod DWM3001-CDK TPHIP SPIS endpoint\n");
    printk("board=decawave_dwm3001cdk role=gateway_initiator backend=stub\n");
    printk("interface=spi2 mode=0 request_len=%u response_len=%u\n",
           TPHIP_REQUEST_TRANSACTION_LEN,
           TPHIP_RESPONSE_TRANSACTION_LEN);
    printk("pin_map sck=P0.31 copi=P0.27 cipo=P0.07 cs=P0.30 ready=P0.28\n");
    printk("build_id=0x%08x\n", TPHIP_INTERFACE_BUILD_ID);

    if (!device_is_ready(spis_dev)) {
        printk("ERROR: spi2 SPIS device is not ready\n");
        return -ENODEV;
    }

    if (!gpio_is_ready_dt(&host_ready)) {
        printk("ERROR: HOST_READY GPIO is not ready\n");
        return -ENODEV;
    }

    /*
     * Input sensing is enabled solely to read back the READY level driven by
     * this bring-up endpoint. Protocol flow does not depend on the readback.
     */
    ret = gpio_pin_configure_dt(&host_ready, GPIO_INPUT | GPIO_OUTPUT_INACTIVE);
    if (ret != 0) {
        printk("ERROR: HOST_READY configure ret=%d\n", ret);
        return ret;
    }

    initialise_guards();
    tphip_default_capabilities(&capabilities);

    while (1) {
        struct tphip_request_view request;
        enum tphip_validation_result validation;
        enum tphip_status status;
        uint8_t request_opcode;
        uint16_t sequence;
        size_t logical_response_len;

        ret = receive_request();
        if (ret != 0) {
            k_msleep(10);
            continue;
        }

        transaction_count++;
        request_opcode = request_rx.bytes[TPHIP_OFFSET_OPCODE];
        sequence = (uint16_t)request_rx.bytes[TPHIP_OFFSET_SEQUENCE] |
                   ((uint16_t)request_rx.bytes[TPHIP_OFFSET_SEQUENCE + 1u] << 8);

        validation = tphip_validate_request(
            request_rx.bytes,
            sizeof(request_rx.bytes),
            &request);
        status = tphip_status_from_validation(validation);

        printk("tphip_dwm request_rx count=%u sequence=%u opcode=0x%02x validation=%s status=%s guard=%s\n",
               (unsigned int)transaction_count,
               (unsigned int)sequence,
               (unsigned int)request_opcode,
               tphip_validation_name(validation),
               tphip_status_name(status),
               guards_ok() ? "OK" : "FAIL");
        print_bytes("request=", request_rx.bytes, sizeof(request_rx.bytes));

        if (!guards_ok()) {
            status = TPHIP_STATUS_INTERNAL_ERROR;
        }

        logical_response_len = tphip_build_response(
            response_tx.bytes,
            request_opcode,
            sequence,
            status,
            &capabilities);

        printk("tphip_dwm response_ready sequence=%u opcode=0x%02x status=%s logical_len=%u physical_len=%u\n",
               (unsigned int)sequence,
               (unsigned int)response_tx.bytes[TPHIP_OFFSET_OPCODE],
               tphip_status_name(status),
               (unsigned int)logical_response_len,
               TPHIP_RESPONSE_TRANSACTION_LEN);
        print_bytes("response=", response_tx.bytes, sizeof(response_tx.bytes));

        ret = send_response();
        printk("tphip_dwm response_complete ret=%d guard=%s\n",
               ret,
               guards_ok() ? "OK" : "FAIL");

        if (!guards_ok()) {
            printk("FATAL: buffer guard failure\n");
            return -EFAULT;
        }
    }

    return 0;
}

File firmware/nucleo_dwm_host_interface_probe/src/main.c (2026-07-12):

#include <errno.h>
#include <stddef.h>
#include <stdint.h>
#include <string.h>

#include <zephyr/device.h>
#include <zephyr/drivers/gpio.h>
#include <zephyr/drivers/spi.h>
#include <zephyr/kernel.h>
#include <zephyr/sys/byteorder.h>
#include <zephyr/sys/printk.h>

#include "tphip.h"

#define SPI5_FREQUENCY_HZ 1000000U
#define CS_SETUP_US 10U
#define CS_HOLD_US 10U
#define RESET_LOW_MS 10U
#define RESET_SETTLE_MS 1000U
#define READY_TIMEOUT_MS 250U
#define INTER_TRANSACTION_MS 50U
#define VALID_EXCHANGE_COUNT 10U

#define GUARD_PRE 0x13579BDFu
#define GUARD_POST 0x2468ACE0u

struct guarded_request_buffer {
    uint32_t pre_guard;
    uint8_t bytes[TPHIP_REQUEST_TRANSACTION_LEN];
    uint32_t post_guard;
};

struct guarded_response_buffer {
    uint32_t pre_guard;
    uint8_t bytes[TPHIP_RESPONSE_TRANSACTION_LEN];
    uint32_t post_guard;
};

static const struct device *const spi5_dev = DEVICE_DT_GET(DT_NODELABEL(spi5));
static const struct gpio_dt_spec dwm_reset =
    GPIO_DT_SPEC_GET(DT_ALIAS(dwm_reset), gpios);
static const struct gpio_dt_spec dwm_cs =
    GPIO_DT_SPEC_GET(DT_ALIAS(dwm_cs), gpios);
static const struct gpio_dt_spec dwm_ready =
    GPIO_DT_SPEC_GET(DT_ALIAS(dwm_ready), gpios);

static struct guarded_request_buffer request_tx;
static struct guarded_request_buffer request_discard_rx;
static struct guarded_response_buffer response_clock_tx;
static struct guarded_response_buffer response_rx;

static const struct spi_config spi5_config = {
    .frequency = SPI5_FREQUENCY_HZ,
    .operation = SPI_OP_MODE_MASTER |
                 SPI_WORD_SET(8) |
                 SPI_TRANSFER_MSB,
    .slave = 0,
};

static void initialise_guards(void)
{
    request_tx.pre_guard = GUARD_PRE;
    request_tx.post_guard = GUARD_POST;
    request_discard_rx.pre_guard = GUARD_PRE;
    request_discard_rx.post_guard = GUARD_POST;
    response_clock_tx.pre_guard = GUARD_PRE;
    response_clock_tx.post_guard = GUARD_POST;
    response_rx.pre_guard = GUARD_PRE;
    response_rx.post_guard = GUARD_POST;
}

static int guards_ok(void)
{
    return request_tx.pre_guard == GUARD_PRE &&
           request_tx.post_guard == GUARD_POST &&
           request_discard_rx.pre_guard == GUARD_PRE &&
           request_discard_rx.post_guard == GUARD_POST &&
           response_clock_tx.pre_guard == GUARD_PRE &&
           response_clock_tx.post_guard == GUARD_POST &&
           response_rx.pre_guard == GUARD_PRE &&
           response_rx.post_guard == GUARD_POST;
}

static void print_bytes(const char *label, const uint8_t *data, size_t len)
{
    size_t i;

    printk("%s", label);
    for (i = 0u; i < len; i++) {
        printk("%02x", data[i]);
        if ((i + 1u) < len) {
            printk(" ");
        }
    }
    printk("\n");
}

static int check_gpio_ready(const struct gpio_dt_spec *spec, const char *name)
{
    if (!gpio_is_ready_dt(spec)) {
        printk("ERROR: %s GPIO is not ready\n", name);
        return -ENODEV;
    }

    printk("gpio_ready name=%s controller=%s pin=%u\n",
           name,
           spec->port->name,
           (unsigned int)spec->pin);
    return 0;
}

static int reset_dwm(void)
{
    int ret;

    printk("dwm_reset phase=drive_low duration_ms=%u\n", RESET_LOW_MS);

    ret = gpio_pin_configure(dwm_reset.port, dwm_reset.pin, GPIO_OUTPUT);
    if (ret != 0) {
        return ret;
    }

    gpio_pin_set_raw(dwm_reset.port, dwm_reset.pin, 0);
    k_msleep(RESET_LOW_MS);

    ret = gpio_pin_configure(dwm_reset.port, dwm_reset.pin, GPIO_INPUT);
    if (ret != 0) {
        return ret;
    }

    printk("dwm_reset phase=released_high_z settle_ms=%u\n", RESET_SETTLE_MS);
    k_msleep(RESET_SETTLE_MS);
    return 0;
}

static int wait_ready_level(int expected, uint32_t timeout_ms)
{
    int64_t deadline = k_uptime_get() + timeout_ms;

    do {
        int level = gpio_pin_get_raw(dwm_ready.port, dwm_ready.pin);

        if (level < 0) {
            return level;
        }

        if (level == expected) {
            return 0;
        }

        k_msleep(1);
    } while (k_uptime_get() < deadline);

    return -ETIMEDOUT;
}

static int spi5_manual_cs_transfer(
    const uint8_t *tx,
    uint8_t *rx,
    size_t len)
{
    struct spi_buf tx_buffer = {
        .buf = (void *)tx,
        .len = len,
    };
    struct spi_buf rx_buffer = {
        .buf = rx,
        .len = len,
    };
    const struct spi_buf_set tx_set = {
        .buffers = &tx_buffer,
        .count = 1,
    };
    const struct spi_buf_set rx_set = {
        .buffers = &rx_buffer,
        .count = 1,
    };
    int ret;

    gpio_pin_set_raw(dwm_cs.port, dwm_cs.pin, 0);
    k_usleep(CS_SETUP_US);

    ret = spi_transceive(spi5_dev, &spi5_config, &tx_set, &rx_set);

    k_usleep(CS_HOLD_US);
    gpio_pin_set_raw(dwm_cs.port, dwm_cs.pin, 1);

    return ret;
}

static int parser_sequence_mismatch_self_test(void)
{
    struct tphip_capabilities capabilities;
    struct tphip_response_view response;
    uint8_t frame[TPHIP_RESPONSE_TRANSACTION_LEN];
    enum tphip_validation_result validation;

    tphip_default_capabilities(&capabilities);
    (void)tphip_build_response(
        frame,
        TPHIP_OP_GET_CAPABILITIES,
        2u,
        TPHIP_STATUS_OK,
        &capabilities);

    validation = tphip_validate_response(
        frame,
        sizeof(frame),
        TPHIP_RSP_GET_CAPABILITIES,
        1u,
        &response);

    printk("self_test=sequence_mismatch expected=BAD_SEQUENCE actual=%s result=%s\n",
           tphip_validation_name(validation),
           validation == TPHIP_VALIDATE_BAD_SEQUENCE ? "PASS" : "FAIL");

    return validation == TPHIP_VALIDATE_BAD_SEQUENCE ? 0 : -EINVAL;
}
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

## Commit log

2026-06-15 Add staged UWB responder and initiator firmware harness
2026-06-16 Add engineering log 85 for Stage-1 firmware bring-up
2026-06-16 Create Stage-2 UWB RF proof firmware scaffolds
2026-06-16 Add Stage-2 UWB RF proof notes
2026-06-17 Document Zephyr DW3110 Stage-2 RF bring-up plan
2026-06-17 Document NUCLEO SPI5 Gateway PCB pin mapping
2026-06-17 Document NUCLEO SPI5 GPIO probe app plan
2026-06-27 Mark Gateway rev 0.1 pin map for final verification
2026-06-27 Add minimal Gateway SPI GPIO probe app scaffold
2026-06-28 Add Gateway PCB and node images
2026-07-07 Add NUCLEO GPIO pin-path probe
2026-07-07 Fix GPIO probe devicetree bindings
2026-07-07 Add NUCLEO GPIO probe runtime screenshot
2026-07-07 Add engineering log 91 for NUCLEO GPIO probe
2026-07-07 Add NUCLEO SPI5 dummy-transfer probe
2026-07-07 Set SPI5 dummy probe frequency to 1 MHz
2026-07-08 Stretch SPI5 dummy probe transfer for scope capture
2026-07-09 Add NUCLEO DW3110 register-read probe
2026-07-09 Add engineering log 95 for initial DW3110 register probe
2026-07-09 Refine DW3110 register probe reset and framing
    [main.c]
2026-07-09 Add DWM3001-CDK host interface pin feasibility note
2026-07-09 Record DWM3001-CDK host interface pin audit findings
2026-07-09 Record DWM3001CDK J10 to nRF52833 pin mapping
2026-07-10 Add engineering log 98 for TP6 READY rail-level proof
2026-07-10 Add RTT evidence for TP6 READY rail-level proof
2026-07-11 Implement NUCLEO GET_CAPABILITIES host probe
2026-07-12 Implement DW3110 one-way RF frame proof
2026-07-12 Adapt RF proof to QM33 DW3 driver APIs
2026-07-13 Document third-party material boundaries
2026-07-13 Stage hardware upload payload 01/17
2026-07-13 Stage hardware upload payload 02/17
2026-07-13 Stage hardware upload payload 03/17
2026-07-13 Stage hardware upload payload 04/17
2026-07-13 Stage hardware upload payload 05/17
2026-07-13 Add KiCad source and rev 0.1 fabrication files
    [Thin-Pod Gateway-B_Cu.gbr, Thin-Pod Gateway-B_Mask.gbr, Thin-Pod Gateway-B_Paste.gbr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]
2026-07-13 Update editable-source status after KiCad publication
2026-07-13 Add KiCad ERC and DRC validation reports
2026-07-13 Record Gerber and drill inspection
2026-07-13 Add Gateway CAD provenance record
2026-07-13 Update CAD provenance and dependency boundaries
2026-07-13 Reconcile Gateway BOM with verified assembly
2026-07-16 Record OSHWA certification UK000092
    [Thin-Pod_Gateway_rev0.1_BOM.csv]

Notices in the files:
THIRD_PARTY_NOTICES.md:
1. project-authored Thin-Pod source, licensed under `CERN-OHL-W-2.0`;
